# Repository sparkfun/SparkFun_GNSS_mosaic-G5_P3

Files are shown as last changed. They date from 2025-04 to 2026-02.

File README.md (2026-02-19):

SparkFun Allband GNSS RTK Breakout - mosaic-G5 P3
========================================

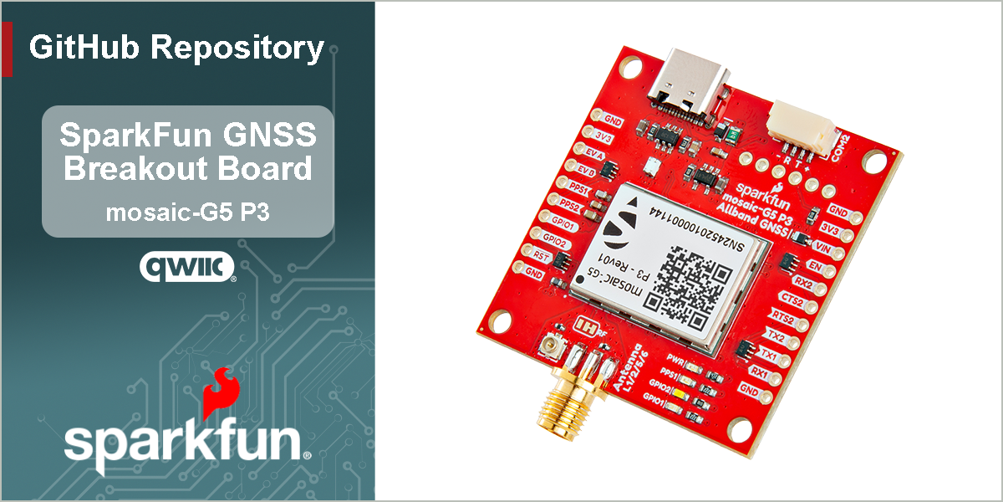
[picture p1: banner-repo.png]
SparkFun Allband GNSS RTK Breakout - mosaic-G5 P3


[*SparkFun Allband GNSS RTK Breakout - mosaic-G5 P3 (GPS-29208)*](https://www.sparkfun.com/sparkfun-allband-gnss-rtk-breakout-mosaic-g5-p3.html)

This SparkFun Allband GNSS RTK Breakout features the Septentrio mosaic-G5 P3 GNSS module, a 60% smaller and 40% lower power consumption variant of the mosaic-X5 GNSS module, making it ideal for drone and IoT applications. The receiver supports the GPS (USA), GLONASS (Russia), Beidou (China), Galileo (Europe), and QZSS (Japan) GNSS constellations, including regional systems *(i.e. SBAS)*. With its Real-Time Kinematics (RTK) capabilities, the module can achieve a horizontal accuracy of 6mm (~0.25in), vertical accuracy of 1cm (~0.4in), PPS timing resolution of 1.4ns (1.4 billionths of a second), and event trigger accuracy below 3ns. It also features Septentrio's unique [AIM+ technology](https://www.septentrio.com/en/learn-more/advanced-positioning-technology/aim-jamming-protection) for interference mitigation and anti-spoofing, ensuring best-in-class reliability and scalable position accuracy.

The mosaic-G5 P3 GNSS module supports USB 2.0 communication and two UART interfaces; along with two GPIO, two configurable PPS outputs, and two event trigger input pins. Users can control and configure the GNSS module through a command-line interface (CLI) using the Septentrio Binary Format (SBF), NMEA, and RTCM v3.x protocols. Otherwise, users can also configure the GNSS module with Septentrio's [RxTools software application](https://www.septentrio.com/en/products/gps-gnss-receiver-software/rxtools). On the board, the `UART2` interface is also broken out to a locking JST connector and BlueSMiRF PTH header pins to attach an RF transceiver for RTK corrections.

Documentation
-------------

- **[Hookup Guide (mkdocs)](http://docs.sparkfun.com/SparkFun_GNSS_mosaic-G5_P3/)** - A hookup guide for the SparkFun mosaic-G5 P3 GNSS breakout board hosted by GitHub pages.<br>
   

Repository Contents
-------------------

- **[/docs](/docs/)** - Online documentation files
  - [/assets](/docs/assets/) - Assets files
    - [/3d_model](/docs/assets/3d_model/) - 3D models for the board
    - [/board_files](/docs/assets/board_files/) - Design files for the board
      - [KiCad Design Files](/docs/assets/board_files/kicad_files.zip) (.zip)
      - [Schematic](/docs/assets/board_files/schematic.pdf) (.pdf)
      - [Dimensions](/docs/assets/board_files/dimensions.pdf) (.pdf)
    - [/component_documentation](/docs/assets/component_documentation/) - Datasheets for hardware components
    - [/img/hookup_guide](/docs/assets/img/hookup_guide/) - Images for hookup guide documentation - Hookup guide images for the board
    - /Hardware - Hardware design files (.brd, .sch)
      - /Production - Production files

Product Variants
----------------

- mosaic-G5 P3:
  - [GPS-29208](https://www.sparkfun.com/sparkfun-allband-gnss-rtk-breakout-mosaic-g5-p3.html) - Allband GNSS RTK Breakout - mosaic-G5 P3
  - Flex Modules:
    - [GPS-29209](https://www.sparkfun.com/sparkpnt-gnss-flex-module-mosaic-g5-p3.html) - GNSS Flex module - mosaic-G5 P3
    - [GPS-29363](https://www.sparkfun.com/sparkpnt-gnss-flex-module-mosaic-g5-p3-im19-imu.html) - GNSS Flex module - mosaic-G5 P3 & IM19
    - [GPS-](https://www.sparkfun.com/sparkfun-gnss-flex-phat-mosaic-g5-p3.html) - GNSS Flex pHAT w/ the mosaic-G5 P3 GNSS Flex module
    - [GPS-](https://www.sparkfun.com/sparkfun-gnss-flex-phat-mosaic-g5-p3-im19-imu.html) - GNSS Flex pHAT w/ the mosaic-G5 P3 & IM19 GNSS Flex module
- mosaic-X5:
  - [GPS-23088](https://www.sparkfun.com/sparkfun-triband-gnss-rtk-breakout-mosaic-x5.html) - Triband GNSS RTK Breakout - mosaic-X5
  - [GPS-23748](https://www.sparkfun.com/sparkfun-rtk-mosaic-x5.html) - RTK mosaic-X5
  - [GPS-24903](https://www.sparkfun.com/sparkpnt-rtk-facet-mosaic-l-band.html) - SparkPNT RTK Facet mosaic L-Band
  - Flex Modules:
    - [GPS-28138](https://www.sparkfun.com/sparkpnt-gnss-flex-module-mosaic-x5.html) - GNSS Flex module - mosaic-X5
    - [GPS-29457](https://www.sparkfun.com/sparkpnt-gnss-flex-module-mosaic-x5-im19-imu.html) - GNSS Flex module - mosaic-X5 & IM19
    - [GPS-28766](https://www.sparkfun.com/sparkfun-gnss-flex-phat-mosaic-x5.html) - GNSS Flex pHAT w/ the mosaic-X5 GNSS Flex module
    - [GPS-29889](https://www.sparkfun.com/sparkfun-gnss-flex-phat-mosaic-x5-im19-imu.html) - GNSS Flex pHAT w/ the mosaic-X5 & IM19 GNSS Flex module
- mosaic-T:
  - [GPS-28731](https://www.sparkfun.com/sparkfun-timing-gnss-breakout-mosaic-t.html) - mosaic-T Timing GNSS Breakout
  - [GPS-26289](https://www.sparkfun.com/sparkpnt-gnss-disciplined-oscillator.html) - GNSS Disciplined Oscillator

| | mosaic-G5 P3 | mosaic-X5 | mosaic-T |
| :--- | :--- | :--- | :--- |
| Breakout Board | [GPS-29208](https://www.sparkfun.com/sparkfun-allband-gnss-rtk-breakout-mosaic-g5-p3.html) | [GPS-23088](https://www.sparkfun.com/sparkfun-triband-gnss-rtk-breakout-mosaic-x5.html) | [GPS-28731](https://www.sparkfun.com/sparkfun-timing-gnss-breakout-mosaic-t.html) |
| GNSS Flex Module | [GPS-29209](https://www.sparkfun.com/sparkpnt-gnss-flex-module-mosaic-g5-p3.html)<br>[GPS-30384](https://www.sparkfun.com/sparkfun-gnss-flex-phat-mosaic-g5-p3.html) - pHAT Kit | [GPS-28138](https://www.sparkfun.com/sparkpnt-gnss-flex-module-mosaic-x5.html)<br>[GPS-28766](https://www.sparkfun.com/sparkfun-gnss-flex-phat-mosaic-x5.html) - pHAT Kit | N/A |
| GNSS Flex Module w/ IM19 | [GPS-29363](https://www.sparkfun.com/sparkpnt-gnss-flex-module-mosaic-g5-p3-im19-imu.html)<br>[GPS-30546](https://www.sparkfun.com/sparkfun-gnss-flex-phat-mosaic-g5-p3-im19-imu.html) - pHAT Kit | [GPS-29457](https://www.sparkfun.com/sparkpnt-gnss-flex-module-mosaic-x5-im19-imu.html)<br>[GPS-29889](https://www.sparkfun.com/sparkfun-gnss-flex-phat-mosaic-x5-im19-imu.html) - pHAT Kit | N/A |
| Other | N/A | [GPS-23748](https://www.sparkfun.com/sparkfun-rtk-mosaic-x5.html) - RTK Platform<br>[GPS-24903](https://www.sparkfun.com/sparkpnt-rtk-facet-mosaic-l-band.html) - Facet | [GPS-26289](https://www.sparkfun.com/sparkpnt-gnss-disciplined-oscillator.html) - GNSSDO |

Version History
---------------

- [v10](https://github.com/sparkfun/SparkFun_GNSS_mosaic-G5_P3/releases/tag/v10) - Initial Release

License Information
-------------------

This product is ***open source***!

Please review the [`LICENSE.md`](./LICENSE.md) file for license information.

If you have any questions or concerns about licensing, please contact technical support on our [SparkFun forums](https://community.sparkfun.com/).

Distributed as-is; no warranty is given.

- Your friends at SparkFun.

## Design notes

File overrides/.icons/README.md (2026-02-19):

.icons directory
====================
This folder should contain branding logos for the product documentation

## General Images
- `sfe.svg` - SparkFun flame logo
- `kicad-primary.svg` - Full KiCad logo

## Directory
- `logo` - Other available logos

## SVG Optimizer
- [Remove meta data from svg](https://jakearchibald.github.io/svgomg/)

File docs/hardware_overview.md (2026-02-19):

??? danger "Important: Read Before Use!"
	!!! warning "ESD Sensitivity"
		The mosaic-G5 P3 GNSS receiver is sensitive to [ESD](https://en.wikipedia.org/wiki/Electrostatic_discharge "Electrostatic Discharge"). Use a proper grounding system to make sure that the working surface and the components are at the same electric potential.

		??? info
			As recommended by the manufacturer, we highly recommend that users take the necessary precautions to avoid damaging their GNSS receiver.

			- The All-band GNSS RTK breakout board features ESD protection on the USB-C connector and breakout's I/O:
				- USB data lines
				- I/O PTH pads
				- JST connector and BlueSMiRF header pins
			- The mosaic-G5 P3 GNSS receiver features internal ESD protection to the `ANT_1` antenna input.

			<div markdown>

			<article class="video-500px" style="margin: auto;" markdown>
			<iframe src="https://www.youtube.com/embed/hrL5J6Q5gX8?si=jOPBat8rzMnL7Uz4&amp;start=26;&amp;end=35;" title="Septentrio: Getting Started Video (playback starts at ESD warning)" frameborder="0" allow="accelerometer; autoplay; clipboard-write; encrypted-media; gyroscope; picture-in-picture" allowfullscreen></iframe>
			</article>

			</div>

	!!! warning "Active Antenna"
		Never inject an external DC voltage into the SMA connector for the GNSS antenna, as it may damage the mosaic-G5 P3 GNSS receiver. For instance, when using a splitter to distribute the antenna signal to several GNSS receivers, make sure that no more than one output of the splitter passes DC. Use [DC-blocks](https://en.wikipedia.org/wiki/DC_block) otherwise.

## :material-folder-cog: Design Files
<!-- Import the component -->
<script type="module" src="https://ajax.googleapis.com/ajax/libs/model-viewer/3.5.0/model-viewer.min.js"></script>

<div class="grid cards desc" markdown>

-   :kicad-primary:{ .enlarge-logo } Design Files

	---

	- :fontawesome-solid-file-pdf: [Schematic](./assets/board_files/schematic.pdf)
	- :material-folder-zip: [KiCad Files](./assets/board_files/kicad_files.zip)
	- :material-rotate-3d: [STEP File](./assets/3d_model/cad_model.step)
	- :fontawesome-solid-file-pdf: [Board Dimensions](./assets/board_files/dimensions.pdf):
		- 1.70" x 1.70" (43.2mm x 43.2mm)

-   <!-- Boxes in tabs -->

	=== "3D Model"
		<article style="text-align: center;" markdown>
		<model-viewer src="../assets/3d_model/web_model.glb" camera-controls poster="../assets/3d_model/poster.png" tone-mapping="neutral" shadow-intensity="2" shadow-softness="0.2" camera-orbit="0deg 75deg 0.103m" field-of-view="25.11deg" style="width: 100%; height: 450px;">
		</model-viewer>

		[Download the `*.step` File](./assets/3d_model/cad_model.step "Click download"){ .md-button .md-button--primary width="250px" }

		</article>

		???+ tip "Manipulate 3D Model"
			<article style="text-align: center;" markdown>

			| Controls       | Mouse                    | Touchscreen    |
			| :------------- | :----------------------: | :------------: |
			| Zoom           | Scroll Wheel             | 2-Finger Pinch |
			| Rotate         | ++"Left-Click"++ & Drag  | 1-Finger Drag  |
			| Move/Translate | ++"Right-Click"++ & Drag | 2-Finger Drag  |

			</article>

	=== "Dimensions"
		<article style="text-align: center;" markdown>
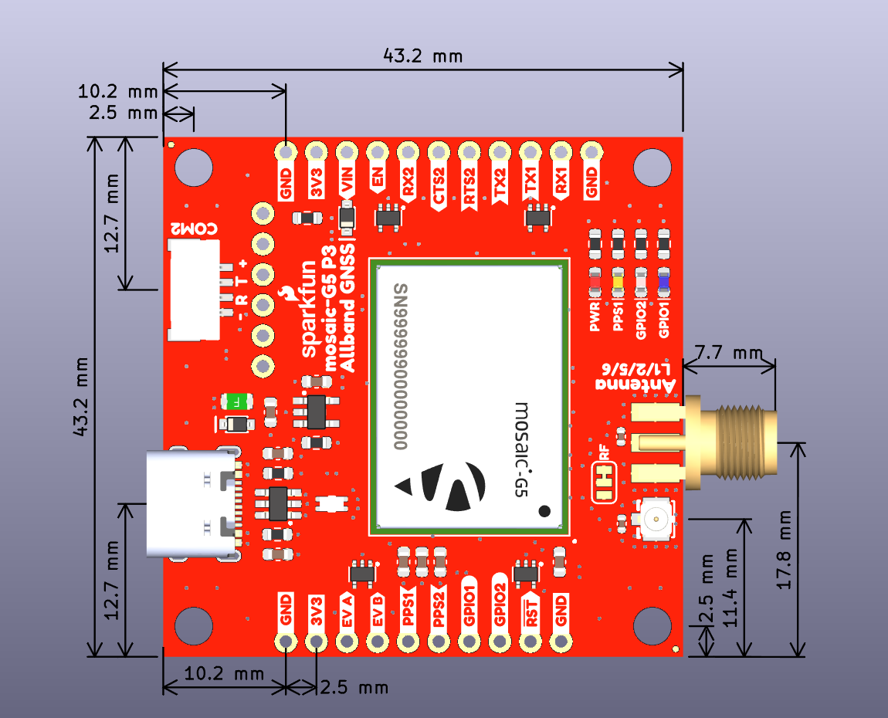
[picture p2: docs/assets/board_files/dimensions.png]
Board Dimensions
		
		<figcaption markdown>Dimensions of the mosaic-G5 P3 GNSS breakout board.</figcaption>
		</article>

		???+ tip "Need more measurements?"
			For more information about the board's dimensions, users can download the [KiCad files](./assets/board_files/kicad_files.zip) for this board. These files can be opened in KiCad and additional measurements can be made with the measuring tool.

			!!! info ":octicons-download-16:{ .heart } KiCad - Free Download!"
				KiCad is free, open-source [CAD]("computer-aided design") program for electronics. Click on the button below to download their software. *(\*Users can find out more information about KiCad from their [website](https://www.kicad.org/).)*

				<article style="text-align: center;" markdown>
				[Download :kicad-primary:{ .enlarge-logo }](https://www.kicad.org/download/ "Go to downloads page"){ .md-button .md-button--primary width="250px" }
				</article>

			???+ info ":straight_ruler: Measuring Tool"
				This video demonstrates how to utilize the dimensions tool in KiCad, to include additional measurements:

				<article class="video-500px" style="text-align: center; margin: auto;" markdown>
				<iframe src="https://www.youtube.com/embed/-eXuD8pkCYw" title="KiCad Dimension Tool" frameborder="0" allow="accelerometer; autoplay; clipboard-write; encrypted-media; gyroscope; picture-in-picture" allowfullscreen></iframe>
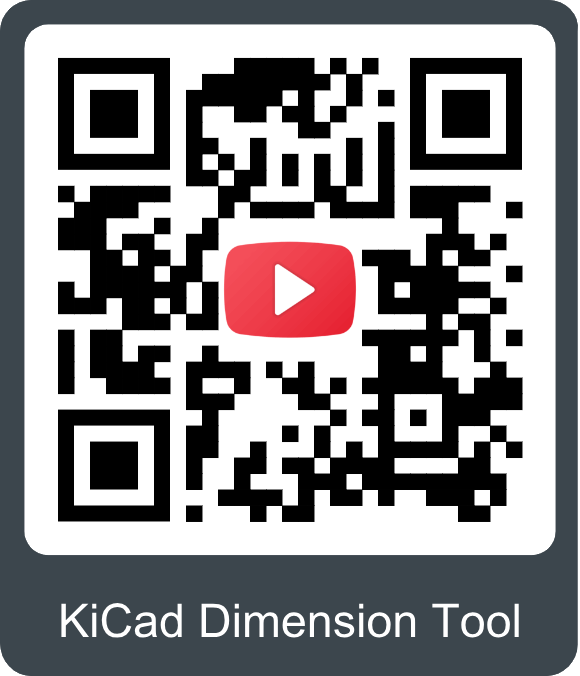
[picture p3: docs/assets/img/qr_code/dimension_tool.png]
QR code to play video
				
				</article>

</div>

## Board Layout
The SparkFun Allband GNSS RTK Breakout - mosaic-G5 P3 features the following:

<div class="grid" markdown>

<div markdown>

<figure markdown>
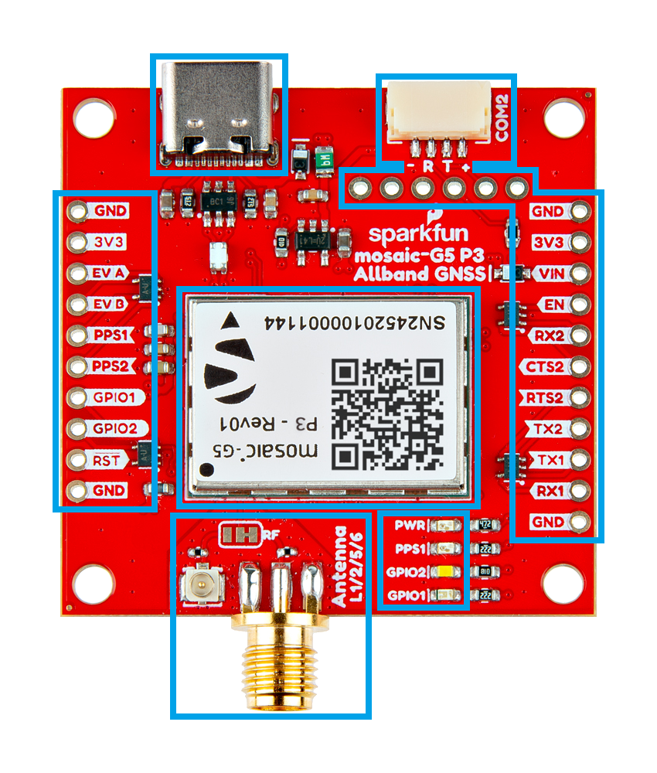
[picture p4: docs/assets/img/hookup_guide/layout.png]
Layout

<figcaption markdown>Layout of the major components on the breakout board.</figcaption>
</figure>

</div>

<div markdown>

1. **[USB-C Connector](#usb-c-connector)**
:   The primary inteface for powering and interacting with the board
1. **[mosaic-G5 P3 GNSS Receiver](#mosaic-g5-p3)**
:   The Septentrio mosaic-G5 P3 GNSS receiver
1. **Header Pins**
:   Exposes pins to [power the board](#power) and breaks out the [interfaces of the mosaic-G5 P3 GNSS receiver](#peripherals-and-io-pins)
1. **[BlueSMiRF Header Pins](#bluesmirf-header)**
:   Exposes the `UART2` interface of the mosaic-G5 P3 GNSS receiver
1. **[JST Connector](#jst-connector)**
:   Exposes the `UART2` interface of the mosaic-G5 P3 GNSS receiver
1. **[Status LEDs](#status-leds)**
:   LED status indicators for the mosaic-G5 P3 GNSS receiver
1. **[`Antenna L1/2/5/6` RF Connectors](#antenna-connections)**
:   SMA and U.FL *(optional)* connectors for an external GNSS antenna

</div>

</div>

## USB-C Connector
The USB connector is provided to power and interface with the mosaic-G5 P3 GNSS receiver. For most users, it will be the primary method for communicating with the GNSS receiver.

<figure markdown>
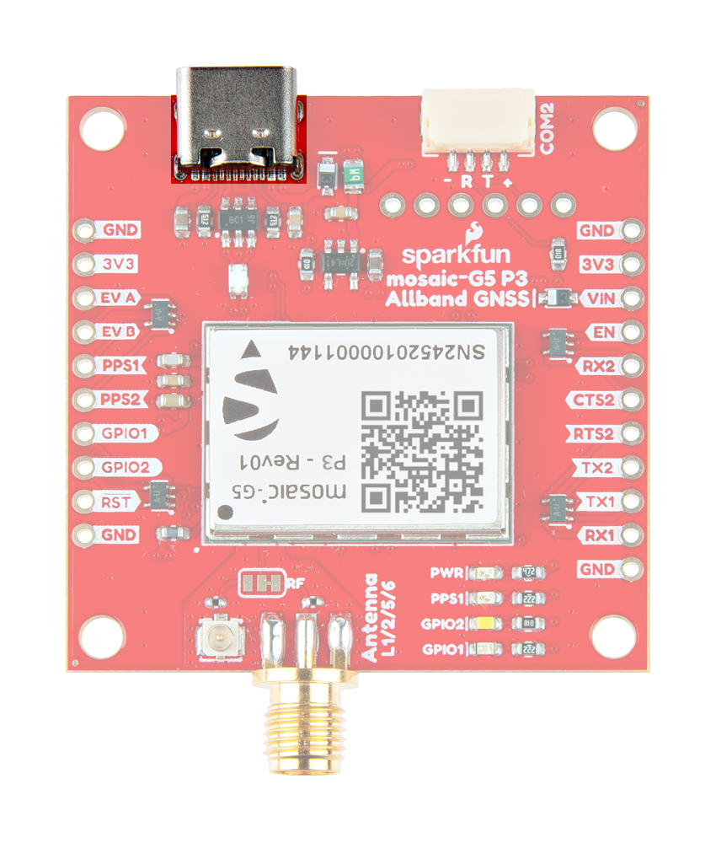
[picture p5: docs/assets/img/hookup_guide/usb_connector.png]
USB-C Connector

<figcaption markdown>USB-C connector on the All-band GNSS RTK breakout board.</figcaption>
</figure>

## Power
The All-band GNSS RTK breakout board only requires **3.3V** to power all of the board's components. The simplest method to power the board is through the USB-C connector. Alternatively, the board can also be powered through the **`VIN`** pin.

<figure markdown>
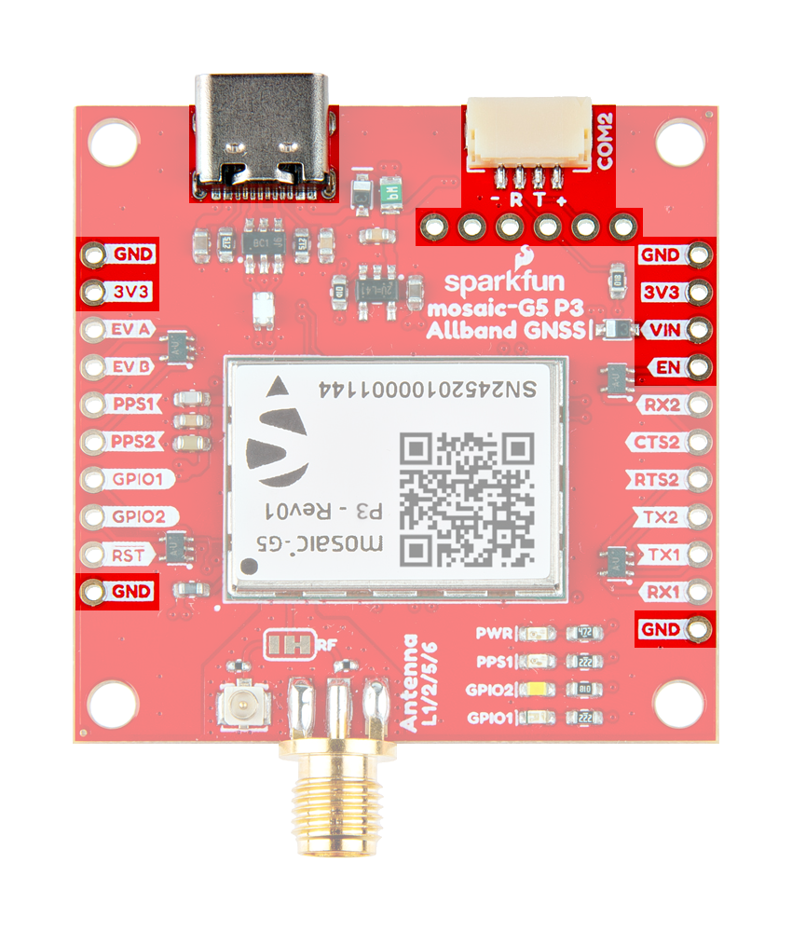
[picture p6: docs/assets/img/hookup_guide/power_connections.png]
Power connections

<figcaption markdown>All-band GNSS RTK breakout board's power connections.</figcaption>
</figure>

Below, is a general summary of the power circuitry on the board, broken out as [PTH](https://en.wikipedia.org/wiki/Through-hole_technology "Plated Through Holes") pins:

<div class="annotate" markdown>

- **`VUSB`** - The voltage from the USB-C connector, usually **5V**
	- Input Voltage Range: 4.4 - 5.5 V
	- Power source for the entire board
		- Powers the 3.3V voltage regulator (RT9080), which can source up to 600mA
		- When enabled, it can also power the [BlueSMiRF header](#bluesmirf-header) and [JST connector](#jst-connector) *(see the **[Jumpers](#jumpers)** section)*
- **`VIN`** - Alternate input supply voltage for the board
	- Input Voltage Range: 1.2 - 5.5V (1)
	- Power source for the entire board
		- Powers the 3.3V voltage regulator (RT9080), which can source up to 600mA
		- When enabled, it can also power the [BlueSMiRF header](#bluesmirf-header) and [JST connector](#jst-connector) *(see the **[Jumpers](#jumpers)** section)*
- **`3V3`** - Provides a regulated 3.3V from the [RT9080](./assets/component_documentation/RT9080.pdf), using the power supplied from the `VIN` pin or USB-C connector
	- Used to power the mosaic-G5 P3 GNSS receiver and its active antenna preamplifier, the LEDs, and the power pin of the [JST connector](#jst-connector) and [BlueSMiRF header](#bluesmirf-header)
	- Controlled by the `EN` pin, which is enabled by default
- **`EN`** - Enables the voltage output from the [RT9080](./assets/component_documentation/RT9080.pdf), 3.3V voltage regulator
	- Enabled by default *(active `HIGH`)*
- **`RST`** - Used to reset the mosaic-G5 P3 GNSS receiver
	- Connected to the `nRST_IN` input-only pin with an internal pull-up resistor
	- Driving the pin `LOW` triggers the restart of the mosaic-G5 P3 GNSS receiver
- **`GND`** - The common ground or the 0V reference for the voltage supplies.

</div>

1. While the [RT9080](./assets/component_documentation/RT9080.pdf) LDO regulator has an input voltage range of 1.2 - 5.5V, a minimum supply voltage of **3.5V** is recommended for a 3.3V output.

!!! tip "JST Connector"
	The `VSEL` pin of the [BlueSMiRF header](#bluesmirf-header) and `+` pin of the [JST connector](#jst-connector) are designed to operate as a voltage output. An input voltage can be supplied through these pins; however, users should be mindful of any voltage contention issues. Additionally, users can modify the [`VSEL` jumper](#jumpers) to change the output voltage level of these pins.

!!! info
	For more details, users can reference the [schematic](./assets/board_files/schematic.pdf) and the datasheets of the individual components on the board.

### Power Consumption
The power consumption of the mosaic-G5 P3 GNSS receiver depends on the GNSS signals enabled and the positioning mode. The table below, lists the average power consumption for common configurations. The current listed, is based on a supply voltage of 3.3V.

<article style="text-align: center;" markdown>

| GNSS Signals | Power (mW) | Current (mA) |
| :--- | :---: | :---: |
| GPS/GLONASS L1/L2 | 440 | 133 |
| All signals from all GNSS constellations | 570 | 173 |
| All signals from all GNSS constellations +L-band | 670 | 203 |

*Source: [mosaic-G5 P3 Hardware Manual](./assets/component_documentation/mosaic-g5_hardware_manual_v1.1.1.pdf)*
</article>

## :fontawesome-solid-microchip:&nbsp; mosaic-G5 P3
The centerpiece of the All-band GNSS RTK breakout board, is the [mosaic-G5 P3 GNSS receiver](./assets/component_documentation/mosaic-g5_hardware_manual_v1.1.1.pdf) from [Septentrio](https://www.septentrio.com/en). Their mosaic-G5 P3 modules are low-power, multi-band, multi-constellation GNSS receivers capable of delivering centimeter-level precision in a small form factor without compromising on performance. They provide strong positioning reliability in challenging environments and are tailored for applications such as delivery or light show drones. It also features Septentrio's unique [AIM+ technology](https://www.septentrio.com/en/learn-more/advanced-positioning-technology/aim-resilient-and-secure-gnss/gps-receivers) for interference mitigation and anti-spoofing, which ensures their best-in-class reliability and scalable position accuracy.

<div class="grid cards" markdown>

<div markdown>

<article class="video-500px" style="margin: auto;" markdown>
<iframe src="https://www.youtube.com/embed/3VzVxTTvF5Q" title="Septentrio mosaic range: high-accuracy GNSS receivers for drones &amp; robotics" frameborder="0" allow="accelerometer; autoplay; clipboard-write; encrypted-media; gyroscope; picture-in-picture" allowfullscreen></iframe>
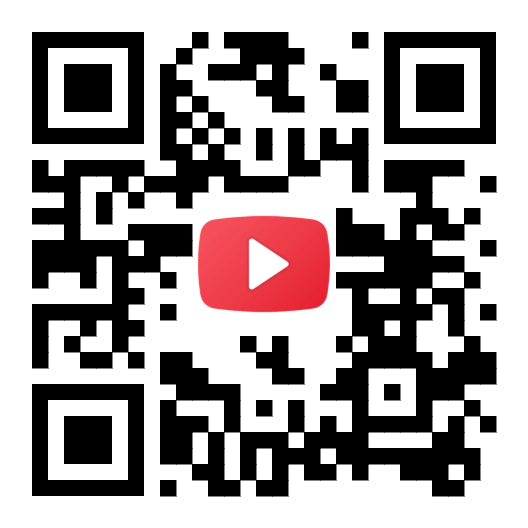
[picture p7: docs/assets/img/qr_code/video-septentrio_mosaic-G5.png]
QR code to play video

</article>

</div>

-   <figure markdown>
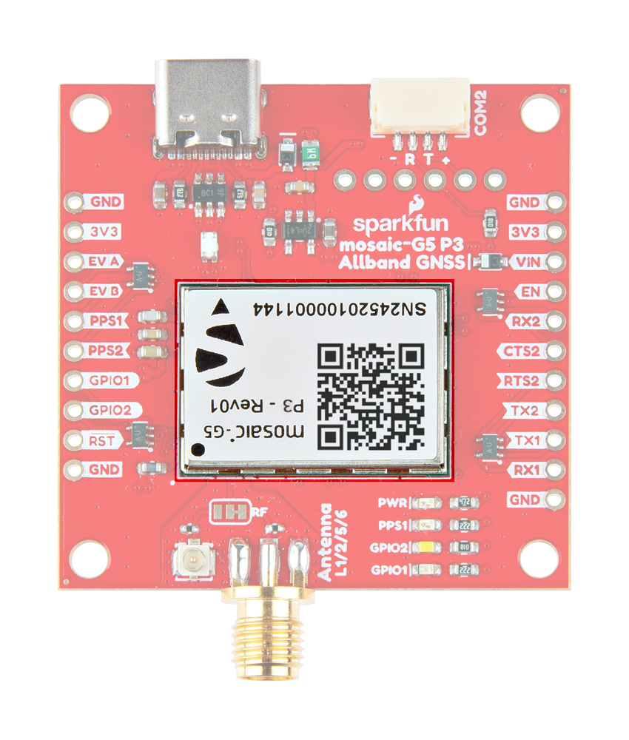
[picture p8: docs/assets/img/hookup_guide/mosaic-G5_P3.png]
mosaic-G5 P3 GNSS receiver
	
	<figcaption markdown>The mosaic-G5 P3 GNSS receiver on the All-band GNSS RTK breakout board.</figcaption>
	</figure>

</div>

<div class="grid" markdown>

<div markdown>

**Features:**

- Operating Voltage: **3.135 - 3.465V**
- GNSS Support
	- GPS: `L1C/A`, `L1C`, `L2C`, `L2PY`, `L5`
	- GLONASS: `L1CA`, `L2CA`, `L2P`, `L3 CDMA`
	- Beidou: `B1I`, `B1C`, `B2a`, `B2b`, `B2I`, `B3I`
	- Galileo: `E1`, `E5a`, `E5b`, `E6`
	- QZSS: `L1C/A`, `L1 C/B`, `L2C`, `L5`, `L6`
- Time to Fix
	- Cold Start: < 35s
	- Warm: < 10s
	- Reacquisition: 1s
- Position Accuracy
	<article style="text-align: center;" markdown>

	| Correction | Horizontal                             | Vertical                     |
	| :--------- | :------------------------------------: | :--------------------------: |
	| RTK        | **0.6cm** *(&plusmn;0.5ppm)*<br>~0.25" | 1cm *(&plusmn;1ppm)*<br>~.4" |
	| DGNSS      | 40cm<br>~1.3'                          | 70cm<br>~2.3'                |
	| Standalone | 1.2m<br>~4'                            | 1.9m<br>~6.2'                |

	</article>

</div>

<div markdown>

<br>

- Update Rate: 20Hz
- Latency: < 10ms
- Event Accuracy: < 3ns
- Interfaces:
	- UART (x2)
	- USB device (2.0, HS)
	- GPIO user programmable (x2)
	- Event markers (x2)
	- Configurable PPS out (x2)
- Protocols:
	- Septentrio Binary Format (SBF)
	- NMEA 0183, v2.3, v3.03, V4.0
	- RTCM v3.x (MSM included)
- Antenna Specifications
	- Preamplification Range: 15-50dB
	- Bias Voltage: 3.0 - 5.5V
	- 789 Hardware Channels
- Operating Temperature: -40 - 85&deg;C
- Package Size: 16.4mm x 22.8mm x 2.4mm
- Weight: 2.2g

</div>

</div>

!!! tip
	The capabilities of each receiver is defined by a the optional features that are enabled. The capabilities of the receiver depend on a combination of the hardware model and version, the firmware version, and the set of permissions enabled for the optional features. Permissions are further explained in section 1.17. The command `getReceiverCapabilities` will list the receiver's capabilities. Otherwise, using RxControl (go to **Help** > **Receiver Interface** > **Permitted Capabilities**).

### Frequency Bands
The mosaic GNSS receivers are multi-band, multi-constellation GNSS receivers. Below, are charts illustrating the frequency bands utilized by all the global navigation satellite systems and the ones supported by the mosaic-G5 P3 GNSS receiver.

<figure markdown>
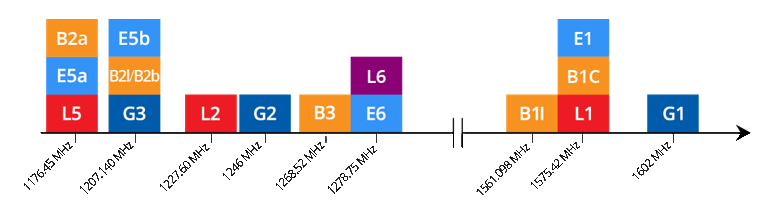
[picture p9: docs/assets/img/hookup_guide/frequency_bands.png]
Supported frequency bands

<figcaption markdown>The frequency bands supported by the mosaic-G5 P3 GNSS receiver.</figcaption>
</figure>

<figure markdown>
GNSS frequency bands (https://www.tallysman.com/app/uploads/2021/07/Tallysman-GNSS-Frequencies-v8.0_Chart-1-1024x425.png "Click to enlarge")
<figcaption markdown>Frequency bands of the global navigation satellite systems. (Source: [Tallysman](https://www.tallysman.com/gnss-constellations-radio-frequencies-and-signals/))</figcaption>
</figure>

!!! info
	For a comparison of the frequency bands supported by the mosaic GNSS receivers, refer to section **3.1** of the [hardware manual](./assets/component_documentation/mosaic-g5_hardware_manual_v1.1.1.pdf).

	??? info "What are Frequency Bands?"
		A [frequency band](https://en.wikipedia.org/wiki/Frequency_band) is a section of the [electromagnetic spectrum](https://en.wikipedia.org/wiki/Electromagnetic_spectrum), usually denoted by the range of its upper and lower limits. In the [radio spectrum](https://en.wikipedia.org/wiki/Radio_spectrum), these frequency bands are usually regulated by region, often through a government entity. This regulation prevents the interference of RF communication; and often includes major penalties for any interference with critical infrastructure systems and emergency services.

		<figure markdown>
		GNSS frequency bands (https://gssc.esa.int/navipedia/images/c/cf/GNSS_All_Signals.png "Click to enlarge")
		<figcaption markdown>Frequency bands of the global navigation satellite systems. (Source: [ESA](https://gssc.esa.int/navipedia/index.php?title=File:GNSS_All_Signals.png "European Space Agency"))</figcaption>
		</figure>

		However, if the various GNSS constellations share similar frequency bands, then how do they avoid interfering with one another? Without going too far into detail, the image above illustrates the frequency bands of each system with a few characteristics specific to their signals. Wit these characteristics in mind, along with other factors, the chart can help users to visualize how multiple GNSS constellations might co-exist with each other.

		For more information, users may find these articles of interest:

		- [GNSS signal](https://gssc.esa.int/navipedia/index.php/GNSS_signal)
		- [GPS Signal Plan](https://gssc.esa.int/navipedia/index.php?title=GPS_Signal_Plan)
		- [GLONASS Signal Plan](https://gssc.esa.int/navipedia/index.php?title=GLONASS_Signal_Plan)
		- [GALILEO Signal Plan](https://gssc.esa.int/navipedia/index.php?title=GALILEO_Signal_Plan)

### Position Accuracy
<div class="grid" markdown>

<div markdown>

The accuracy of the position reported from the mosaic-G5 P3 GNSS receiver, can be improved based upon the correction method being employed. Currently, [RTK](https://en.wikipedia.org/wiki/Real-time_kinematic_positioning "Real-Time Kinematic") corrections provide the highest level of accuracy; however, users should be aware of certain limitations of the system:

- RTK technique requires real-time correction data from a reference station or network of base stations.
	- RTK corrections are signal specific *(i.e. an RTK network might provide corrections on only `E5b` and not `E5a`)*.
- The range of the base stations will vary based upon the RTK method being employed.
- The reliability of RTK corrections are inherently reduced in [multipath environments](https://en.wikipedia.org/wiki/Multipath_propagation). However, with Septentrio's multipath mitigation technology ([APME+](https://www.septentrio.com/en/learn-more/Advanced-positioning-technology/gnss-technology/multipath-mitigation-technology "A-Posteriori Multipath Estimation")) on the mosaic-G5 P3, these errors are significantly reduced when compared to multipath mitigation techniques that modify the correlators in the tracking channels.

</div>

<div markdown>

<article style="text-align: center;" markdown>

| Correction | Horizontal | Vertical |
| :--- | :---: | :---: |
| [RTK](https://en.wikipedia.org/wiki/Real-time_kinematic_positioning "Real-Time Kinematic") | **0.6cm** *(&plusmn;0.5ppm)*<br>~0.25" | 1cm *(&plusmn;1ppm)*<br>~.4" |
| [DGNSS](https://en.wikipedia.org/wiki/Differential_GPS "Differential GNSS") | 40cm<br>~1.3' | 70cm<br>~2.3' |
| Standalone | 1.2m<br>~4' | 1.9m<br>~6.2' |

</article>

</div>

</div>

??? info "RTK Corrections"
	To understand how RTK works, users will need a more fundamental understanding of the signal error sources.

	<div class="grid cards" markdown align="center">

	-   <a href="https://www.sparkfun.com/news/7533">
		<figure markdown>
		Tutorial Thumbnail
		</figure>

		---

		**Real-Time Kinematics Explained**</a>

	-   <a href="https://www.sparkfun.com/news/7138">
		<figure markdown>
		Tutorial Thumbnail
		</figure>

		---

		**What is Correction Data?**</a>

	-   <a href="https://www.septentrio.com/en/learn-more/insights/gnss-corrections-demystified">
		<figure markdown>
		Tutorial Thumbnail
		</figure>

		---

		**GNSS Corrections Demystified**</a>

	</div>

!!! tip
	For the best performance, we highly recommend that users configure the GNSS receiver to utilize/provide RTK corrections with a compatible L1/L2/L5/L6 (All-band) GNSS antenna and utilize a low-loss cable.

## Peripherals and I/O Pins
The mosaic-G5 P3 features several peripherals and I/O pins. Some of these are broken out as pins on the All-band GNSS RTK breakout board; whereas, others are broken out to their specific interface *(i.e. USB connector, etc.)*. Additionally, some of their connections are tied to other components on the board.

<div class="grid" markdown>

<div markdown>

<figure markdown>
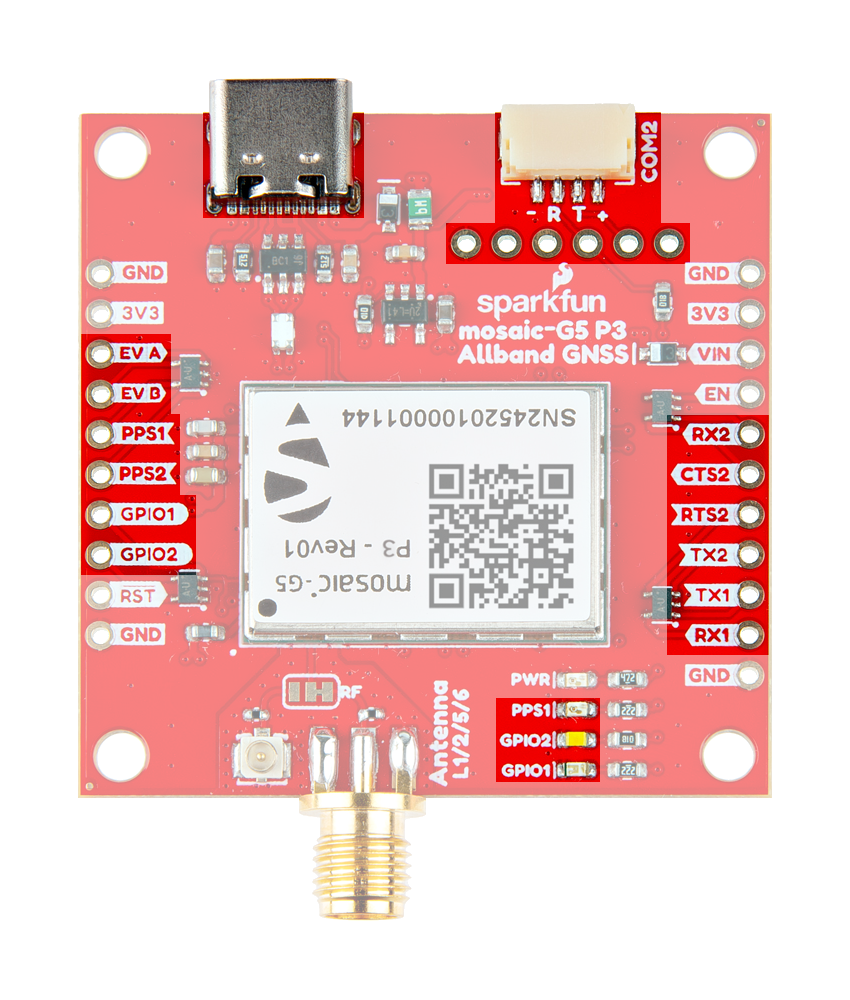
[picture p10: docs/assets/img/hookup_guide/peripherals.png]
Peripherals and I/O pins

<figcaption markdown>The peripherals and I/O pins on the All-band GNSS RTK breakout board.</figcaption>
</figure>

</div>

<article class="annotate" markdown>
**Interfaces:**

- USB device (2.0, HS)
- 2x UART (LVTTL, up to 4 Mbps)
- 2x GPIO user programmable
- 2x Event markers
- 2x Configurable PPS out

</article>

</div>

=== "USB"
	For most users, this will be the primary interface for the mosaic-G5 P3 GNSS receiver.

	<figure markdown>
	USB interface
	<figcaption markdown>USB-C connector on the All-band GNSS RTK breakout board.</figcaption>
	</figure>

	!!! info
		When a GNSS receiver is initially connected to a computer, two virtual `COM` ports are emulated. These can be used as standard `COM` ports to communicate with the GNSS receiver.

=== "UARTs"
	The mosaic-G5 P3 has two dedicated UART interfaces. Each of the UART ports can be configured and operated separately.

	<div class="grid" markdown>

	<div markdown>

	<figure markdown>
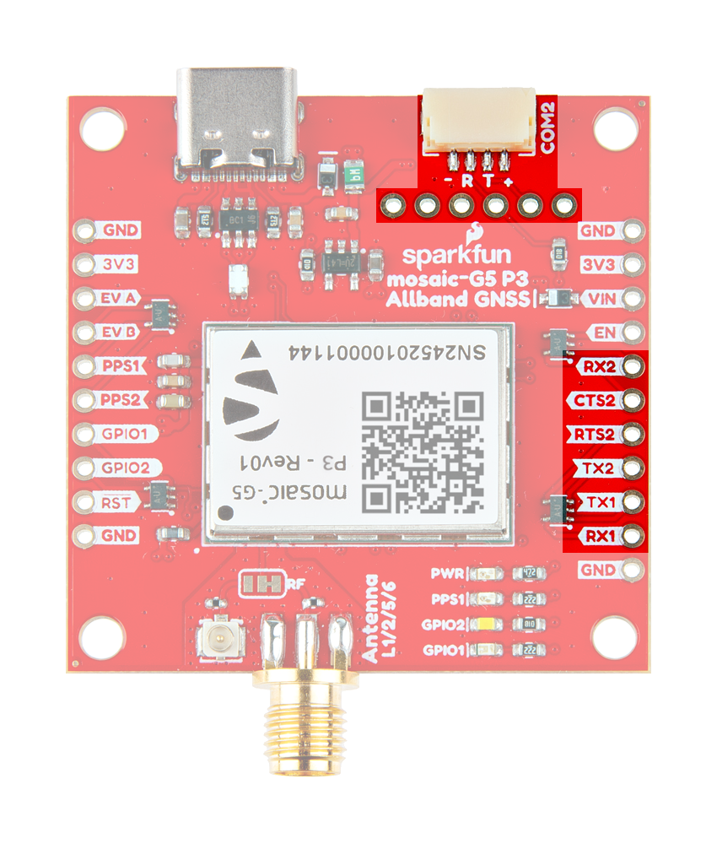
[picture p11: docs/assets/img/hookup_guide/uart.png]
UART interface
	
	<figcaption markdown>The UART ports on the All-band GNSS RTK breakout board.</figcaption>
	</figure>

	</div>

	<div markdown>

	!!! info
		By default, the UART ports are configured with the following settings:

		- Baudrate: 115200bps
		- Data Bits: 8
		- Parity: No
		- Stop Bits: 1
		- Flow Control: None

		The COM port settings are set with the `setCOMSettings` command.

		!!! tip "`UART2`"
			The `UART2` or `COM2` interface features flow control pins, which are disabled by default. The interface can also be accessed through the [JST connector](#jst-connector) and/or [BlueSMiRF header](#bluesmirf-header).

			!!! warning "Bus Contention"
				To avoid [bus contention](https://en.wikipedia.org/wiki/Bus_contention) issues, make sure only one device is connected to any of these options.

	</div>

	</div>

	??? tip "Pin Connections"
		When connecting to the board's UART pins, the pins should be connected based upon the flow of their data. For example, when utilizing the [Telemetry Radio](https://www.sparkfun.com/sik-telemetry-radio-v3-915mhz-100mw.html) or the [LoRaSerial Kit](https://www.sparkfun.com/sparkfun-loraserial-kit-915mhz-enclosed.html):

		<figure markdown>
		Flow Control (https://docs.sparkfun.com/SparkFun_LoRaSerial/img/SAMD21%20Flow%20control.png "Click to enlarge")
		<figcaption markdown>Connection of the UART pins from the [LoRaSerial radio](https://www.sparkfun.com/sparkfun-loraserial-kit-915mhz-enclosed.html) to a host system, like the All-band GNSS RTK breakout board.</figcaption>
		</figure>

=== "PPS Output"
	The 3.3V [PPS](https://en.wikipedia.org/wiki/Pulse-per-second_signal "Pulse Per Second") signals can be access through the `PPSx` pins. The polarity, frequency, and pulse width of these signals can be configured with the `setPPSParameters` and `setPPS2Parameters` commands.

	<div class="grid" markdown>

	<div markdown>

	<figure markdown>
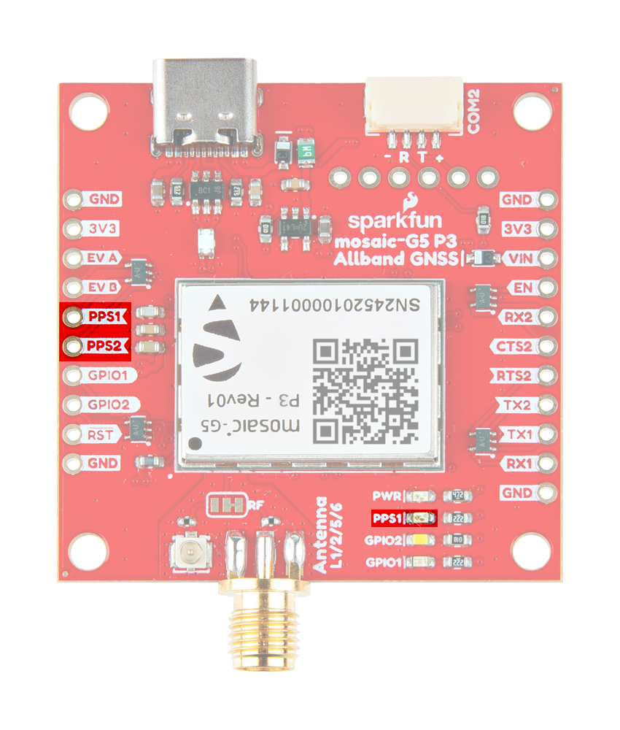
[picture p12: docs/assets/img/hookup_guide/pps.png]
I/O for PPS signal
	
	<figcaption markdown>The `PPS` signal outputs on the All-band GNSS RTK breakout board.</figcaption>
	</figure>

	</div>

	<div markdown>

	!!! info
		During module startup, these pins are first in high-Z mode for about 1s. Then they are driven low for another second before being driven to the intended user-selected level about 2s after powering up the module.

	!!! tip "GPIO Pins"
		It is possible to use these pins as general-purpose I/O pins, but their maximum current limited to 8mA.

	!!! tip "`PPS1` LED"
		The `PPS1` signal is connected to the `PPS` LED, to be used as a visual indicator. There is also `PPS1` jumper attached to the `PPS` LED. For low power applications, the [jumper](#jumpers) can be cut to disable the `PPS` LED.

	</div>

	</div>

=== "GPIO Pins"
	The mosaic-G5 P3 GNSS receiver features two general purpose I/O pins. These pins have a maximum output current of 16 mA and pulled-up by default. These pins are also connected to the `GPIO1` and `GPIO2` [status LEDs](#status-leds), whose function (level or LED status indicator) can be programmed with the `setGPIO1Mode` and `setGPIO2Mode` commands.

	<div class="grid" markdown>

	<div markdown>

	<figure markdown>
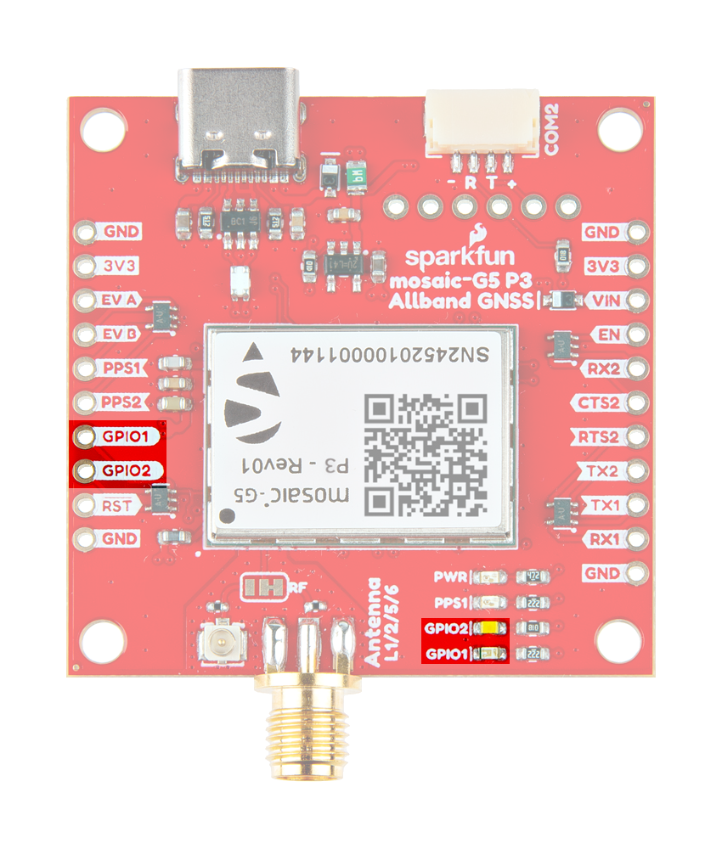
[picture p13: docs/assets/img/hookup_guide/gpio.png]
	
	<figcaption markdown>The GPIO pins and LEDs on the All-band GNSS RTK breakout board.</figcaption>
	</figure>

	</div>

	<div markdown>

	Along with its polarity, the output signal from these pins can be used to indicate one of the following [status modes](#status-leds):

	- `PVTLED`: LED lights when a PVT solution is available.
	- `RTKLED`: LED is off if the PVT is not in RTK mode, blinks in float RTK and is solid on in fixed RTK.
	- `TRACKLED`: Tracked satellite indicator.
	- `DIFFCORRLED`: Differential correction indicator.
		- In rover PVT mode, this LED reports the number of satellites for which differential corrections have been provided in the last received differential correction message (RTCM or CMR).
		- If the corrections are received from geostationary satellites over the L-band, the LED will be on for about 1 second, then blink fast twice.

	!!! info
		By default, these pins are configured in input mode with pull-up. Also, for about 2 seconds after powering or resetting the module, these pins are in input mode (pulled up) regardless of the user configuration stored in the boot configuration file.

	!!! tip "LED Jumpers"
		There are jumpers attached to the `GPIOx` LEDs. For low power applications, the [jumpers](#jumpers) can be cut to disable their respective LED.

	</div>

	</div>

=== "Event Pins"
	The mosaic-G5 P3 GNSS receiver features two event input pins, which can be used to time tag external events with a time resolution of 3ns. Use the `setEventParameters` command to configure these pins.

	<div class="grid" markdown>

	<div markdown>

	<figure markdown>
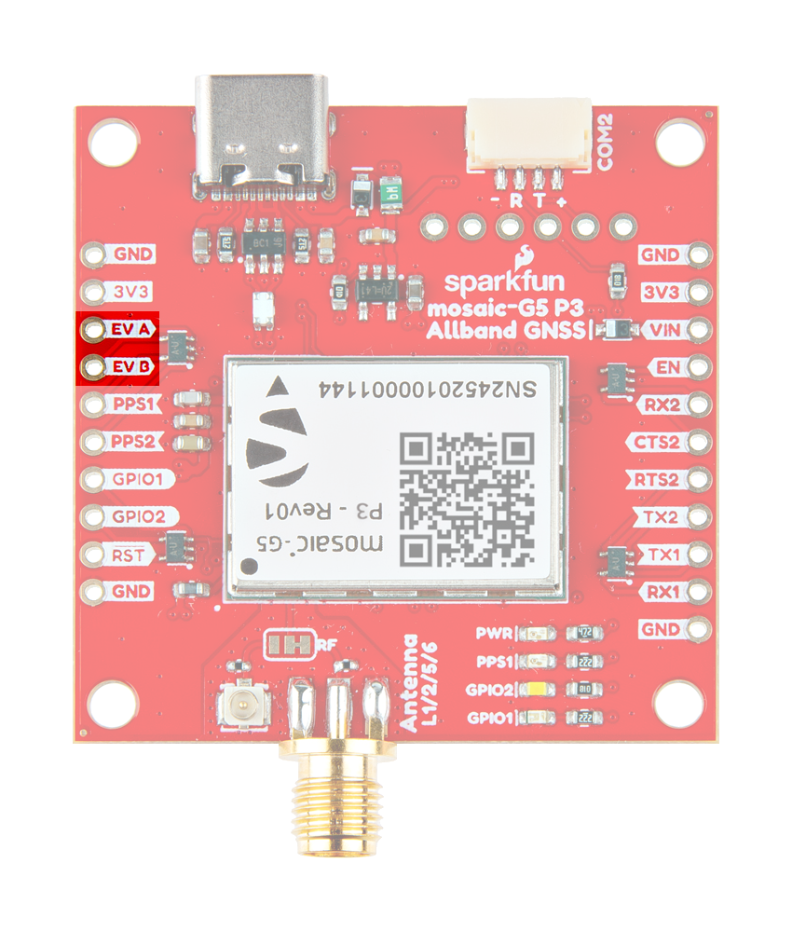
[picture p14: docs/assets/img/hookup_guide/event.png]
	
	<figcaption markdown>The event pins on the All-band GNSS RTK breakout board.</figcaption>
	</figure>

	</div>

	<div markdown>

	!!! tip
		To properly detect event triggers:

		- There must be a minimum of 5ms between two events on the same `EVENTx` pin
		- There must be no more than 20 events in any interval of 100ms, on all the `EVENTx` pins

	</div>

	</div>

### BlueSMiRF Header
The All-band GNSS RTK breakout features a 6-pin BlueSMiRF [PTH](https://en.wikipedia.org/wiki/Through-hole_technology "Plated Through Holes") header that is compatible with may of our serial devices (i.e. [UART adapters](https://www.sparkfun.com/categories/349), [*serial* data loggers](https://www.sparkfun.com/categories/589),[BlueSMiRF v2](https://www.sparkfun.com/sparkfun-bluesmirf-v2.html) Bluetooth^&reg;^ serial link, and microcontrollers). Users can access the [`UART2` interface](#uarts) of the mosaic-G5 P3 GNSS receiver through the BlueSMiRF header pins.

<div class="grid" markdown>

<figure markdown>
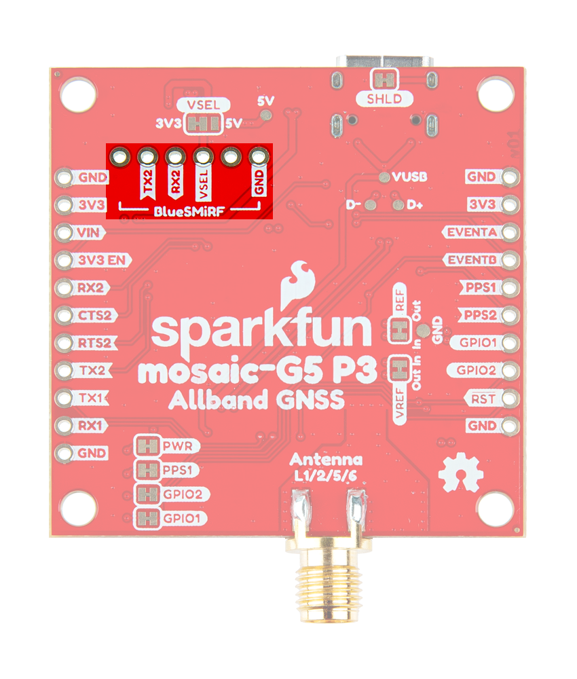
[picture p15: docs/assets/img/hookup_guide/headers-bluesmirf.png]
BlueSMiRF header

<figcaption markdown>The 6-pin BlueSMiRF PTH header on the All-band GNSS RTK breakout board.</figcaption>
</figure>

<div markdown>

!!! info
	By default, the UART ports are configured with the following settings:

	- Baudrate: 115200bps
	- Data Bits: 8
	- Parity: No
	- Stop Bits: 1
	- Flow Control: None

	The COM port settings are set with the `setCOMSettings` command.

	!!! tip "`UART2`"
		The `UART2` or `COM2` interface features flow control pins, which are disabled by default. The interface can also be accessed through the [JST connector](#jst-connector) and/or [PTH pins](#uarts).

		!!! warning "Bus Contention"
			To avoid [bus contention](https://en.wikipedia.org/wiki/Bus_contention) issues, make sure only one device is connected to any of these options.

</div>

</div>

!!! danger "`VSEL` Pin"
	By default, the power pin *(i.e. `VSEL` or Pin 4)* of the BlueSMiRF header is connected to **3.3V** and configured as a power output. An input voltage can be supplied through the pin; however, users should be mindful of any voltage contention issues.

	???+ tip "Jumper"
		By default, the [`VSEL` jumper](#jumpers) is connected to `3V3` pad for a regulated 3.3V output. However, users can modify the jumper to utilize the voltage supplied from either the USB or `VIN` inputs.

### JST Connector
The All-band GNSS RTK breakout features a 4-pin [JST GH connector](./assets/component_documentation/JST-GH_datasheet.pdf), which is polarized and locking. Users can access the [`UART2` interface](#uarts) of the mosaic-G5 P3 GNSS receiver through the JST connector. The JST connector is compatible with external devices, such as the [SiK Telemetry Radio V3](https://www.sparkfun.com/sik-telemetry-radio-v3-915mhz-100mw.html) for RTK corrections using one of our [JST adapter cables](https://www.sparkfun.com/jst-ghr-04v-to-jst-ghr-06v-cable-1-25mm-pitch.html).

<div class="grid" markdown>

<figure markdown>
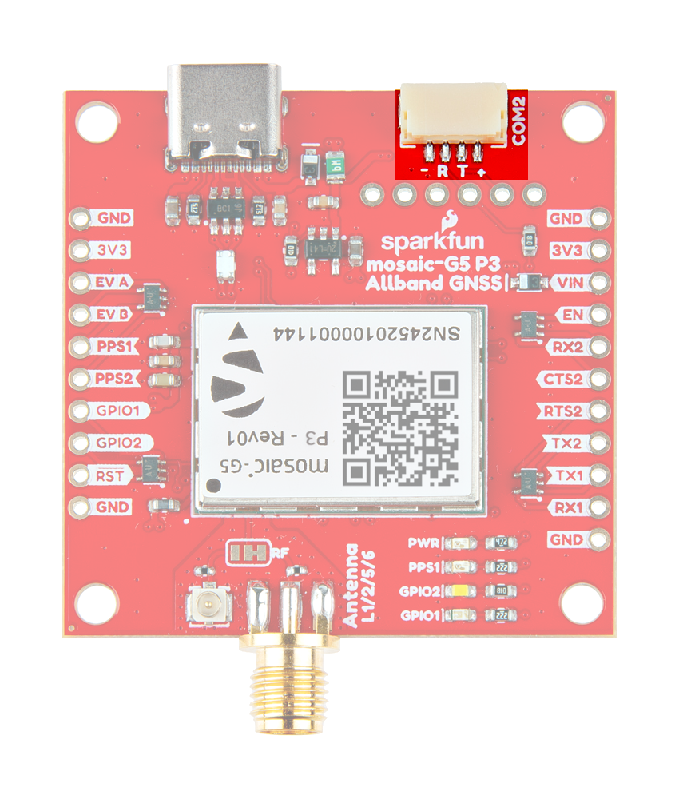
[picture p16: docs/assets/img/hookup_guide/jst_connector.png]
JST connector

<figcaption markdown>The JST connector on the All-band GNSS RTK breakout board.</figcaption>
</figure>

<div markdown>

!!! info
	By default, the UART ports are configured with the following settings:

	- Baudrate: 115200bps
	- Data Bits: 8
	- Parity: No
	- Stop Bits: 1
	- Flow Control: None

	The COM port settings are set with the `setCOMSettings` command.

	!!! tip "`UART2`"
		The `UART2` or `COM2` interface features flow control pins, which are disabled by default. The interface can also be accessed through the [BlueSMiRF header](#bluesmirf-header) and/or [PTH pins](#uarts).

		!!! warning "Bus Contention"
			To avoid [bus contention](https://en.wikipedia.org/wiki/Bus_contention) issues, make sure only one device is connected to any of these options.

</div>

</div>

!!! info "Pin Connections"

	<div class="grid" markdown>

	<div markdown>

	When connecting the All-band GNSS RTK breakout board to other products, users need to be aware of the pin connections between the devices.  and voltage ranges of the products. Below, is a table of the pin connections for the JST connector on the All-band GNSS RTK breakout board.

	<figure markdown>
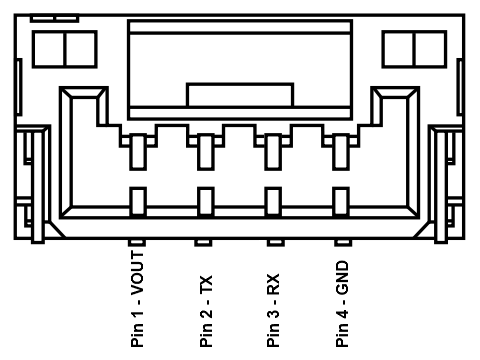
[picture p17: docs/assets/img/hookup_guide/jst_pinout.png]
JST pins
	
	<figcaption markdown>The pin connections of the JST connector.</figcaption>
	</figure>

	<article style="text-align: center;" markdown>

	<table border="1" markdown>
	<tr>
	<th style="vertical-align:middle;">Pin Number</th>
	<td align="center">
		**1**<br>
		*(Left Side)*
	</td>
	<td align="center">**2**</td>
	<td align="center">**3**</td>
	<td align="center" markdown>
		**4**<br>
		*(Right Side)*
	</td>
	</tr>
	<tr>
	<th>Label</th>
	<td align="center">`+`</td>
	<td align="center">`T`</td>
	<td align="center">`R`</td>
	<td align="center">`-`</td>
	</tr>
	<tr>
	<th style="vertical-align:middle;">Function</th>
	<td>
		<u>**Voltage Output**</u><br>
		- **Default: 3.3V**<br>
		- Selectable: 3.3V or 5V
	</td>
	<td align="center" style="vertical-align:middle;">`UART2` - Transmit</td>
	<td align="center" style="vertical-align:middle;">`UART2` - Receive</td>
	<td align="center" style="vertical-align:middle;">Ground</td>
	</tr>
	</table>

	</article>

	</div>

	<div markdown>

	As documented in the [LoRaSerial product manual](https://docs.sparkfun.com/SparkFun_LoRaSerial), the pin connections between a host system and the LoRaSerial Kit radio is outlined in the image below.

	<figure markdown>
	Flow Control (https://docs.sparkfun.com/SparkFun_LoRaSerial/img/SAMD21%20Flow%20control.png "Click to enlarge")
	<figcaption markdown>The `COM` ports on the All-band GNSS RTK breakout board.</figcaption>
	</figure>

	When connecting the All-band GNSS RTK breakout board to our radios, only the `RX`, `TX`, and `GND` connections are required as outlined in the table below. By default, flow control is disabled and the connections are unnecessary.

	<article style="text-align: center;" markdown>

	<table markdown>
	<tr>
	<th>Board</th>
	<td align="center">RX</td>
	<td align="center">TX</td>
	<td align="center">GND</td>
	</tr>
	<tr>
	<th>Radio</th>
	<td align="center">TX</td>
	<td align="center">RX</td>
	<td align="center">GND</td>
	</tr>
	</table>

	</article>

	!!! danger "`VSEL` Pin"
		By default, the power pin *(i.e. `+` or Pin 1)* of the JST connector is connected to **3.3V** and configured as a power output. An input voltage can be supplied through the pin; however, users should be mindful of any voltage contention issues.

		???+ tip "Jumper"
			By default, the [`VSEL` jumper](#jumpers) is connected to `3V3` pad for a regulated 3.3V output. However, users can modify the jumper to utilize the voltage supplied from either the USB or `VIN` inputs.

	</div>

	</div>

## External Antenna
The All-band GNSS RTK breakout board has two options for connecting an external GNSS antenna; the `Antenna L1/2/5/6` U.FL and SMA connectors. These inputs are DC-biased and ESD-protected, so an active antenna can directly be connected without additional components. By default, the SMA connector is the primary interface. In order to utilize the U.FL connector, the `RF` jumper must be modified to redirect the signal path from the SMA connector.

<div class="grid" markdown>

<figure markdown>
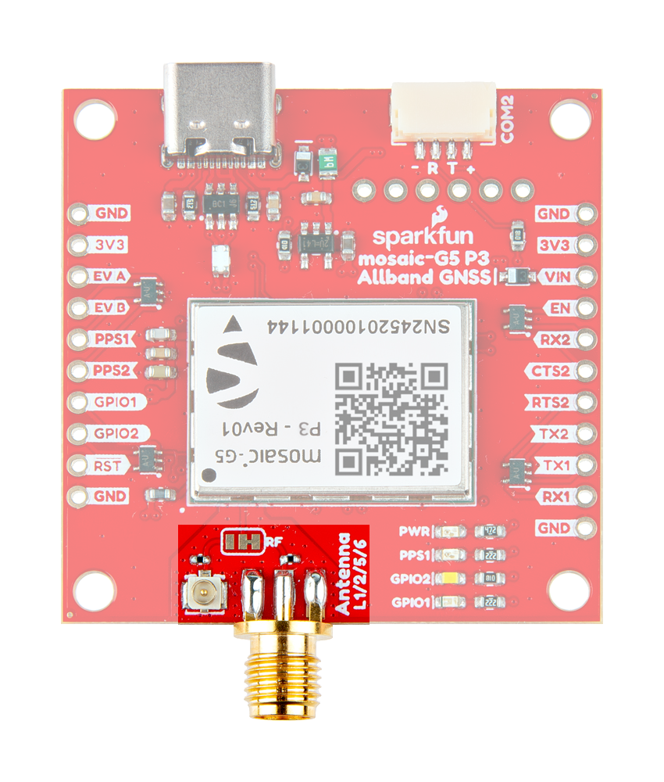
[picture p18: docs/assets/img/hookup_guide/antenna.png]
GNSS antenna input

<figcaption markdown>The SMA and U.FL connectors to attach a GNSS antenna to the All-band GNSS RTK breakout board.</figcaption>
</figure>

<div markdown>

Users will need to connect a compatible GNSS antenna to the `Antenna L1/2/5/6` connector. The type of antenna used with the mosaic-G5 P3 GNSS receiver affects the overall accuracy of the positions calculated by the GNSS receiver.

- An active antenna often features a [LNA](https://en.wikipedia.org/wiki/Low-noise_amplifier "low-noise amplifier"). This allows the GNSS receiver to boost the signal received by the GNSS receiver without degrading the [SNR](https://en.wikipedia.org/wiki/Signal-to-noise_ratio Signal-to-noise ratio).
- The more bands an antenna supports, the greater the performance.
	- Faster acquisition time.
	- Access and support for the `L5` GPS band can potentially mitigate multi-path errors.
	- Supporting more frequency bands, allows a GNSS receiver to be less susceptible to jamming and spoofing.

There are other key parameters related to an antenna that can make or break the signal reception from the satellites. These include, but are not limited to the operation frequency, gain, polarization, efficiency and overall loss.

!!! tip
	For the best performance, we recommend users choose a compatible L1/L2/L5/L6 active GNSS antenna and utilize a low-loss cable. Also, don't forget that GNSS signals are fairly weak and can't penetrate buildings or dense vegetation. The GNSS antenna should have an unobstructed view of the sky.

</div>

</div>

!!! info
	The `VANT` pin of the GNSS receiver provides external power for an active antenna. By default, this supply voltage is configured at **3.3V**.

	!!! danger
		Never inject an external DC voltage into the RF connection for the GNSS antenna, as it may damage the mosaic-G5 P3 GNSS receiver. For instance, when using a splitter to distribute the antenna signal to several GNSS receivers, make sure that no more than one output of the splitter passes DC. Use [DC-blocks](https://en.wikipedia.org/wiki/DC_block) otherwise.

## Status LEDs
<div class="grid" markdown>

<figure markdown>
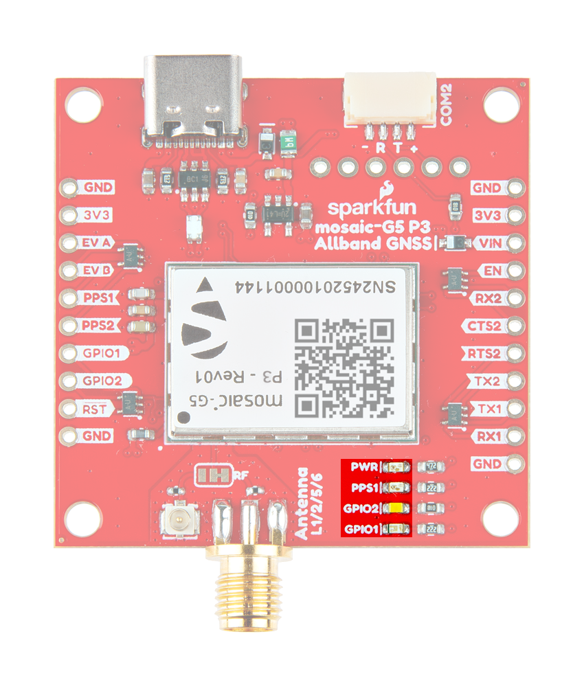
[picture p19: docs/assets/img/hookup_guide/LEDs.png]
Status LEDs

<figcaption markdown>The status indicator LEDs on the All-band GNSS RTK breakout board.</figcaption>
</figure>

<div markdown>

There are four status LEDs on the All-band GNSS RTK breakout board:

- `PWR` - Power *(Red)*
	- Turns on once power is supplied through the USB-C connector or `VIN` connections
- `PPS1` - Pulse-Per-Second *(Yellow)*
	- Indicates the pulse-per-second signal from the `PPS1` output *(see the **[PPS Output](#pps-output)** section)*
- `GPIO1` *(Blue)* and `GPIO2` *(White)*
	- These LEDs are controlled through the [GPIO pins](#gpio-pins) and operate based on configured mode

		??? info "LED Behavior"
			The GPIO1` and `GPIO2` LEDs will operate based on the following status modes, which are programmed with the `setGPIO1Mode` and `setGPIO2Mode` commands.

			- `PVTLED`: LED lights when a PVT solution is available.
			- `RTKLED`: LED is off if the PVT is not in RTK mode, blinks in float RTK and is solid on in fixed RTK.
			- `TRACKLED`: Tracked satellites indicator.

				| LED Behaviour | Number of Satellites in Tracking |
				| :------------ | :------------------------------- |
				| Blinks fast and continuously<br>*(10 times per second)* | 0 |
				| Blinks once, then pauses    | 1-2 |
				| Blinks twice, then pauses   | 3-4 |
				| Blinks 3 times, then pauses | 5-6 |
				| Blinks 4 times, then pauses | 7-8 |
				| Blinks 5 times, then pauses | 9+  |

			- `DIFFCORLED`: Differential correction indicator.

				- In rover PVT mode, this LED reports the number of satellites for which differential corrections have been provided in the last received differential correction message (RTCM or CMR).

					| LED Behaviour | Number of Satellites w/ Corrections |
					| :------------ | :---------------------------------- |
					| LED Off | No differential correction message received |
					| Blinks fast and continuously<br>*(10 times per second)* | 0 |
					| Blinks once, then pauses    | 1-2 |
					| Blinks twice, then pauses   | 3-4 |
					| Blinks 3 times, then pauses | 5-6 |
					| Blinks 4 times, then pauses | 7-8 |
					| Blinks 5 times, then pauses | 9+  |

				- If the corrections are received from geostationary satellites over the L-band, the LED will be on for about 1 second, then blink fast twice.

</div>

</div>

## Jumpers

??? note "Never modified a jumper before?"
	Check out our <a href="https://learn.sparkfun.com/tutorials/664">Jumper Pads and PCB Traces tutorial</a> for a quick introduction!

	<div class="grid cards" markdown align="center">

	-  <a href="https://learn.sparkfun.com/tutorials/664">
		<figure markdown>
		Tutorial thumbnail
		</figure>

		---

		**How to Work with Jumper Pads and PCB Traces**</a>

	</div>

There are nine jumpers on the board that can be used to easily modify the hardware connections on the board.

<div class="grid" markdown>

<figure markdown>
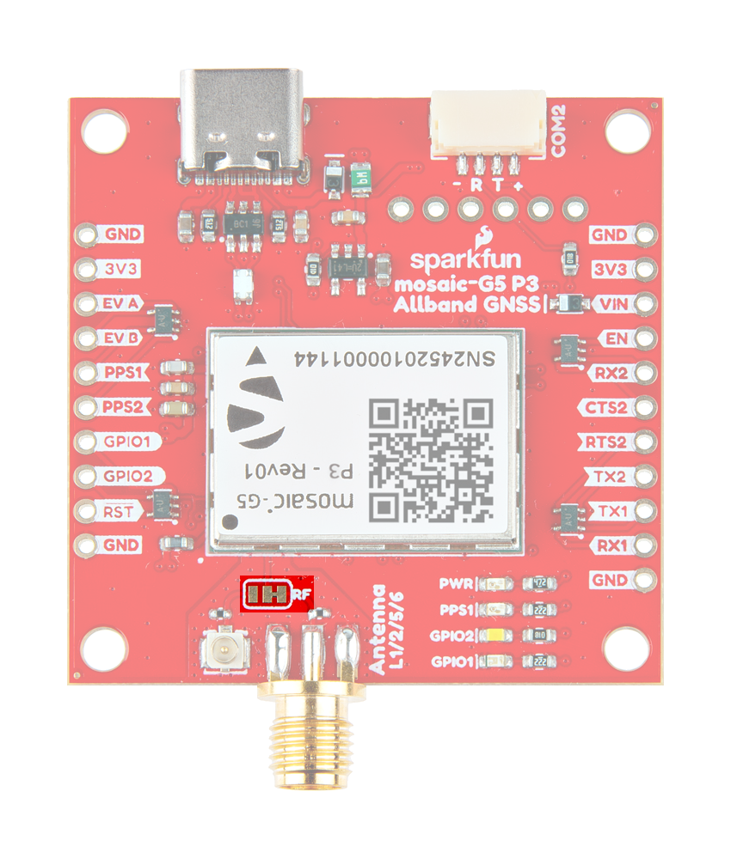
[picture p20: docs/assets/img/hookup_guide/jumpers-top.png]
Jumpers

<figcaption markdown>The jumper on the top of the All-band GNSS RTK breakout board.</figcaption>
</figure>

<figure markdown>
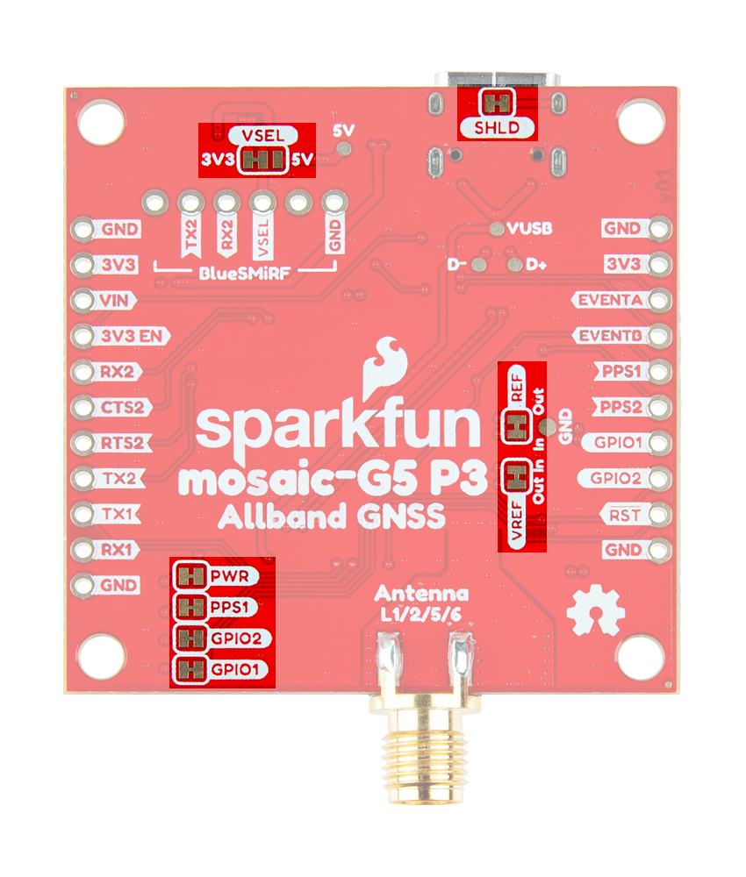
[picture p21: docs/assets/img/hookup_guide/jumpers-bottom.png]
Jumpers

<figcaption markdown>The jumpers on the back of the All-band GNSS RTK breakout board.</figcaption>
</figure>

</div>

=== "Antenna Input"
	**`RF`**
	:   This jumper can be modified to configure the RF input, for the external GNSS antenna, between the SMA and U.FL connectors.

	!!! info
		By default, the jumper is configured to utilize the SMA connector.

=== "Power"
	**`VSEL`**
	:   This jumper can be modified to configure/disconnect the `VCC` pin of the [4-pin locking JST connector](#jst-connector) and [BlueSMiRF header](#bluesmirf-header) to/from `3V3` or `5V` power.

		!!! info
			By default, the jumper is configured to supply 3.3V from the All-band GNSS RTK breakout board.

	**`SHLD`**
	:   This jumper can be cut to disconnect the shield of the USB-C connector from the board's ground plane.

=== "LED Power"
	There are four jumpers that control power to the [status LEDs](#status-leds) on the board.

	- **`PWR`** - This jumper can be cut to remove power from the red, power LED.
	- **`PPS1`** - This jumper can be cut to remove power from the yellow LED, which is connected to the [PPS](https://en.wikipedia.org/wiki/Pulse-per-second_signal "Pulse Per Second") signal.
	- **`GPIO2`** - This jumper can be cut to remove power from the white LED that is connected to the `GPIO2` pin.
	- **`GPIO1`** - This jumper can be cut to remove power from the blue LED that is connected to the `GPIO1` pin.

	!!! info
		By default, all the jumpers are connected, to power the status LEDs. For low power applications, users can cut the jumpers to disconnect power from each of the LEDs.

=== "Timing"
	**`VREF`**
	:   Controls the reference voltage for the internal TXCO

		- `In` - Voltage input for the internal TXCO
		- `Out` - Reference voltage to power the internal TXCO

	**`REF`**
	:   Controls the reference clock signal

		- `In` - Reference clock signal input
		- `Out` - 10-MHz signal from the internal TCXO

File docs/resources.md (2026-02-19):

## Product Resources

- :sfe: [Product Page](https://www.sparkfun.com/sparkfun-allband-gnss-rtk-breakout-mosaic-g5-p3.html)
- :material-folder-cog: Design Files:
	- :fontawesome-solid-file-pdf: [Board Dimensions](./assets/board_files/dimensions.pdf)
	- :fontawesome-solid-file-pdf: [Schematic](./assets/board_files/schematic.pdf)
	- :material-folder-zip: [KiCad Files](./assets/board_files/kicad_files.zip)
- Component Documentation
	- :fontawesome-solid-file-pdf: [mosaic-G5 P3 Datasheet](./assets/component_documentation/mosaic-g5_hardware_manual_v1.1.1.pdf)
		- :fontawesome-solid-file-pdf: [mosaic-G5 P3 Brochure](./assets/component_documentation/Septentrio_mosaic-G5_P3_&_P3H.pdf)
		- :fontawesome-solid-file-pdf: [Firmware Manual *(v1.0.1)*](./assets/component_documentation/firmware/v1.0.1/mosaic-G5%20Firmware%20v1.0.1%20Reference%20Guide.pdf)
	- :fontawesome-solid-file-pdf: [JST-GH Connector Datasheet](./assets/component_documentation/JST-GH_datasheet.pdf)
	- :fontawesome-solid-file-pdf: [RT9080 Datasheet](./assets/component_documentation/RT9080.pdf)
- :material-youtube: [SFE Product Showcase](https://youtu.be/TSkIvtaVZc0)
- :material-github: [Hardware Repo](https://github.com/sparkfun/SparkFun_GNSS_mosaic-G5_P3)

## 🏭&nbsp;Manufacturer's Resources
Septentrio also provides great resources for the mossaic-X5 GNSS receiver:

- [mosaic-G5 P3 Product Page](https://www.septentrio.com/en/products/gnss-receivers/gnss-receiver-modules/mosaic-G5-P3)
- :material-youtube: [Septentrio YouTube Channel](https://www.youtube.com/channel/UCrA9wMw1y1f-KeOnnhq4lrA/feed)
- [Support Page](https://www.septentrio.com/en/support)
	- :material-head-question: [Technical Support Portal](https://customersupport.septentrio.com/s/)
		- :material-head-lightbulb: [Knowledge Base](https://customersupport.septentrio.com/s/topiccatalog)
	- [Learn More](https://www.septentrio.com/en/learn-more)
		- [Webinars](https://www.septentrio.com/en/learn-more/webinars)
		- [Technical Papers](https://www.septentrio.com/en/learn-more/technical-papers)
		- [Insights](https://www.septentrio.com/en/learn-more/insights) *(Case Studies and Technical Articles)*
		- [Community](https://www.septentrio.com/en/learn-more/community)
		- [Agnostic Corrections Program](https://www.septentrio.com/en/products/correction-services/precise-point-positioning-services-land/agnostic-corrections-program-gnss-correction-services)
- [JammerTest - Anti-Jamming and Anti-Spoofing Performance](https://www.septentrio.com/en/learn-more/insights/most-resilient-gnss-receiver-results-jammertest-norway)

### Knowledge Base Articles

- [**mosaic-G5:** Product variant differentiation (P1/P3/P3H)](https://customersupport.septentrio.com/s/article/mosaic-G5-Variant-differentiation)
- [**mosaic-G5:** Getting started guide](https://customersupport.septentrio.com/s/article/mosaic-G5-getting-started)
- [**mosaic-G5:** Bluetooth (HC-06) dongle integration](https://customersupport.septentrio.com/s/article/mosaic-G5-bluetooth-dongle-integration)
- [**mosaic-G5:** step-by-step guide on how to setup an RTK capable mosaic-G5 receiver](https://customersupport.septentrio.com/s/article/mosaic-G5-getting-started-RTK-setup-mosaic-G5)
- [**mosaic-G5:** Logging data on mosaic-G5](https://customersupport.septentrio.com/s/article/mosaic-G5-logging-data-on-G5)
- [**CLI Chapter 1:** How to access the Command Line Interface?](https://customersupport.septentrio.com/s/article/How-to-access-the-Command-Line-Interface)
- [**CLI Chapter 2:** Command Line Interface description](https://customersupport.septentrio.com/s/article/CLI-description)
- [**CLI Chapter 3:** Command Types](https://customersupport.septentrio.com/s/article/CLI-types)
- [**CLI Chapter 4:** Command Line Syntax](https://customersupport.septentrio.com/s/article/CLI-syntax)
- [**CLI Chapter 5:** Command Replies](https://customersupport.septentrio.com/s/article/CLI-replies)
- [**CLI Chapter 6:** Command Syntax Tables](https://customersupport.septentrio.com/s/article/CLI-syntax-tables)
- [**CLI Chapter 7:** Where can I find the list of all the commands supported by my receiver?](https://customersupport.septentrio.com/s/article/CLI-supported-commands)
- [Generating a Diagnostic Report via Script or Command Line](https://customersupport.septentrio.com/s/article/Generating-a-diagnostic-report-via-Script-or-Command-Line)

<article style="text-align: center;" markdown>
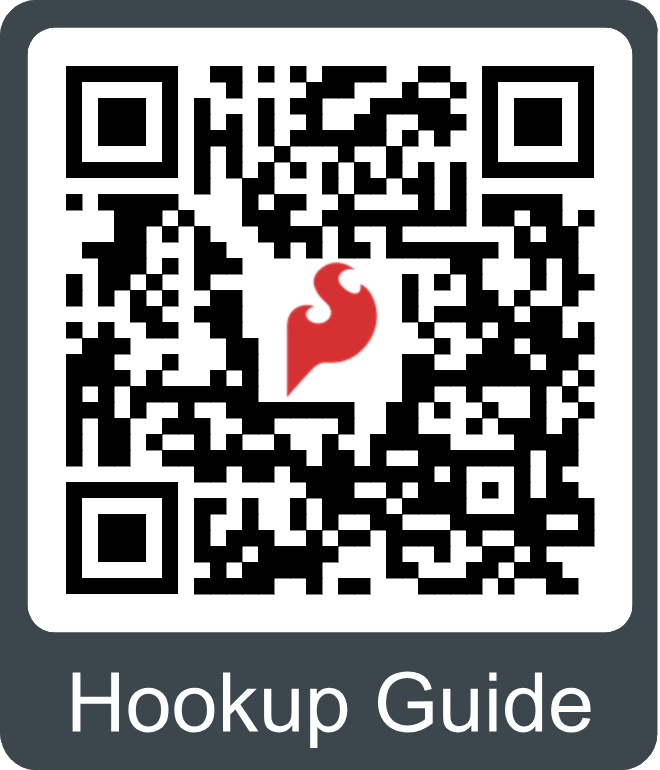
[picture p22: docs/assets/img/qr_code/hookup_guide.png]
QR code to the hookup guide

</article>

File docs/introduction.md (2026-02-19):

!!! danger  "Important: Read Before Use!"
	!!! warning "ESD Sensitivity"
		The mosaic-G5 P3 GNSS receiver is sensitive to [ESD](https://en.wikipedia.org/wiki/Electrostatic_discharge "Electrostatic Discharge"). Use a proper grounding system to make sure that the working surface and the components are at the same electric potential.

		??? info
			As recommended by the manufacturer, we highly recommend that users take the necessary precautions to avoid damaging their GNSS receiver.

			- The All-band GNSS RTK breakout board features ESD protection on the USB-C connector and breakout pins:
				- USB data lines
				- I/O PTH pads
				- JST connector and BlueSMiRF header pins
			- The mosaic-G5 P3 GNSS receiver features internal ESD protection to the `ANT_1` antenna input.

			<div class="video-500px" style="margin: auto;" markdown>
			<iframe src="https://www.youtube.com/embed/hrL5J6Q5gX8?si=jOPBat8rzMnL7Uz4&amp;start=26;&amp;end=35;" title="Septentrio: Getting Started Video (playback starts at ESD warning)" frameborder="0" allow="accelerometer; autoplay; clipboard-write; encrypted-media; gyroscope; picture-in-picture" allowfullscreen></iframe>
			</div>

	!!! warning "Active Antenna"
		Never inject an external DC voltage into the SMA connector for the GNSS antenna, as it may damage the mosaic-G5 P3 GNSS receiver. For instance, when using a splitter to distribute the antenna signal to several GNSS receivers, make sure that no more than one output of the splitter passes DC. Use [DC-blocks](https://en.wikipedia.org/wiki/DC_block) otherwise.

# Introduction
<div class="grid cards desc" markdown>

-   <a href="https://www.sparkfun.com/sparkfun-allband-gnss-rtk-breakout-mosaic-g5-p3.html">
	**mosaic-G5 P3 GNSS Breakout**<br>
	**SKU:** GPS-29208

	---

	<figure markdown>
	Product Thumbnail
	</figure></a>

	<article style="text-align: center;" markdown>
	[Purchase from SparkFun :fontawesome-solid-cart-plus:{ .heart }](https://www.sparkfun.com/sparkfun-allband-gnss-rtk-breakout-mosaic-g5-p3.html){ .md-button .md-button--primary }
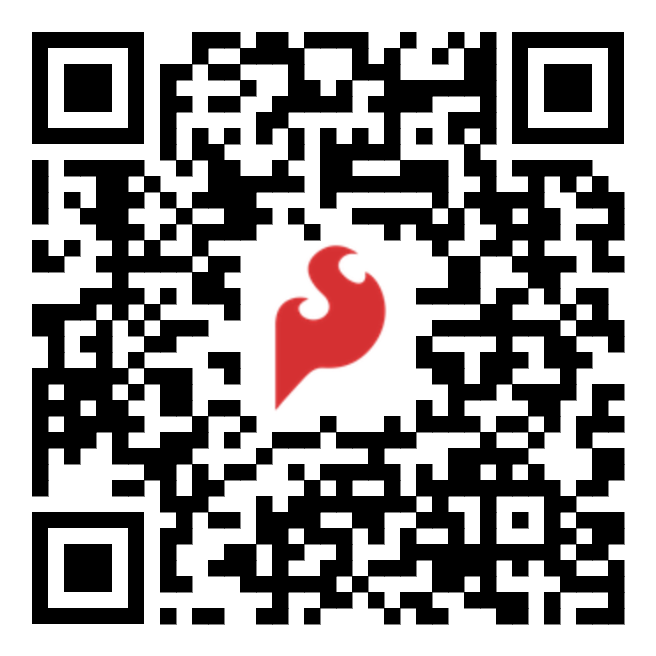
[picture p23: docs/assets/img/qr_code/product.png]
QR code to product page
	
	</article>

-   This SparkFun Allband GNSS RTK Breakout features the Septentrio mosaic-G5 P3 GNSS receiver, a 60% smaller and 40% lower power consumption variant of the mosaic-X5 GNSS receiver, making it ideal for drone and IoT applications. The receiver supports the GPS (USA), GLONASS (Russia), Beidou (China), Galileo (Europe), and QZSS (Japan) GNSS constellations, including regional systems *(i.e. SBAS)*. With its Real-Time Kinematics (RTK) capabilities, the GNSS receiver can achieve a horizontal accuracy of 6mm (~0.25in), vertical accuracy of 1cm (~0.4in), PPS timing resolution of 1.4ns (1.4 billionths of a second), and event trigger accuracy below 3ns. It also features Septentrio's unique [AIM+ technology](https://www.septentrio.com/en/learn-more/advanced-positioning-technology/aim-jamming-protection) for interference mitigation and anti-spoofing, ensuring best-in-class reliability and scalable position accuracy.

	The mosaic-G5 P3 GNSS receiver supports USB 2.0 communication and two UART interfaces; along with two GPIO, two configurable PPS outputs, and two event trigger input pins. Users can control and configure the GNSS receiver through a command-line interface (CLI) using the Septentrio Binary Format (SBF), NMEA, and RTCM v3.x protocols. Otherwise, users can also configure the GNSS receiver with Septentrio's [RxTools software application](https://www.septentrio.com/en/products/gps-gnss-receiver-software/rxtools). On the board, the `UART2` interface is also broken out to a locking JST connector and BlueSMiRF PTH header pins to attach an RF transceiver for RTK corrections.

</div>

??? question "Product Comparison: GNSS Products"
	Below is a simple comparison table between our breakout board and Septentrio's development and evaluation kits:

	<div class="annotate" markdown align="center">
	<table markdown>
	<tr markdown>
		<td markdown></td>
		<th markdown style="text-align:center">
			mosaic-X5 Development Kit<br>
			<hr>
			<figure markdown>
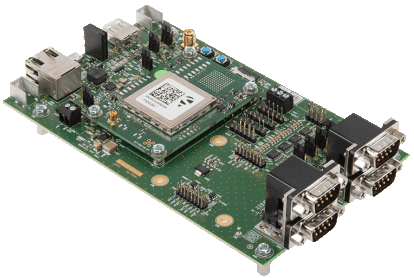
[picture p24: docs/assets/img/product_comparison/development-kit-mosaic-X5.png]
Product Thumbnail
			
			</figure>
		</th>
		<th markdown style="text-align:center">
			mosaic-go X5 Evaluation Kit<br>
			<hr>
			<figure markdown>
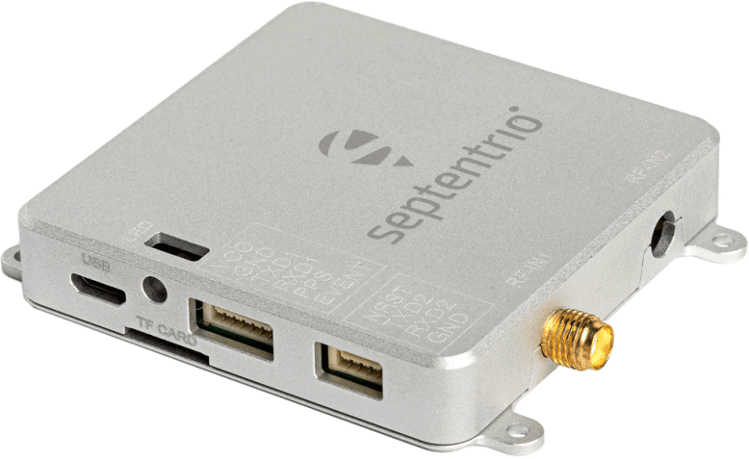
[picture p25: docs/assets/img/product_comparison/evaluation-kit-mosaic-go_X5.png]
Product Thumbnail
			
			</figure>
		</th>
		<th markdown style="text-align:center">
			mosaic-go G5 Evaluation Kit<br>
			<hr>
			<figure markdown>
			Product Thumbnail
			</figure>
		</th>
		<th markdown style="text-align:center">
			mosaic-X5 GNSS Breakout<br>
			<hr>
			<figure markdown>
			Product Thumbnail
			</figure>
		</th>
		<th markdown style="text-align:center">
			RTK mosaic-X5<br>
			<hr>
			<figure markdown>
			Product Thumbnail
			</figure>
		</th>
		<th markdown style="text-align:center">
			SparkPNT RTK Facet mosaic<br>
			<hr>
			<figure markdown>
			Product Thumbnail
			</figure>
		</th>
		<th markdown style="text-align:center">
			mosaic-G5 P3 GNSS Breakout<br>
			<hr>
			<figure markdown>
			Product Thumbnail
			</figure>
		</th>
		<th markdown style="text-align:center">
			mosaic-X5 Flex Module<br>
			<hr>
			<figure markdown>
			Product Thumbnail
			</figure>
		</th>
		<th markdown style="text-align:center">
			mosaic-X5 +IM19 Flex Module<br>
			<hr>
			<figure markdown>
			Product Thumbnail
			</figure>
		</th>
		<th markdown style="text-align:center">
			mosaic-G5 P3 Flex Module<br>
			+ IM19 IMU *(optional)*<br>
			<hr>
			<figure markdown>
			Product Thumbnail
			</figure>
		</th>
	</tr>
	<tr>
		<td style="vertical-align:middle;">GNSS Antenna</td>
		<td style="text-align:center; vertical-align:middle;">Dual</td>
		<td style="text-align:center">
			1 - X5<br>
			2 - H
		</td>
		<td style="text-align:center">
			2 - G5 P3*<br>
			2 - G5 T*<br>
			2 - G5 P3H
		</td>
		<td style="text-align:center; vertical-align:middle;">1</td>
		<td style="text-align:center; vertical-align:middle;">1</td>
		<td style="text-align:center; vertical-align:middle;">Integrated</td>
		<td style="text-align:center; vertical-align:middle;">1</td>
		<td style="text-align:center; vertical-align:middle;">1</td>
		<td style="text-align:center; vertical-align:middle;">1</td>
		<td style="text-align:center; vertical-align:middle;">1</td>
	</tr>
	<tr>
		<td markdown>USB Connector</td>
		<td style="text-align:center">micro-B</td>
		<td style="text-align:center">micro-B</td>
		<td style="text-align:center">Type-C</td>
		<td style="text-align:center">Type-C</td>
		<td style="text-align:center">Type-C</td>
		<td style="text-align:center">Type-C</td>
		<td style="text-align:center">Type-C</td>
		<td style="text-align:center">N/A*</td>
		<td style="text-align:center">N/A*</td>
		<td style="text-align:center">Type-C</td>
	</tr>
	<tr>
		<td style="vertical-align:middle;">Ethernet</td>
		<td style="text-align:center">Yes</td>
		<td style="text-align:center">No</td>
		<td style="text-align:center">No</td>
		<td style="text-align:center">No</td>
		<td style="text-align:center">Yes</td>
		<td style="text-align:center">No</td>
		<td style="text-align:center">No</td>
		<td style="text-align:center">2x10 Header*</td>
		<td style="text-align:center">No</td>
		<td style="text-align:center">No</td>
	</tr>
	<tr>
		<td style="vertical-align:middle;">WiFi</td>
		<td style="text-align:center">No</td>
		<td style="text-align:center">No</td>
		<td style="text-align:center">No</td>
		<td style="text-align:center">No</td>
		<td style="text-align:center">Yes</td>
		<td style="text-align:center">Yes</td>
		<td style="text-align:center">No</td>
		<td style="text-align:center">No</td>
		<td style="text-align:center">No</td>
		<td style="text-align:center">No</td>
	</tr>
	<tr>
		<td style="vertical-align:middle;">COM Ports</td>
		<td style="text-align:center">4</td>
		<td style="text-align:center">2</td>
		<td style="text-align:center">2</td>
		<td style="text-align:center">4</td>
		<td style="text-align:center">
			1 - mosaic-X5<br>
			1 - ESP32
		</td>
		<td style="text-align:center">
			1 - mosaic-X5<br>
			1 - ESP32
		</td>
		<td style="text-align:center">2</td>
		<td style="text-align:center">4</td>
		<td style="text-align:center">
			2 - mosaic-X5<br>
			2 - IM19 IMU
		</td>
		<td style="text-align:center">
			2 - mosaic-G5<br>
			2 - IM19 IMU*
		</td>
	</tr>
	<tr>
		<td markdown>&micro;SD Card Slot</td>
		<td style="text-align:center">Yes</td>
		<td style="text-align:center">Yes</td>
		<td style="text-align:center">Yes*</td>
		<td style="text-align:center">Yes</td>
		<td style="text-align:center">Yes</td>
		<td style="text-align:center">Yes</td>
		<td style="text-align:center">No</td>
		<td style="text-align:center">2x10 Header*</td>
		<td style="text-align:center">2x10 Header*</td>
		<td style="text-align:center">No</td>
	</tr>
	<tr>
		<td style="vertical-align:middle;">Reset/Log Buttons</td>
		<td style="text-align:center; vertical-align:middle;">Yes</td>
		<td style="text-align:center; vertical-align:middle;">No*</td>
		<td style="text-align:center; vertical-align:middle;">No*</td>
		<td style="text-align:center; vertical-align:middle;">Yes</td>
		<td style="text-align:center; vertical-align:middle;">Yes</td>
		<td style="text-align:center; vertical-align:middle;">Yes</td>
		<td style="text-align:center; vertical-align:middle;">No</td>
		<td style="text-align:center; vertical-align:middle;">No</td>
		<td style="text-align:center; vertical-align:middle;">No</td>
		<td style="text-align:center; vertical-align:middle;">No</td>
	</tr>
	<tr>
		<td style="vertical-align:middle;">Logic-Level</td>
		<td style="text-align:center">
			1.8V<br>
			3.3V
		</td>
		<td style="text-align:center; vertical-align:middle;">3.3V</td>
		<td style="text-align:center; vertical-align:middle;">3.3V</td>
		<td style="text-align:center; vertical-align:middle;">3.3V</td>
		<td style="text-align:center">
			3.3V<br>
			5V
		</td>
		<td style="text-align:center; vertical-align:middle;">3.3V</td>
		<td style="text-align:center; vertical-align:middle;">3.3V</td>
		<td style="text-align:center; vertical-align:middle;">3.3V</td>
		<td style="text-align:center; vertical-align:middle;">3.3V</td>
		<td style="text-align:center; vertical-align:middle;">3.3V</td>
	</tr>
	<tr>
		<td markdown>PPS Signal</td>
		<td style="text-align:center">Header Pin</td>
		<td style="text-align:center">6-Pin JST Connector</td>
		<td style="text-align:center">Header Pin</td>
		<td style="text-align:center">SMA Connector</td>
		<td style="text-align:center">Screw Terminal</td>
		<td style="text-align:center">No</td>
		<td style="text-align:center">Header Pin</td>
		<td style="text-align:center">2x10 Header*</td>
		<td style="text-align:center">2x10 Header*</td>
		<td style="text-align:center">2x10 Header*</td>
	</tr>
	<tr>
		<td markdown>Enclosure Material</td>
		<td style="text-align:center; vertical-align:middle;">N/A</td>
		<td style="text-align:center; vertical-align:middle;">Metal</td>
		<td style="text-align:center; vertical-align:middle;">Metal</td>
		<td style="text-align:center; vertical-align:middle;">N/A</td>
		<td style="text-align:center; vertical-align:middle;">Aluminum</td>
		<td style="text-align:center; vertical-align:middle;">Plastic</td>
		<td style="text-align:center; vertical-align:middle;">N/A</td>
		<td style="text-align:center; vertical-align:middle;">N/A</td>
		<td style="text-align:center; vertical-align:middle;">N/A</td>
		<td style="text-align:center; vertical-align:middle;">N/A</td>
	</tr>
	<tr>
		<td style="vertical-align:middle;">Dimensions</td>
		<td style="text-align:center; vertical-align:middle;">N/A</td>
		<td style="text-align:center; vertical-align:middle;">71.0 x 59.0 x 12.0mm ± 1mm</td>
		<td style="text-align:center; vertical-align:middle;">74.0 x 44.0 x 11.4mm</td>
		<td style="text-align:center; vertical-align:middle;">70.9 x 50.8 x 8mm</td>
		<td style="text-align:center">
			180.6 x 101.8 x 41mm<br>
			<i>Enclosure Only</i>
		</td>
		<td style="text-align:center; vertical-align:middle;"></td>
		<td style="text-align:center; vertical-align:middle;">43.2 x 43.2 x 8mm</td>
		<td style="text-align:center; vertical-align:middle;">44.0 x 34.0 x 10.4mm</td>
		<td style="text-align:center; vertical-align:middle;">44.0 x 34.0 x 10.4mm</td>
		<td style="text-align:center; vertical-align:middle;">44.0 x 34.0 x 8.5mm</td>
	</tr>
	<tr>
		<td style="vertical-align:middle;">Weight</td>
		<td style="text-align:center; vertical-align:middle;">N/A</td>
		<td style="text-align:center; vertical-align:middle;">58g  ± 1g</td>
		<td style="text-align:center; vertical-align:middle;">50g</td>
		<td style="text-align:center; vertical-align:middle;">22.60g</td>
		<td style="text-align:center; vertical-align:middle;">
			415.15g<br>
			<i>Enclosure Only</i>
		</td>
		<td style="text-align:center; vertical-align:middle;"></td>
		<td style="text-align:center; vertical-align:middle;">11.15g</td>
		<td style="text-align:center; vertical-align:middle;">14.00g</td>
		<td style="text-align:center; vertical-align:middle;">15.25g</td>
		<td style="text-align:center; vertical-align:middle;">
			- IMU: 9.20g<br>
			+ IMU: 10.95g
		</td>
	</tr>

	</table>

	</div>

	!!! note "mosaic-go Evaluation Kits"
		- For the mosaic-X5 and mosaic-H, the reset pin is exposed on 4-pin JST connector and the log pin is connected to the latch pin of the SD card slot.
		- For the mosaic-G5 P3/T/H, the reset pin is exposed on a header pin. There is no log pin, data logging must be enabled through a command set. Logging to internal disk (`DSK1`) is only for debugging purposes, feature is prone to [data gaps during operation](https://customersupport.septentrio.com/s/article/mosaic-G5-logging-data-on-G5).

	!!! note "mosaic GNSS Flex Modules"
		SparkPNT GNSS Flex modules are modular, *plug-in* boards that utilize a *carrier* board to access the pins of the GNSS Flex headers.

		- The USB, SD card, and Ethernet interfaces and PPS signals are exposed through the 2x10 header pins.
		- For the GNSS Flex modules with an optional IMU, the last two COM ports are reserved for the IM19 IMU.

??? question "Product Comparison: mosaic-G5 Modules"
	The variants of the mosaic-G5 product family offer diverse capabilities tailored for specific applications, primarily focusing on new use cases within ground robotics, UAV, and other scenarios requiring a small form factor without compromising performances.

	- The triple-band mosaic-G5 P1 offers entry-level, high-performance positioning that is ideal for high-volume applications such as inspection drones or robotic mowers.
	- The All-band mosaic-G5 P3 and P3H bring strong positioning reliability in challenging environments and are tailored for applications such as delivery or light show drones.
		- P3H: The mosaic-G5 P3H can calculate heading with a uniquely small baseline distance between its two GNSS antennas, providing accurate navigation for small autonomous devices.
	- The multi-band mosaic-G5 T provides clock and frequency synchronization with nano-second accuracy. It also features Septentrio's AIM+ Premium technology for enhanced jamming and spoofing protection for additional resilience.

	<div align="center" markdown>
	<table markdown>
	<tbody markdown>
	<tr markdown>
		<th markdown>Features</td>
		<th colspan="4" rowspan="1" style="text-align:center;" markdown>mosaic-G5 Product Family</td>
	</tr>
	<tr style="break-inside: avoid;" markdown>
		<td markdown>Variants</td>
		<td style="text-align:center;" markdown>**mosaic-G5 P1**</td>
		<td style="text-align:center;" markdown>**mosaic-G5 P3**</td>
		<td style="text-align:center;" markdown>**mosaic-G5 P3H**</td>
		<td style="text-align:center;" markdown>**mosaic-G5 T**</td>
	</tr>
	<tr style="break-inside: avoid;" markdown>
		<td style="vertical-align:middle;" markdown>
			Constellation<br>
			Frequency Bands
		</td>
		<td valign="top" markdown>
			**3 - L1, L2, L5** (incl B3I)
			<li>GPS: L1C/A, L1C, L2C, L2PY, L5</li>
			<li>Glonass: L1C/A, L2C/A, L2P, L3OC</li>
			<li>Beidou: B1I, B1C, B2a, B2I, B3I</li>
			<li>Galileo: E1, E5a, E5b</li>
			<li>QZSS: L1, L2, L5</li>
		</td>
		<td valign="top" markdown>
			**4 - L1, L2, L5, E6** (incl B3I)
			<li>GPS: L1C/A, L1C, L2C, L2PY, L5</li>
			<li>Glonass: L1C/A, L2C/A, L2P, L3OC</li>
			<li>Beidou: B1I, B1C, B2a, B2I, B3I</li>
			<li>Galileo: E1, E5a, E5b, **E6BC**</li>
			<li>QZSS: L1, L2, L5, **L6**</li>
			<li>NavIC: L5*</li>
		</td>
		<td valign="top" markdown>
			**4 - L1, L2, L5, E6** (incl B3I)*
			<li>GPS: L1C/A, L1C, L2C, L2PY, L5</li>
			<li>Glonass: L1C/A, L2C/A, L2P, L3OC</li>
			<li>Beidou: B1I, B1C, B2a, B2I, B3I</li>
			<li>Galileo: E1, E5a, E5b, **E6BC**</li>
			<li>QZSS: L1, L2, L5, **L6**</li>
			<li>NavIC: L5*</li>
		</td>
		<td valign="top" markdown>
			**5 - L1, L2, L5, E6/L6, L-Band**
			<li>GPS: L1C/A, L1C, L2C, L2PY, L5</li>
			<li>Glonass: L1C/A, L2C/A, L2P, L3OC</li>
			<li>Beidou: B1I, B1C, B2a, B2I, B3I, **B2B**</li>
			<li>Galileo: E1, E5a, E5b, **E6BC**</li>
			<li>QZSS: L1, L2, L5, **L6**</li>
			<li>NavIC: L5*</li>
			<li>L-Band</li>
		</td>
	</tr>
	<tr style="break-inside:avoid;" markdown>
		<td style="vertical-align:middle;" markdown>Robustness & Resilience</td>
		<td valign="top" markdown>
			<li>Manual anti-jamming, no auto-mitigation</li>
			<li>Anti-spoofing detection</li>
			<li>Anti-jamming detection</li>
			<li>IONO indicator</li>
		</td>
		<td valign="top" markdown>
			<li>**OSNMA**</li>
			<li>**Automatic** anti-jamming, mitigation **Class 1**</li>
			<li>Anti-spoofing detection and mitigation</li>
			<li>IONO indicator and mitigation</li>
		</td>
		<td valign="top" markdown>
			<li>**OSNMA**</li>
			<li>**Automatic** anti-jamming, mitigation **Class 1**</li>
			<li>Anti-spoofing detection and mitigation</li>
			<li>IONO indicator and mitigation</li>
		</td>
		<td valign="top" markdown>
			<li>**OSNMA**</li>
			<li>**Automatic** anti-jamming, mitigation **Class 2**</li>
			<li>Anti-spoofing detection and mitigation</li>
		</td>
	</tr>
	<tr style="break-inside: avoid;" markdown>
		<td markdown>Heading - Dual Antenna</td>
		<td markdown>No</td>
		<td markdown>No</td>
		<td markdown>**Yes**</td>
		<td markdown>No</td>
	</tr>
	<tr style="break-inside: avoid;" markdown>
		<td style="vertical-align:middle;" markdown>RTK</td>
		<td style="vertical-align:middle;" markdown>Rover only (no base)</td>
		<td markdown>
			Rover only<br>
			(Base Station*)
		</td>
		<td markdown>
			Rover only<br>
			(Base Station*)
		</td>
		<td style="vertical-align:middle;" markdown>No</td>
	</tr>
	<tr style="break-inside: avoid;" markdown>
		<td markdown>PPP / MCPPAR</td>
		<td markdown>No</td>
		<td markdown>No</td>
		<td markdown>No</td>
		<td markdown>No</td>
	</tr>
	<tr style="break-inside: avoid;" markdown>
		<td markdown>Galileo HAS</td>
		<td markdown>No</td>
		<td markdown>**Yes***</td>
		<td markdown>**Yes***</td>
		<td markdown>**Yes***</td>
	</tr>
	<tr style="break-inside: avoid;" markdown>
		<td markdown>Raw Data</td>
		<td markdown>No</td>
		<td markdown>**Yes**</td>
		<td markdown>No</td>
		<td markdown>No</td>
	</tr>
	<tr style="break-inside: avoid;" markdown>
		<td markdown>Events</td>
		<td markdown>No</td>
		<td markdown>**Yes**</td>
		<td markdown>**Yes**</td>
		<td markdown>**Yes**</td>
	</tr>
		<tr style="break-inside: avoid;" markdown>
		<td markdown>Moving Base</td>
		<td markdown>No</td>
		<td markdown>**Yes***</td>
		<td markdown>**Yes***</td>
		<td markdown>No</td>
	</tr>
	<tr style="break-inside: avoid;" markdown>
		<td markdown>Data Rate</td>
		<td markdown>5 Hz</td>
		<td markdown>20 Hz</td>
		<td markdown>20 Hz</td>
		<td markdown>5 Hz</td>
	</tr>
	<tr style="break-inside: avoid;" markdown>
		<td markdown>Time and Frequency Sync</td>
		<td style="vertical-align:middle;" markdown>No</td>
		<td style="vertical-align:middle;" markdown>No</td>
		<td style="vertical-align:middle;" markdown>No</td>
		<td style="vertical-align:middle;" markdown>**Yes**</td>
	</tr>
	<tr style="break-inside: avoid;" markdown>
		<td markdown>Evaluation kit</td>
		<td markdown>No</td>
		<td markdown>**Yes**</td>
		<td markdown>**Yes**</td>
		<td markdown>**Yes**</td>
	</tr>
	</tbody>
	</table>

	Source: [mosaic-G5: Product variant differentiation (P1/P3/P3H)](https://customersupport.septentrio.com/s/article/mosaic-G5-Variant-differentiation)

	</div>

	`*`: Roadmap items

In this guide we'll cover how to setup the mosaic-G5 P3 GNSS breakout board. To follow along with this tutorial, at a minimum, users will need the following items:

<div class="annotate" markdown>

- Computer with an operating system (OS) that is compatible with all the software installation requirements (1)

	!!! warning "Software Compatibility"
		The [RxTools software suite](https://www.septentrio.com/en/products/gps-gnss-receiver-software/rxtools) from Septentrio, provides users with an interface for the receiver configuration, monitoring, data logging, and analysis. However, it only appears to be available for Windows and Linux operating systems.

- [USB 3.1 Cable A to C - 3 Foot](https://www.sparkfun.com/usb-3-1-cable-a-to-c-3-foot.html) - Used to interface with the mosaic-G5 P3 GNSS Breakout (2)
- [SparkFun All-band GNSS RTK Breakout - mosaic-G5 P3](https://www.sparkfun.com/sparkfun-allband-gnss-rtk-breakout-mosaic-g5-p3.html)
- GNSS Multi-Band Antenna (3)
	- [GNSS Multi-Band Helical Antenna](https://www.sparkfun.com/gnss-multi-band-l1-l2-l5-helical-antenna-locking-sma.html)
		- [SMA Female to SMA Male Cable](https://www.sparkfun.com/interface-cable-sma-female-to-sma-male-10m-rg58.html)
	- [GNSS Multi-Band Surveying Antenna](https://www.sparkfun.com/gnss-multi-band-l1-l2-l5-surveying-antenna-tnc-spk6618h.html)
		- [SMA Male to TNC Male Cable](https://www.sparkfun.com/reinforced-interface-cable-sma-male-to-tnc-male-10m.html)
		- [Antenna Mount](https://www.sparkfun.com/gnss-magnetic-antenna-mount-5-8-11-tpi.html)

</div>

1. A list of the compatible GNSS receiver software, is provided on the [Septentrio website](https://www.septentrio.com/en/products/gps-gnss-receiver-software).
2. If your computer doesn't have a USB-A slot, then choose an appropriate cable or adapter.
3. For the best performance, use a compatible L1/L2/L5/L6 GNSS antenna.

<div class="grid cards" markdown>

-   <a href="https://www.sparkfun.com/usb-3-1-cable-a-to-c-3-foot.html">
	<figure markdown>
	USB 3.1 Cable A to C - 3 Foot
	</figure>

	---

	**USB 3.1 Cable A to C - 3 Foot**<br>
	CAB-14743</a>

-   <a href="https://www.sparkfun.com/sparkfun-allband-gnss-rtk-breakout-mosaic-g5-p3.html">
	<figure markdown>
	Product Thumbnail
	</figure>

	---

	**Allband GNSS RTK Breakout mosaic-G5 P3**<br>
	GPS-29208</a>

-   <a href="https://www.sparkfun.com/gnss-multi-band-l1-l2-l5-helical-antenna-locking-sma.html">
	<figure markdown>
	Product Thumbnail
	</figure>

	---

	**GNSS Multi-Band L1/L2/L5 Helical Antenna (Locking SMA)**<br>
	GPS-30249</a>

-   <a href="https://www.sparkfun.com/interface-cable-sma-female-to-sma-male-10m-rg58.html">
	<figure markdown>
	Product Thumbnail
	</figure>

	---

	**Interface Cable - SMA Female to SMA Male (10m, RG58)**<br>
	CAB-21281</a>

-   <a href="https://www.sparkfun.com/gnss-multi-band-l1-l2-l5-surveying-antenna-tnc-spk6618h.html">
	<figure markdown>
	Product Thumbnail
	</figure>

	---

	**GNSS Multi-Band L1/L2/L5/L6 Surveying Antenna - TNC (SPK6618H)**<br>
	GPS-21801</a>

-   <a href="https://www.sparkfun.com/reinforced-interface-cable-sma-male-to-tnc-male-10m.html">
	<figure markdown>
	Product Thumbnail
	</figure>

	---

	**Reinforced Interface Cable - SMA Male to TNC Male (10m)**<br>
	CAB-21740</a>

-   <a href="https://www.sparkfun.com/gnss-magnetic-antenna-mount-5-8-11-tpi.html">
	<figure markdown>
	Product Thumbnail
	</figure>

	---

	**GNSS Magnetic Antenna Mount - 5/8" 11-TPI**<br>
	PRT-21257</a>

</div>

!!! danger "ESD Protection"
	The Septentrio mosaic-G5 P3 GNSS receiver is sensitive to [ESD](https://en.wikipedia.org/wiki/Electrostatic_discharge "Electrostatic Discharge"). Use a proper grounding system to make sure that the working surface and the components are at the same electric potential.

	<article class="video-500px" style="margin: auto;" markdown>
	<iframe src="https://www.youtube.com/embed/hrL5J6Q5gX8?si=jOPBat8rzMnL7Uz4&amp;start=26;&amp;end=35;" title="Septentrio: Getting Started Video (playback starts at ESD warning)" frameborder="0" allow="accelerometer; autoplay; clipboard-write; encrypted-media; gyroscope; picture-in-picture" allowfullscreen></iframe>
	</article>

	!!! warning
		As recommended by the manufacturer, we highly recommend that users take the necessary precautions to avoid damaging their GNSS receiver.

## Section Topics
This guide is divided into three sections:

- The **Quickstart Guide** assumes a working knowledge of GNSS receiver, development boards, and the required software to program and/or configure them for your project's needs. It only covers basic hardware information and assembly instructions users would need to get started with this product.
- The **Hardware** section has two sub-sections that provide:
	- An overview of the board's design, major components, and interfaces. Refer to this page for information on the connectors, breakout pins, and jumpers.
	- Assembly instructions for this product's interfaces.
- The **Software** section has several sub-sections. The mosaic-G5 P3 GNSS receiver has numerous capabilities and a multitude of ways to configure and interface with them.
- In the **Resources** and **Support** sections, users can find the design files (KiCad files & schematic), relevant documentation (datasheets, white papers, etc.) and other helpful links on the Resources page. Lastly, the **Troubleshooting Tips** page includes helpful tips and instructions for how to receive technical support from SparkFun.

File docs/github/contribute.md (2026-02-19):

## Make an Augmentation!
Spot an improvement opportunity? Feel free to contribute to our open-source design and documentation. 

## :material-file-document-multiple:&nbsp;Improve our Documentation
All of this documentation can be modified by you! Please help us make it better.

- These pages are contained in the [`docs` folder](https://github.com/sparkfun/SparkFun_GNSS_mosaic-G5_P3/tree/main/docs) of the [SparkFun GNSS mosaic-G5 P3 repository](https://github.com/sparkfun/SparkFun_GNSS_mosaic-G5_P3).

<!-- ### :material-source-pull:&nbsp;Submit a Correction -->
### Submit a Correction

1. With a GitHub account, [fork this repository](https://github.com/sparkfun/SparkFun_GNSS_mosaic-G5_P3/fork).
2. Add your corrections or improvements to the markdown file.
3. File a pull request with your changes, and enjoy making the ~~words~~ ~~worlds~~ world a better place.
	- Once received, the documentation specialist will automatically be notified.
	- We will review your suggested improvements to make sure they are correct and fit within our documentation standards.

## :material-cog:&nbsp;Improve our Hardware Design
All of our designs are open-source! Please help us make it better.

- Our board design files are contained in the `/Hardware` directories of the [SparkFun GNSS mosaic-G5 P3 repository](https://github.com/sparkfun/SparkFun_GNSS_mosaic-G5_P3).

<!-- ### :material-source-pull:&nbsp;Submit a Design Enhancement -->
### Submit a Design Enhancement

1. With a GitHub account, [fork this repository](https://github.com/sparkfun/SparkFun_GNSS_mosaic-G5_P3/fork).
2. Add your design augmentation(s)
3. File a pull request with your changes, and enjoy making the ~~words~~ ~~worlds~~ world a better place.
	1. Once received, the engineer in charge of the original design will automatically be notified.
	2. We will review your suggested improvement(s) to verify that they are within our board design standards and meet our product design requirements.
	3. If approved, we will flag these changes for our next board revision. Congrats! 🍻

		!!! info
			Even if your suggestion is accepted, these changes may not be immediately available for purchase. We may have to cycle through our current product inventory first.

## Contributors&nbsp;:clap:
Let's provide some recognition to the contributors for this project!

GitHub Contributors Image
<br>


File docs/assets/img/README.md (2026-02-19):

img directory
====================
This folder should contain the images for the product documentation

## General Images
- `sfe-logo.png` - SparkFun flame logo (favicon)

## Directory
- `graphical_datasheet` - Files for graphical datasheet
- `hookup_guide` - Images for the hookup guide pages
- `qr_code` - QR code images
- `qwiic` - Images for Qwiic Banner

## QR Codes
- [QR code generator](https://qrgenerator.org/)
	- Flame Color: #E0311D
	- Frame Color: #3C464D
- [Remove meta data from svg](https://jakearchibald.github.io/svgomg/)

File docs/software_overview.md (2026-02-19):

## RxTools Software Suite
Users should install the [RXTools software suite](https://www.septentrio.com/en/products/gps-gnss-receiver-software/rxtools) on their computer to interface with the mosaic-G5 P3 GNSS receiver.

<article style="text-align: center;" markdown>
[:octicons-download-16:{ .heart } Download the RxTools Software from Septentrio](https://www.septentrio.com/en/products/gps-gnss-receiver-software/rxtools){ .md-button .md-button--primary target="blank" }
</article>

!!! info "System Requirements[^1]"

	<div class="grid cards" markdown>

	<div markdown>

	**Operating Systems**

	---

	- Windows 7
	- Windows 8
	- Windows 10
	- Fedora 23 *(or later)* using Qt technology.
		- The standalone tools (except `bin2asc`) will run on older distributions.

	</div>

	<div markdown>

	**Hardware Requirements**

	---

	The minimal hardware requirements *(1Hz update[^2])*:

	- CPU: 1 GHz processor
	- RAM: 1 GB RAM
	- Screen Resolution: 1024×768 or higher resolution

	</div>

	</div>

[^1]: The system requirements and installation instructions are from the RxTools *v22.1.0* user manual. This information may change in later iterations of the software suite. Please refer to the user manual *(of the version you are utilizing)* for the most accurate information.
[^2]: Higher data rates will require increased processing speed and memory capacity.

### Installation

=== "Windows"
	Users can install RxTools software suite by running the installation executable[^3] (`*.exe`), located in the `RxTools\windows` directory of the downloaded `*.zip` file[^4]. During the installation process, users will be notified if a previous version of RxTools is already installed then that the previous version will be uninstalled. Next, users will need to provide an installation directory for the RxTools software suite. Users will then select which of the following applications[^5] are installed:

	<!-- Create Break from Annotation (list won't render without comment)-->

	<div class="grid" markdown>

	<div markdown>

	- RxControl
	- SBF Converter
	- SBF Analyzer
	- RxLogger

	</div>

	<div markdown>

	- RxUpgrade
	- RxDownload
	- RxPlanner

	</div>

	<div markdown>

	- Data Link
	- RxAssistant
	- RxLauncher

	</div>

	</div>

=== "Linux"
	Users can install RxTools software suite by running the installation binary[^4] (`*.bin`), located in the `RxTools/linux-i386/` directory of the downloaded `*.zip` file[^4]. During the installation, users will be prompted for an installation directory. If there are any previous installations of RxControl, please use a different directory to avoid conflicts.

	!!! warning
		It is recommended that users **<span style="color:red">NOT</span>** install RxControl as `root`, for security reasons and to avoid installation overwrites of other system settings. To make RxTools available to more than one user, provide a shared installation directory.

	??? info "Permission Settings"
		Once installed, users may need to reconfigure their permission settings:

		<div class="annotate" markdown>

		- RxTools will need rights to access the `/dev/ttyS*` serial ports.

			- To access the serial ports, users must be part of the `uucp` and `lock` groups (1). This can be configured by editing the `/etc/group`[^6] file and adding the username to the lines defining the `uucp` group and the `lock` group.

				For example, when adding the user `jsmith` to the `uucp` group, users would modify the `/etc/group` file as shown below:

				```bash
				{--uucp:x:14:uucp--} # (2)!
				{++uucp:x:14:uucp,jsmith++} # (3)!
				```

			- On Linux machine administered centrally on a local network, ask your system administrator to be included in the `uucp` and `lock` groups.
		- RxTools also needs read/write (`rw`) access(4) to the `/dev/ttyS*` serial ports.

			- Users can change the permissions with the `chmod`[^7] command:

				```bash
				chmod 660 /dev/ttyS<add port> # (5)!>
				```

		</div>

		1. On most Linux operating systems, the `/dev/ttyS*` devices are owned by `root` and belong to the `uucp` group with read/write (`rw`) access. Additionally, the devices are normally locked by writing a file in the `/var/lock/` directory, with the same permissions.
		2. Remove
		3. Replace with this line
		4. By default, users will normally have read/write (`rw`) access to the `/dev/ttyS*` serial ports.
		5. where users must specify the port number<br>*e.g. `/dev/ttyS0` might be port `COM1`*

		!!! note
			In order for these changes to take effect, users must update their environment by logging out and back in.

			Be aware that the X-session has to be restarted as well. On most systems, this can be done by pressing the key combination ++ctrl++ + ++alt++ + ++backspace++

	??? tip "64-bit OS"
		In order to run the RxTools on a 64-bit Linux operating system, users might to install the 32-bit version of the `C` standard library.

		- For Fedora installations, this is the `glibc.i686` package.
		- The equivalent for Debian(/Ubuntu) installations is the `ia32-libs` package.

[^3]: Users will need administrative privileges to install the RxTools software.
[^4]: Users may need to extract the RxTools installation files from the downloaded, compressed file.
[^5]: Please see the release notes for the issues and limitations of the RxTools applications.
[^6]: Requires c privileges.
[^7]: Changing these permissions also requires `root` privileges.

## Serial Interface
Once connected through the USB interface, the mosaic-G5 P3 module emulates two virtual serial ports, which can be accessed as standard `COM` ports to the receiver.

!!! tip "Terminal Emulators"
	Most [terminal emulation programs](https://learn.sparkfun.com/tutorials/112) will not make a distinction between virtual or native COM ports. However, for virtual serial ports, the port settings *(i.e. baudrate, etc.)* are not relevant and the default configuration be used in the terminal emulation program. However, for the physical/native `COM` ports will have the following default setting:

	- Baudrate: 115200bps
	- Data Bits: 8
	- Parity: No
	- Stop Bits: 1
	- Flow Control: None

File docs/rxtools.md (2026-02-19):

!!! danger "Important: Read Before Use!"
	!!! warning "ESD Sensitivity"
		The mosaic-G5 P3 GNSS receiver is sensitive to [ESD](https://en.wikipedia.org/wiki/Electrostatic_discharge "Electrostatic Discharge"). Use a proper grounding system to make sure that the working surface and the components are at the same electric potential.

		??? info "ESD Precaution"
			As recommended by the manufacturer, we highly recommend that users take the necessary precautions to avoid damaging their GNSS receiver.

			- The All-band GNSS RTK breakout board features ESD protection on the USB-C connector and breakout's I/O:
				- USB data lines
				- I/O PTH pads
				- JST connector and BlueSMiRF header pins
			- The mosaic-G5 P3 GNSS receiver features internal ESD protection to the `ANT_1` antenna input.

			<div class="grid cards" markdown>

			<div markdown>

			<article class="video-500px" style="margin: auto;" markdown>
			<iframe src="https://www.youtube.com/embed/hrL5J6Q5gX8?si=jOPBat8rzMnL7Uz4&amp;start=26;&amp;end=35;" title="Septentrio: Getting Started Video (playback starts at ESD warning)" frameborder="0" allow="accelerometer; autoplay; clipboard-write; encrypted-media; gyroscope; picture-in-picture" allowfullscreen></iframe>
			</article>

			</div>

			-   <a href="https://www.sparkfun.com/ifixit-anti-static-wrist-strap.html">
				<figure markdown>
				Product Thumbnail
				</figure>

				---

				**iFixit Anti-Static Wrist Strap**<br>
				TOL-25572</a>

			</div>

!!! note
	The mosaic-G5 P3 GNSS receiver has numerous capabilities and a multitude of ways to configure and interface with them. Without regurgitating all the information that is documented in Septentrio's user manuals and videos, we have tried to highlight a good majority of the GNSS receiver's aspects.

	With that said, please feel free to [file an issue](github/file_issue.md/#discrepancies-in-the-documentation) if you feel we have missed something that may benefit other users. *(Don't forget to provide us with a link to the documentation and what section the information is located.)*

# RxTools Software Suite

Users should install the [RXTools software suite](https://www.septentrio.com/en/products/gps-gnss-receiver-software/rxtools)[^1] on their computer to interact with the mosaic-G5 P3 GNSS receiver through the USB interface. For Windows PCs, it also includes the USB driver for the GNSS receiver that enables the virtual `COM` ports[^2].

[^1]: The system requirements and installation instructions are from the RxTools *v22.1.0* user manual. This information may change in later iterations of the software suite. Please refer to the user manual *(of the version you are utilizing)* for the most accurate information.
[^2]: On Linux, the standard Linux CDC-ACM driver is suitable.

<article style="text-align: center;" markdown>
[:octicons-download-16:{ .heart } Download the RxTools Software from Septentrio](https://www.septentrio.com/en/products/gps-gnss-receiver-software/rxtools){ .md-button .md-button--primary target="blank" }
</article>

## System Requirements

<div class="grid" markdown>

<div markdown>

### Operating System

---

* Windows 7
* Windows 8
* Windows 10
* Fedora 23 *(or later)* using Qt technology.
	* The standalone tools (except `bin2asc`) will run on older distributions.

</div>

<div markdown>

### Hardware Requirements

---

The minimal hardware requirements *(1Hz update[^3])*:

* CPU: 1 GHz processor
* RAM: 1 GB RAM
* Screen Resolution: 1024×768 or higher resolution

</div>

</div>

[^3]: Higher data rates will require higher CPU speed and more memory capacity.

## Installation Instructions

=== "Windows"
	Users can install RxTools software suite by running the installation executable[^4](1), located in the `RxTools\windows` directory of the downloaded `*.zip` file[^5]. During the installation process, users will be notified if a previous version of RxTools is already installed then that the previous version will be uninstalled. Next, users will need to provide an installation directory for the RxTools software suite. Users will then select which of the following applications[^6] are installed:
	{ .annotate }

	1. For RxTools v22.1.0, the installation filename is `RxTools_22_1_0_Installer.exe` for Windows PCs.

	<!-- Create Break from Annotation (list won't render without comment)-->

	<div class="grid" markdown>

	<div markdown>

	* RxControl
	* SBF Converter
	* SBF Analyzer
	* RxLogger

	</div>

	<div markdown>

	* RxUpgrade
	* RxDownload
	* RxPlanner

	</div>

	<div markdown>

	* Data Link
	* RxAssistant
	* RxLauncher

	</div>

	</div>

=== "Linux[^2]"
	!!! warning
		It is recommended that users **<span style="color:red">NOT</span>** install RxControl as `root`, for security reasons and to avoid installation overwrites of other system settings. To make RxTools available to more than one user, provide a shared installation directory.

	Users can install RxTools software suite by running the installation binary[^4](1), located in the `RxTools/linux-i386/` directory of the downloaded `*.zip` file[^5]. During the installation, users will be prompted for an installation directory. If there are any previous installations of RxControl,  please use a different directory to avoid conflicts.
	{ .annotate }

	1. For RxTools v22.1.0, the installation filename is `RxTools_22_1_0_Installer.bin` for Linux.

	??? info "Permission Settings"
		Once installed, users may need to reconfigure their permission settings:

		<div class="annotate" markdown>

		* RxTools will need rights to access the `/dev/ttyS*` serial ports.

			* To access the serial ports, users must be part of the `uucp` and `lock` groups (1). This can be configured by editing the `/etc/group`[^7] file and adding the username to the lines defining the `uucp` group and the `lock` group.

				For example, when adding the user `jsmith` to the `uucp` group, users would modify the `/etc/group` file as shown below:

				```bash
				{--uucp:x:14:uucp--} # (2)!
				{++uucp:x:14:uucp,jsmith++} # (3)!
				```

			* On Linux machine administered centrally on a local network, ask your system administrator to be included in the `uucp` and `lock` groups.
		* RxTools also needs read/write (`rw`) access(4) to the `/dev/ttyS*` serial ports.

			* Users can change the permissions with the `chmod`[^8] command:

				```bash
				chmod 660 /dev/ttyS<add port> # (5)!>
				```

		</div>

		1. On most Linux operating systems, the `/dev/ttyS*` devices are owned by `root` and belong to the `uucp` group with read/write (`rw`) access. Additionally, the devices are normally locked by writing a file in the `/var/lock/` directory, with the same permissions.
		2. Remove
		3. Replace with this line
		4. By default, users will normally have read/write (`rw`) access to the `/dev/ttyS*` serial ports.
		5. where users must specify the port number<br>*e.g. `/dev/ttyS0` might be port `COM1`*

		!!! note
			In order for these changes to take effect, users must update their environment by logging out and back in.

			Be aware that the X-session has to be restarted as well. On most systems, this can be done by pressing the key combination ++ctrl++ + ++alt++ + ++backspace++

	??? info "64-bit OS"
		In order to run the RxTools on a 64-bit Linux operating system, users might to install the 32-bit version of the `C` standard library.

		* For Fedora installations, this is the `glibc.i686` package.
		* The equivalent for Debian(/Ubuntu) installations is the `ia32-libs` package.

[^4]: Users will need administrative privileges to install the RxTools software.
[^5]: Users may need to extract the RxTools installation files from the downloaded, compressed file.
[^6]: Please see the release notes for the issues and limitations of the RxTools applications.
[^7]: Requires c privileges.
[^8]: Changing these permissions also requires `root` privileges.

## Getting Started

=== "Windows"
	Once **RxTools** have been installed, any of the individual GUI tools can be launched using the **RxLauncher** application.

	When connecting to a receiver using USB, two virtual serial ports will be created on your machine which can be used to communicate to the receiver.

	* Check the Device Manager to see the exact names of these virtual serial ports.
		* They ports will appear with the name `Septentrio` written beside them.
	* These virtual serial ports will be labeled as such when **RxControl** shows the Connection Dialog.

	!!! tip
		The virtual serial port names correspond to a given USB port. When plugging the device into a different USB port, the serial port will change.

=== "Linux"
	Once **RxControl** is installed, it can be launched by executing the link created by the installation program or by executing `./runRxControl` in the directory where the program is installed.

	* The **Data Link** and **SBF Converter** applications should be executed from the `/bin` directory of the installation folder, to ensure that the proper libraries are loaded. Users can also run these applications from the installation directory, in a manner similar to **RxControl** that is described above.
	* Other applications can also be executed by launching their appropriate script.
		* For example, users can execute `./runDataLink` from the `/bin` directory, located inside the installation folder.

## Update Firmware
!!! info "Latest Firmware"
	For the latest firmware released by Septentrio, please visit their [product page](https://www.septentrio.com/en/products/gnss-receivers/gnss-receiver-modules/mosaic-G5-P3#resources) for the mosaic-G5 P3 GNSS receiver.

<div class="grid cards" markdown>

-   To check for the latest firmware published by Septentrio, please visit their [product page](https://www.septentrio.com/en/products/gnss-receivers/gnss-receiver-modules/mosaic-G5-P3#resources) for the mosaic-G5 P3 GNSS receiver. Users can click on the button below, to be redirected to the latest firmware for the mosaic-G5 P3.

	<article style="text-align: center;" markdown>
	[:septentrio: Find the Latest Firmware](https://www.septentrio.com/en/products/gnss-receivers/gnss-receiver-modules/mosaic-G5-P3#resources){ .md-button .md-button--primary target="blank" }
	</article>

-   Currently, at the time that this board was released, the firmware for the mosaic-G5 P3 GNSS receiver was *v1.0.1*[^4]. Users can download [**version 1.0.0**](./assets/component_documentation/firmware/v1.0.1/mosaic-G5%20P3_fwp_1.0.1.zip) of the firmware, by clicking on the button below.

	[^4]:
		For the latest firmware published by Septentrio, please visit their [product page](https://www.septentrio.com/en/products/gnss-receivers/gnss-receiver-modules/mosaic-G5-P3#resources).<br>
		*This is firmware version, was archived at the time that this guide was written. Please do not request for the file to be updated; instead visit the product page to download the latest firmware.*

	<article style="text-align: center;" markdown>
	[:octicons-download-16:{ .heart } Download Firmware *(v1.0.1)*](./assets/component_documentation/firmware/v1.0.1/mosaic-G5%20P3_fwp_1.0.1.zip){ .md-button .md-button--primary target="blank" }
	</article>

</div>

Below are the methods for upgrading the receiver:

1. Double click on the Septentrio firmware file with the `*.suf` extension. This should launch the **RxUpgrade** program.
2. Using the graphical interface of the **RxControl** program. Navigate to the **File** drop-down menu.
3. Manually upload the firmware file to the GNSS receiver.

### Manual Uplaod
Below are the instructions for manually uploading firmware to the GNSS receiver:

1. Enter the following command to set the receiver into upgrade mode:

	```
	exeResetReceiver, Upgrade, none <CR>
	```

2. Wait till the receiver outputs the string:

	```
	Ready for SUF download...
	```

3. From that moment on, the receiver is waiting for an upgrade file to be downloaded. The file download must start with in 200 seconds, otherwise the receiver will restart in normal mode.
3. Download the upgrade file to the receiver. Any of the receiver connections can be used. Make sure to send the file in binary mode, i.e. without changing its contents. During the download, the receiver outputs a progress indicator at regular intervals.
4. At the end of the download, the receiver automatically executes the upgrade instructions and restarts with the new firmware version. You can check the firmware version by entering the following command:

	```
	lif,Identification <CR>
	```

!!! info
	Before executing the upgrade instructions, the receiver checks the integrity of the downloaded file. If the file is corrupted, or is not a valid upgrade file, the receiver discards it and restarts in normal mode.

!!! warning
	- In some cases, upgrading the GNSS firmware can clear the receiver configuration stored in non-volatile memory. It is therefore advised to recheck the configuration after the upgrade.
	- If the download is interrupted for any reason, the receiver will restart in normal mode after a timeout period of 200 seconds.
	- Do not switch power off during the upgrade procedure.
	- Upgrading the receiver over a serial port can be very slow and it is recommended to upgrade using a faster connection whenever possible (USB).

## Enabling L5 Signals
Below, are instructions to configure the mosaic-G5 module to utilize the L5 band.

### Signal Reception
Below, are instructions to configure the mosaic-G5 module to receive the GNSS signals from the L5 band. However, these instructions can also be adapted for any of the supported GNSS signals, which aren't enabled by default.

!!! warning "`GPS-L5` Signal"
	Since the GPS-L5 service is currently pre-operational and marked as *"unhealthy"*, it takes some extra configuration steps to enable the GPS-L5 frequency band and corrections.

These commands disable the health masks to allow the L5 band to be received:

- **`setHealthMask, Tracking, off`**
- **`setHealthMask, PVT, off`**

These commands enable the tracking and use of the L5 band signals:

- **`setSignalTracking, +GPSL5`**
- **`setSignalUsage, +GPSL5, +GPSL5`**

### Output L5 Corrections
Below, are instructions for outputting RTK corrections for the GPS L5 frequency band, from the mosaic-G5.

!!! warning
	The RTK mosaic-X5 must be configured to receive those GNSS signals *(see instructions above)*; otherwise, it won't have any data to provide the corrections with.

- **`setRTCMv3Formatting, 0, +GPSL5`**

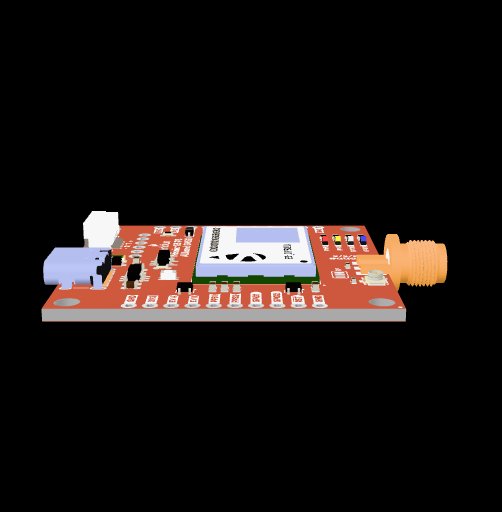
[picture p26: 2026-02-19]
docs/assets/3d_model/poster.jpeg

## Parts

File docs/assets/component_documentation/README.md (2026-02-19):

SparkFun Documentation
=======================

This directory should include any necessary datasheets, example number crunching, etc.

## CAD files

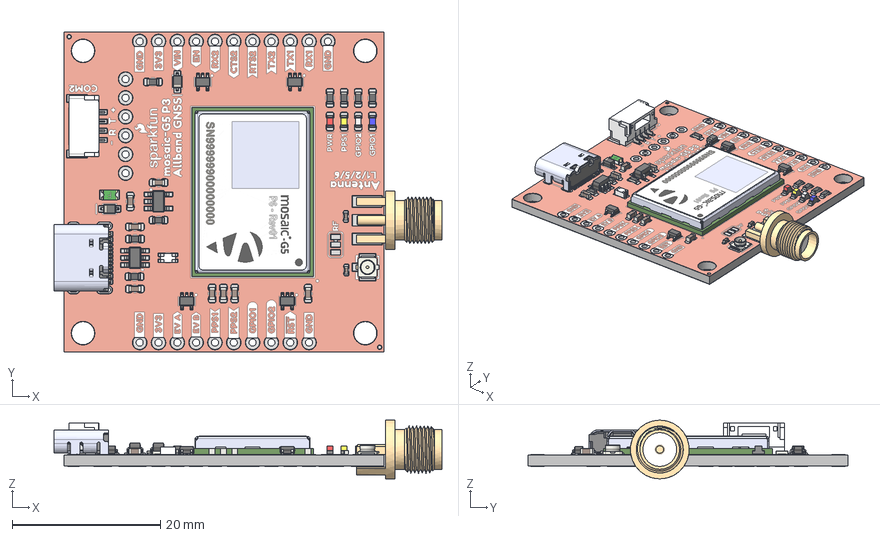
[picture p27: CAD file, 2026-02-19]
docs/assets/3d_model/cad_model.step
52.4 x 43.2 x 7.93 mm
SOT-353_SC-70-5 x 4
LED_0603_1608Metric_Yellow
R_0603_1608Metric x 8
C_0603_1608Metric x 8
USB4105GFA_USB4105GFA
D_SOD-323 x 2
JST_SMD_1.25mm-4_Locking
LED_0603_1608Metric_Red
LED_0603_1608Metric_White
C_0402_1005Metric x 2
Surface 6
Surface 5
Surface 4
Surface 3
Surface 2
Surface 1
Choke_100MHz_USB_RFCMF1220100M4T
SOT-23-5
U.FL
Fuse_0805_2012Metric
SOT-23-6
LED_0603_1608Metric_Blue
PAR-00001479
PAR-00000856
PAR-00001478
SparkFun_GNSS_mosaic-G5_P3_pad
SparkFun_GNSS_mosaic-G5_P3_silkscreen
SparkFun_GNSS_mosaic-G5_P3_soldermask
SparkFun_GNSS_mosaic-G5_P3_PCB

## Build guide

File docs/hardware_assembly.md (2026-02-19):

??? danger "Important: Read Before Use!"
	!!! warning "ESD Sensitivity"
		The mosaic-G5 P3 GNSS receiver is sensitive to [ESD](https://en.wikipedia.org/wiki/Electrostatic_discharge "Electrostatic Discharge"). Use a proper grounding system to make sure that the working surface and the components are at the same electric potential.

		??? info
			As recommended by the manufacturer, we highly recommend that users take the necessary precautions to avoid damaging their GNSS receiver.

			- The All-band GNSS RTK breakout board features ESD protection on the USB-C connector and breakout's I/O:
				- USB data lines
				- I/O PTH pads
				- JST connector and BlueSMiRF header pins
			- The mosaic-G5 P3 GNSS receiver features internal ESD protection to the `ANT_1` antenna input.

			<div markdown>

			<article class="video-500px" style="margin: auto;" markdown>
			<iframe src="https://www.youtube.com/embed/hrL5J6Q5gX8?si=jOPBat8rzMnL7Uz4&amp;start=26;&amp;end=35;" title="Septentrio: Getting Started Video (playback starts at ESD warning)" frameborder="0" allow="accelerometer; autoplay; clipboard-write; encrypted-media; gyroscope; picture-in-picture" allowfullscreen></iframe>
			</article>

			</div>

	!!! warning "Active Antenna"
		Never inject an external DC voltage into the SMA connector for the GNSS antenna, as it may damage the mosaic-G5 P3 GNSS receiver. For instance, when using a splitter to distribute the antenna signal to several GNSS receivers, make sure that no more than one output of the splitter passes DC. Use [DC-blocks](https://en.wikipedia.org/wiki/DC_block) otherwise.

## USB Programming
The USB connection is utilized for programming and serial communication. Users only need to plug their All-band GNSS RTK breakout board into a computer using a USB-C cable.

<figure markdown>
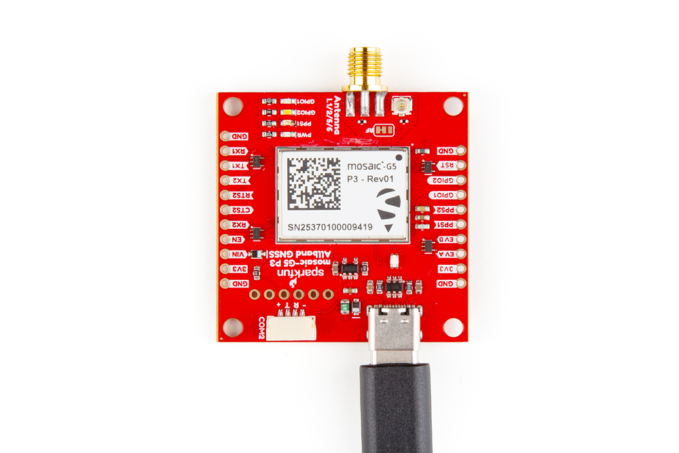
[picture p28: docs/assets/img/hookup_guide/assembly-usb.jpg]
All-band GNSS RTK breakout board USB connection

<figcaption markdown>The All-band GNSS RTK breakout board with a USB-C cable attached.</figcaption>
</figure>

!!! info
	Once connected to a computer, the mosaic-G5 P3 module emulates two virtual `COM` ports. These can be used as standard `COM` ports to communicate with the GNSS receiver.

## GNSS Antenna
In order to receive [GNSS](https://en.wikipedia.org/wiki/Satellite_navigation "Global Navigation Satellite System") signals, users will need to connect a compatible antenna. For the best performance, we recommend users choose an active, L1/L2/L5/L6 GNSS antenna and utilize a low-loss cable.

<figure markdown>
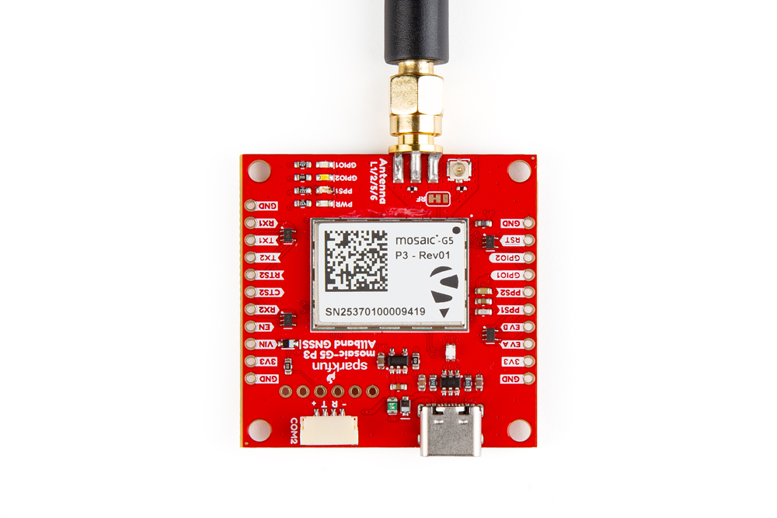
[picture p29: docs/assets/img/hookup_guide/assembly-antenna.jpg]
All-band GNSS RTK breakout board antenna connector

<figcaption markdown>Attaching a GNSS antenna to the SMA connector on the All-band GNSS RTK breakout board.</figcaption>
</figure>

!!! warning "Active Antenna"
	Never inject an external DC voltage into the SMA connector for the GNSS antenna, as it may damage the mosaic-G5 P3 GNSS receiver. For instance, when using a splitter to distribute the antenna signal to several GNSS receivers, make sure that no more than one output of the splitter passes DC. Use [DC-blocks](https://en.wikipedia.org/wiki/DC_block) otherwise.

!!! tip
	Don't forget that GNSS signals are fairly weak and can't penetrate buildings or dense vegetation. The GNSS antenna should have an unobstructed view of the sky.

## JST Connector
The JST connector on the All-band GNSS RTK board, breaks out the `COM2` UART port of the mosaic-G5 P3 GNSS receiver. In most circumstances, users will utilize the JST connector to interface with one of our [radio transceivers](https://www.sparkfun.com/sik-telemetry-radio-v3-915mhz-100mw.html) for RTK correction data.

<figure markdown>
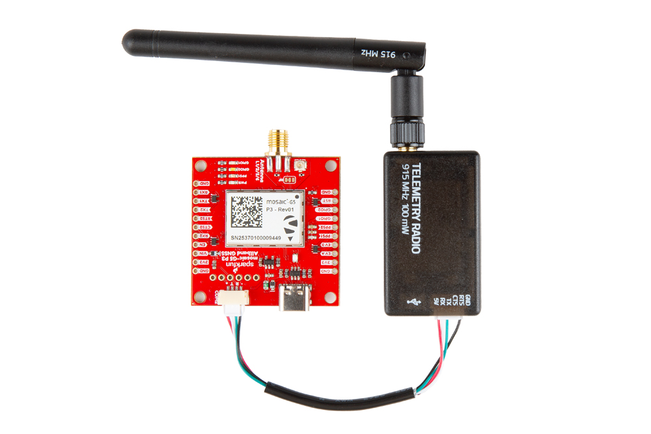
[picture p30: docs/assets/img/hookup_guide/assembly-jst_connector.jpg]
All-band GNSS RTK breakout board JST connector

<figcaption markdown>Connecting a cable to the JST connector of the All-band GNSS RTK breakout board.</figcaption>
</figure>

!!! info "Pin Connections"
	When connecting the All-band GNSS RTK breakout board to our radios, only the `RX`, `TX`, and `GND` connections are required as outlined in the table below. By default, flow control is disabled on the mosaic-G5 P3 GNSS receiver and the connections are not available through the JST connector.

	<article style="text-align: center;" markdown>

	<table markdown>
	<tr>
	<th>Board</th>
	<td align="center">RX</td>
	<td align="center">TX</td>
	<td align="center">GND</td>
	</tr>
	<tr>
	<th>Radio</th>
	<td align="center">TX</td>
	<td align="center">RX</td>
	<td align="center">GND</td>
	</tr>
	</table>

	</article>

	### All-band GNSS RTK Breakout Board
	When connecting the All-band GNSS RTK breakout board to other products, users need to be aware of the pin connections between the devices.  and voltage ranges of the products. Below, is a table of the pin connections for the JST connector on the All-band GNSS RTK breakout board.

	<div class="grid" markdown>

	<div markdown>

	<figure markdown>
	JST pins
	<figcaption markdown>The pin connections of the JST connector.</figcaption>
	</figure>

	</div>

	<div markdown>

	<article style="text-align: center;" markdown>

	<table border="1" markdown>
	<tr>
	<th style="vertical-align:middle;">Pin Number</th>
	<td align="center">
		**1**<br>
		*(Left Side)*
	</td>
	<td align="center">**2**</td>
	<td align="center">**3**</td>
	<td align="center" markdown>
		**4**<br>
		*(Right Side)*
	</td>
	</tr>
	<tr>
	<th>Label</th>
	<td align="center">`+`</td>
	<td align="center">`T`</td>
	<td align="center">`R`</td>
	<td align="center">`-`</td>
	</tr>
	<tr>
	<th style="vertical-align:middle;">Function</th>
	<td>
		<u>**Voltage Output**</u><br>
		- **Default: 3.3V**<br>
		- Selectable: 3.3V or 5V
	</td>
	<td align="center" style="vertical-align:middle;">`UART2` - Transmit</td>
	<td align="center" style="vertical-align:middle;">`UART2` - Receive</td>
	<td align="center" style="vertical-align:middle;">Ground</td>
	</tr>
	</table>

	</article>

	</div>

	</div>

	!!! danger "`VSEL` Pin"
		By default, the power pin *(i.e. `+` or Pin 1)* of the JST connector is connected to **3.3V** and configured as a power output. An input voltage can be supplied through the pin; however, users should be mindful of any voltage contention issues.

		???+ tip "Jumper"
			By default, the [`VSEL` jumper](#jumpers) is connected to `3V3` pad for a regulated 3.3V output. However, users can modify the jumper to utilize the voltage supplied from either the USB or `VIN` inputs.

	### LoRa Radios
	As documented in the [LoRaSerial product manual](https://docs.sparkfun.com/SparkFun_LoRaSerial), the pin connections between a host system *(i.e. All-band GNSS RTK breakout board)* and the LoRaSerial Kit radio is outlined in the image below.

	<figure markdown>
	Flow Control (https://docs.sparkfun.com/SparkFun_LoRaSerial/img/SAMD21%20Flow%20control.png "Click to enlarge")
	<figcaption markdown>The connections for  the LoRaSerial radio to a host system.</figcaption>
	</figure>

	Below, is a table of the pin connections for the JST connector on our radios.

	<article style="text-align: center;" markdown>

	<table border="1" markdown>
	<tr>
	<th style="vertical-align:middle;">Pin Number</th>
	<td align="center">
		**1**<br>
		*(Left Side)*
	</td>
	<td align="center">**2**</td>
	<td align="center">**3**</td>
	<td align="center">**4**</td>
	<td align="center">**5**</td>
	<td align="center">
		**6**<br>
		*(Right)*
	</td>
	</tr>
	<tr>
	<th style="vertical-align:middle;">Label</th>
	<td align="center" style="vertical-align:middle;">5V</td>
	<td>
		RX - SiK<br>
		RXI - LoRaSerial
	</td>
	<td>
		TX - SiK<br>
		TXO - LoRaSerial
	</td>
	<td align="center" style="vertical-align:middle;">CTS</td>
	<td align="center" style="vertical-align:middle;">RTS</td>
	<td align="center" style="vertical-align:middle;">GND</td>
	</tr>
	<tr>
	<th style="vertical-align:middle;">Function</th>
	<td>
		**Voltage Input**<br>
		- SiK: 5V<br>
		- LoRaSerial: 3.3 to 5V
	</td>
	<td align="center" style="vertical-align:middle;">UART - Receive</td>
	<td align="center" style="vertical-align:middle;">UART - Transmit</td>
	<td align="center" style="vertical-align:middle;">
		Flow Control<br>
		*Clear-to-Send*
	</td>
	<td align="center" style="vertical-align:middle;">
		Flow Control<br>
		*Ready-to-Send*
	</td>
	<td align="center" style="vertical-align:middle;">Ground</td>
	</tr>
	</table>

	</article>

	<!-- Markdown Table (Original)
	| Pin Number | Label              | Function                        |
	| :--------: | :----------------: | :------------------------------ |
	| 1 | V - Allband<br>5V - Radios  | **Voltage Input**<br>- Allband: 3.5 to 5.5V<br>- SiK: 5V<br>- LoRaSerial: 3.3 to 5V |
	| 2 | RX - Allband/SiK<br> RXI - LoRaSerial | UART - Receive        |
	| 3 | TX - Allband/SiK<br> TXO - LoRaSerial | UART - Transmit       |
	| 4 | C - Allband<br>CTS - Radios | Flow Control<br>*Clear-to-Send* |
	| 5 | R - Allband<br>RTS - Radios | Flow Control<br>*Ready-to-Send* |
	| 6 | G - Allband<br>GND - Radios | Ground                          |-->

## Breakout Pins
The [PTH](https://en.wikipedia.org/wiki/Through-hole_technology "Plated Through Holes") pins on the All-band GNSS RTK board are broken out into 0.1"-spaced pins on the outer edges of the board.

??? note "New to soldering?"
	If you have never soldered before or need a quick refresher, check out our [How to Solder: Through-Hole Soldering](https://learn.sparkfun.com/tutorials/how-to-solder-through-hole-soldering) guide.

	<div class="grid cards" markdown align="center">

	-   <a href="https://learn.sparkfun.com/tutorials/5">
		<figure markdown>
		Tutorial thumbnail
		</figure>

		---

		**How to Solder: Through-Hole Soldering**</a>

	</div>

<div class="grid" markdown>

<div markdown>

### Headers
When selecting headers, be sure you are aware of the functionality you require.

<figure markdown>
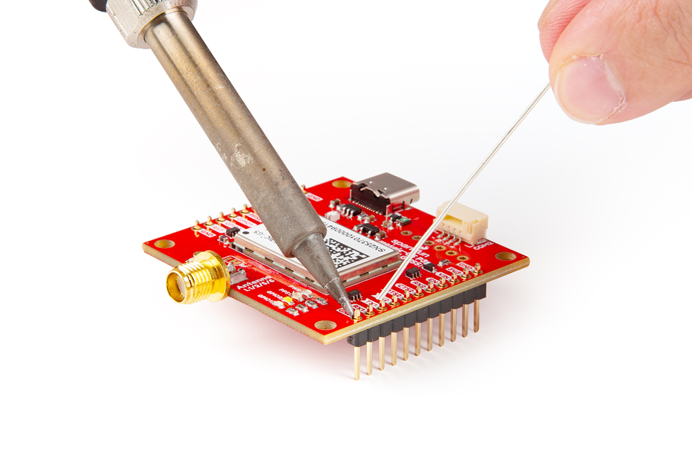
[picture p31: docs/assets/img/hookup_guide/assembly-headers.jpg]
Soldering headers

<figcaption markdown>Soldering headers to the All-band GNSS RTK breakout board.</figcaption>
</figure>

</div>

<div markdown>

### Hookup Wires
For a more permanent connection, users can solder wires directly to the board.

<figure markdown>
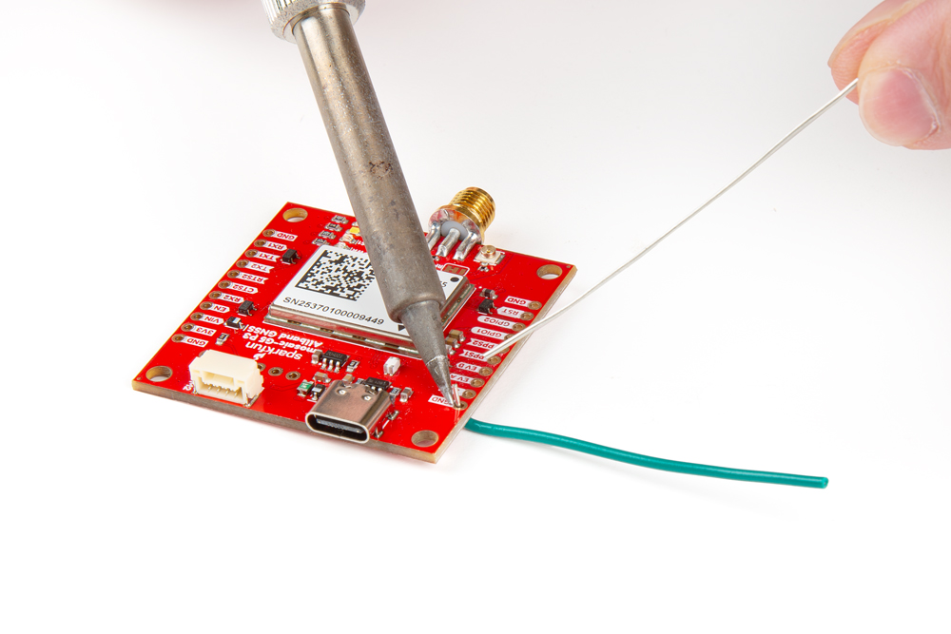
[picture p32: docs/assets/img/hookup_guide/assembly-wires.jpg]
Soldering wires

<figcaption markdown>Soldering wires to the All-band GNSS RTK breakout board.</figcaption>
</figure>

</div>

</div>

---

### BlueSMiRF Header
To pair the All-band GNSS RTK breakout board with a mobile device, users will need to connect a [BlueSMiRF v2](https://www.sparkfun.com/sparkfun-bluesmirf-v2-headers.html) to the available header pins.

<div class="grid" markdown>

<figure markdown>
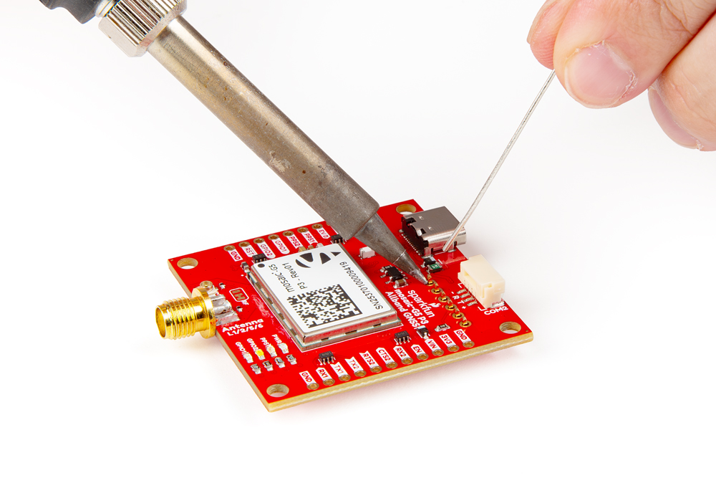
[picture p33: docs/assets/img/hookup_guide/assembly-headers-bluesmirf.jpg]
Soldering headers

<figcaption markdown>Soldering headers to the All-band GNSS RTK breakout board.</figcaption>
</figure>

<figure markdown>
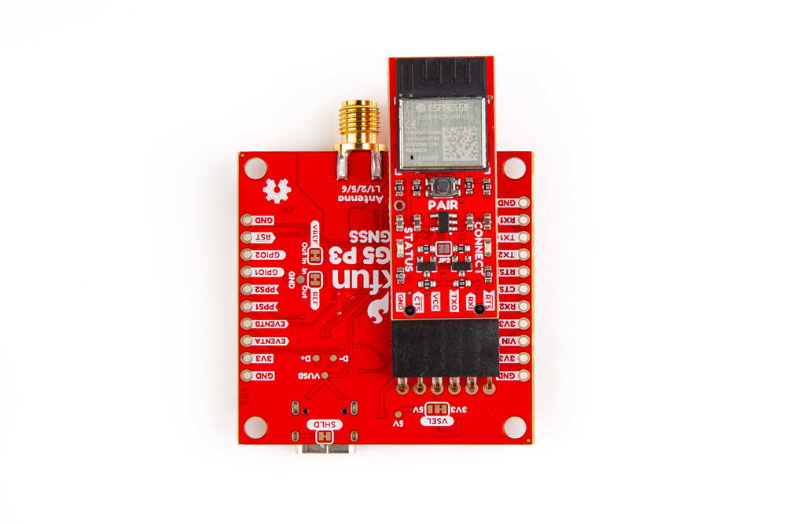
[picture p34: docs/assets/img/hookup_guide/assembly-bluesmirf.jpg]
Connecting a BlueSMiRF

<figcaption markdown>Connecting a BlueSMiRF v2 to female headers soldered on the All-band GNSS RTK breakout board.</figcaption>
</figure>

</div>

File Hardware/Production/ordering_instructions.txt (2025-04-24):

Ordering Instructions:
Panel dimensions: 115.80 x 100.56 mm.
Controlled Impedance: JLC04161H-7628
Material: TG135
Solder Mask: Red
Silkscreen Color: White
Layers: 4
Finish: ENIG
Thickness: 1.6mm
Outer Copper Weight: 1oz
Inner Copper Weight: 0.5oz
Minimum track width: 0.15mm (6.00mil)
Minimum via drill: 0.30mm (12.00mil)
No Clean Process

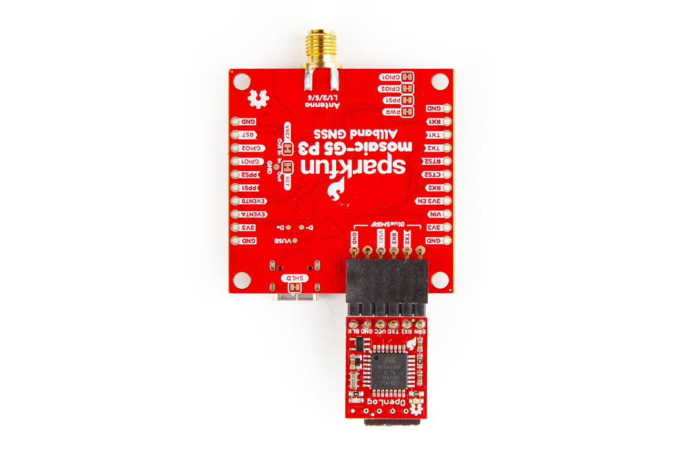
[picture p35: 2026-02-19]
docs/assets/img/hookup_guide/assembly-openlog.jpg

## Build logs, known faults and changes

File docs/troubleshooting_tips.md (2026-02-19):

!!! warning "Need Help?"
	If you need technical assistance or more information on a product that is not working as you expected, we recommend heading on over to the [SparkFun Forums](https://community.sparkfun.com).

	!!! info "Account Registration Required"
		If this is your first visit to our forum, you'll need to create a [Forum Account](https://community.sparkfun.com/signup) to post questions.

## Electrostatic Discharge
The mosaic-G5 P3 GNSS receiver is sensitive to [ESD](https://en.wikipedia.org/wiki/Electrostatic_discharge "Electrostatic Discharge"). Use a proper grounding system to make sure that the working surface and the components are at the same electric potential.

!!! warning "ESD Precaution"
	As recommended by the manufacturer, we highly recommend that users take the necessary precautions to avoid damaging their GNSS receiver.

	<div class="grid cards" markdown>

	<div markdown>

	<article class="video-500px" style="margin: auto;" markdown>
	<iframe src="https://www.youtube.com/embed/hrL5J6Q5gX8?si=jOPBat8rzMnL7Uz4&amp;start=26;&amp;end=35;" title="Septentrio: Getting Started Video (playback starts at ESD warning)" frameborder="0" allow="accelerometer; autoplay; clipboard-write; encrypted-media; gyroscope; picture-in-picture" allowfullscreen></iframe>
	</article>

	</div>

	-   - The All-band GNSS RTK breakout board features ESD protection on the USB-C connector and breakout's I/O:

			- USB data lines
			- I/O PTH pads
			- JST connector and BlueSMiRF header pins
		- The mosaic-G5 P3 GNSS receiver features internal ESD protection to the `ANT_1` antenna input.

	</div>

## GNSS Antenna

### Power Input
!!! danger "Active Antenna"
	Never inject an external DC voltage into the SMA connector for the GNSS antenna, as it may damage the mosaic-G5 P3 GNSS receiver. For instance, when using a splitter to distribute the antenna signal to several GNSS receivers, make sure that no more than one output of the splitter passes DC. Use [DC-blocks](https://en.wikipedia.org/wiki/DC_block) otherwise.

### Supported Frequency Bands
For the best performance, we recommend users choose a compatible L1/L2/L5/L6 GNSS antenna and utilize a low-loss cable. Utilizing an antenna that doesn't match all the supported frequency bands of the mosaic-G5 P3, will result in reduced performance and capabilities.

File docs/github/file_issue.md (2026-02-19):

## Need Assistance?

<!-- Technical Assistance Box -->
!!! warning "Need Help?"
	If you need technical assistance or more information on a product that is not working as you expected, we recommend heading on over to the [SparkFun Forums](https://community.sparkfun.com). The **Issues** page of the GitHub repository is not where users should seek assistance.

	!!! info "Account Registration Required"
		For your first visit to our forum, you'll need to create a [Forum Account](https://community.sparkfun.com/signup) to post questions.

## Did we make a mistake?
Spot something wrong? Please let us know. 

### Discrepancies in the Documentation
All of our documentation can be modified by you! Please help us make it better.

- The documentation files for these pages are contained in the [`docs` folder](https://github.com/sparkfun/SparkFun_GNSS_mosaic-G5_P3/tree/main/docs) of the [SparkFun GNSS mosaic-G5 P3 repository](https://github.com/sparkfun/SparkFun_GNSS_mosaic-G5_P3).

#### 🔍 Spot something wrong?
If a section of the documentation is incorrect, please [open an issue](https://github.com/sparkfun/SparkFun_GNSS_mosaic-G5_P3/issues) and let us know.

#### Do you have a suggested correction?
1. With a GitHub account, [fork this repository](https://github.com/sparkfun/SparkFun_GNSS_mosaic-G5_P3/fork).
2. Add your correction(s) or improvement(s) to the markdown file(s)
3. File a pull request with your changes, and enjoy making the ~~words~~ ~~worlds~~ world a better place.
	- Once received, the documentation specialist will automatically be notified.
	- We will review your suggested improvement(s) to make sure they are correct and fit within our documentation standards.

### Problems in the Hardware Design
All of our designs are open-source! Please help us make it better.

- Our board design files are contained in the `/Hardware` directories of the [SparkFun GNSS mosaic-G5 P3 repository](https://github.com/sparkfun/SparkFun_GNSS_mosaic-G5_P3).

#### Does something not make sense? 🤔
If part of the design is confusing, please [open an issue](https://github.com/sparkfun/SparkFun_GNSS_mosaic-G5_P3/issues) and let us know.

#### Did we forget to include an important function of the board? 🤦
If part of the board's functionality is missing, please [open an issue](https://github.com/sparkfun/SparkFun_GNSS_mosaic-G5_P3/issues) and file a feature request.

!!! tip "Design Considerations"
	Please keep in mind that we may intentionally exclude certain functions of the board to meet our product design requirements.

	- *For example, our Qwiic Micro boards are intended to fit on a small board layout and only use I^2^C communication; therefore, we may not have the SPI and interrupt pins available for users.*

#### Do you wish to contribute directly to improving the board design?

1. With a GitHub account, [fork this repository](https://github.com/sparkfun/SparkFun_GNSS_mosaic-G5_P3/fork).
2. Add your design augmentation(s)
3. File a pull request with your changes, and enjoy making the ~~words~~ ~~worlds~~ world a better place.
	1. Once received, the engineer in charge of the original design will automatically be notified.
	2. We will review your suggested improvement(s) to verify that they are within our board design standards and meet our product design requirements.
	3. If approved, we will flag these changes for our next board revision. Congrats! 🍻

		!!! info
			Even if your suggestion is accepted, these changes may not be immediately available for purchase. We may have to cycle through our current product inventory first.

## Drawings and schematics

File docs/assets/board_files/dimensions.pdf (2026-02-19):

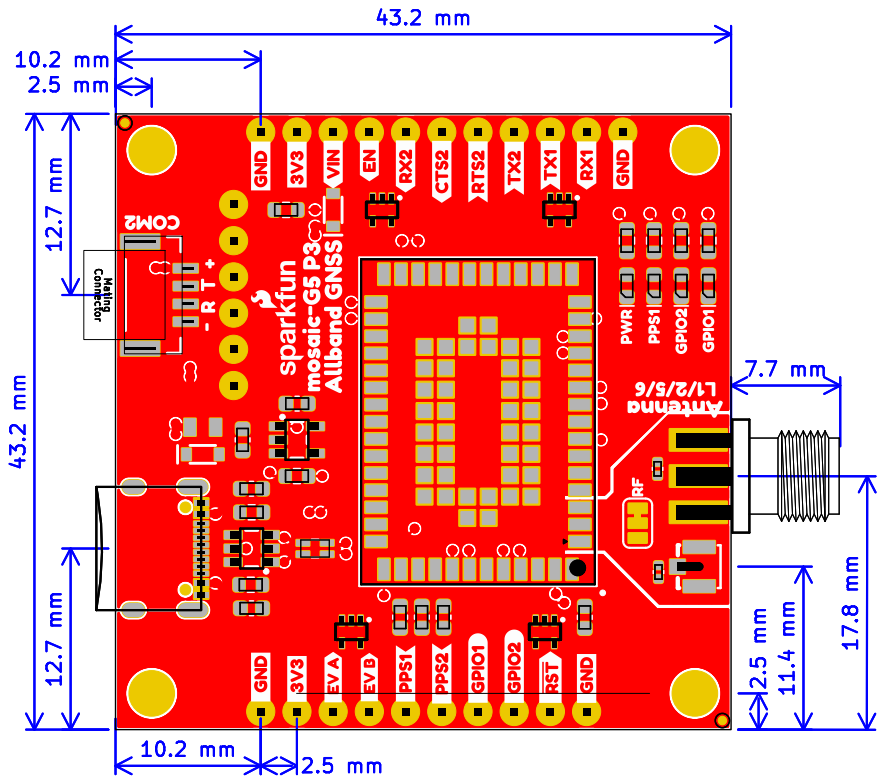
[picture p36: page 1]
17.8 mm 11.4 mm Mating Connector Mating Connector

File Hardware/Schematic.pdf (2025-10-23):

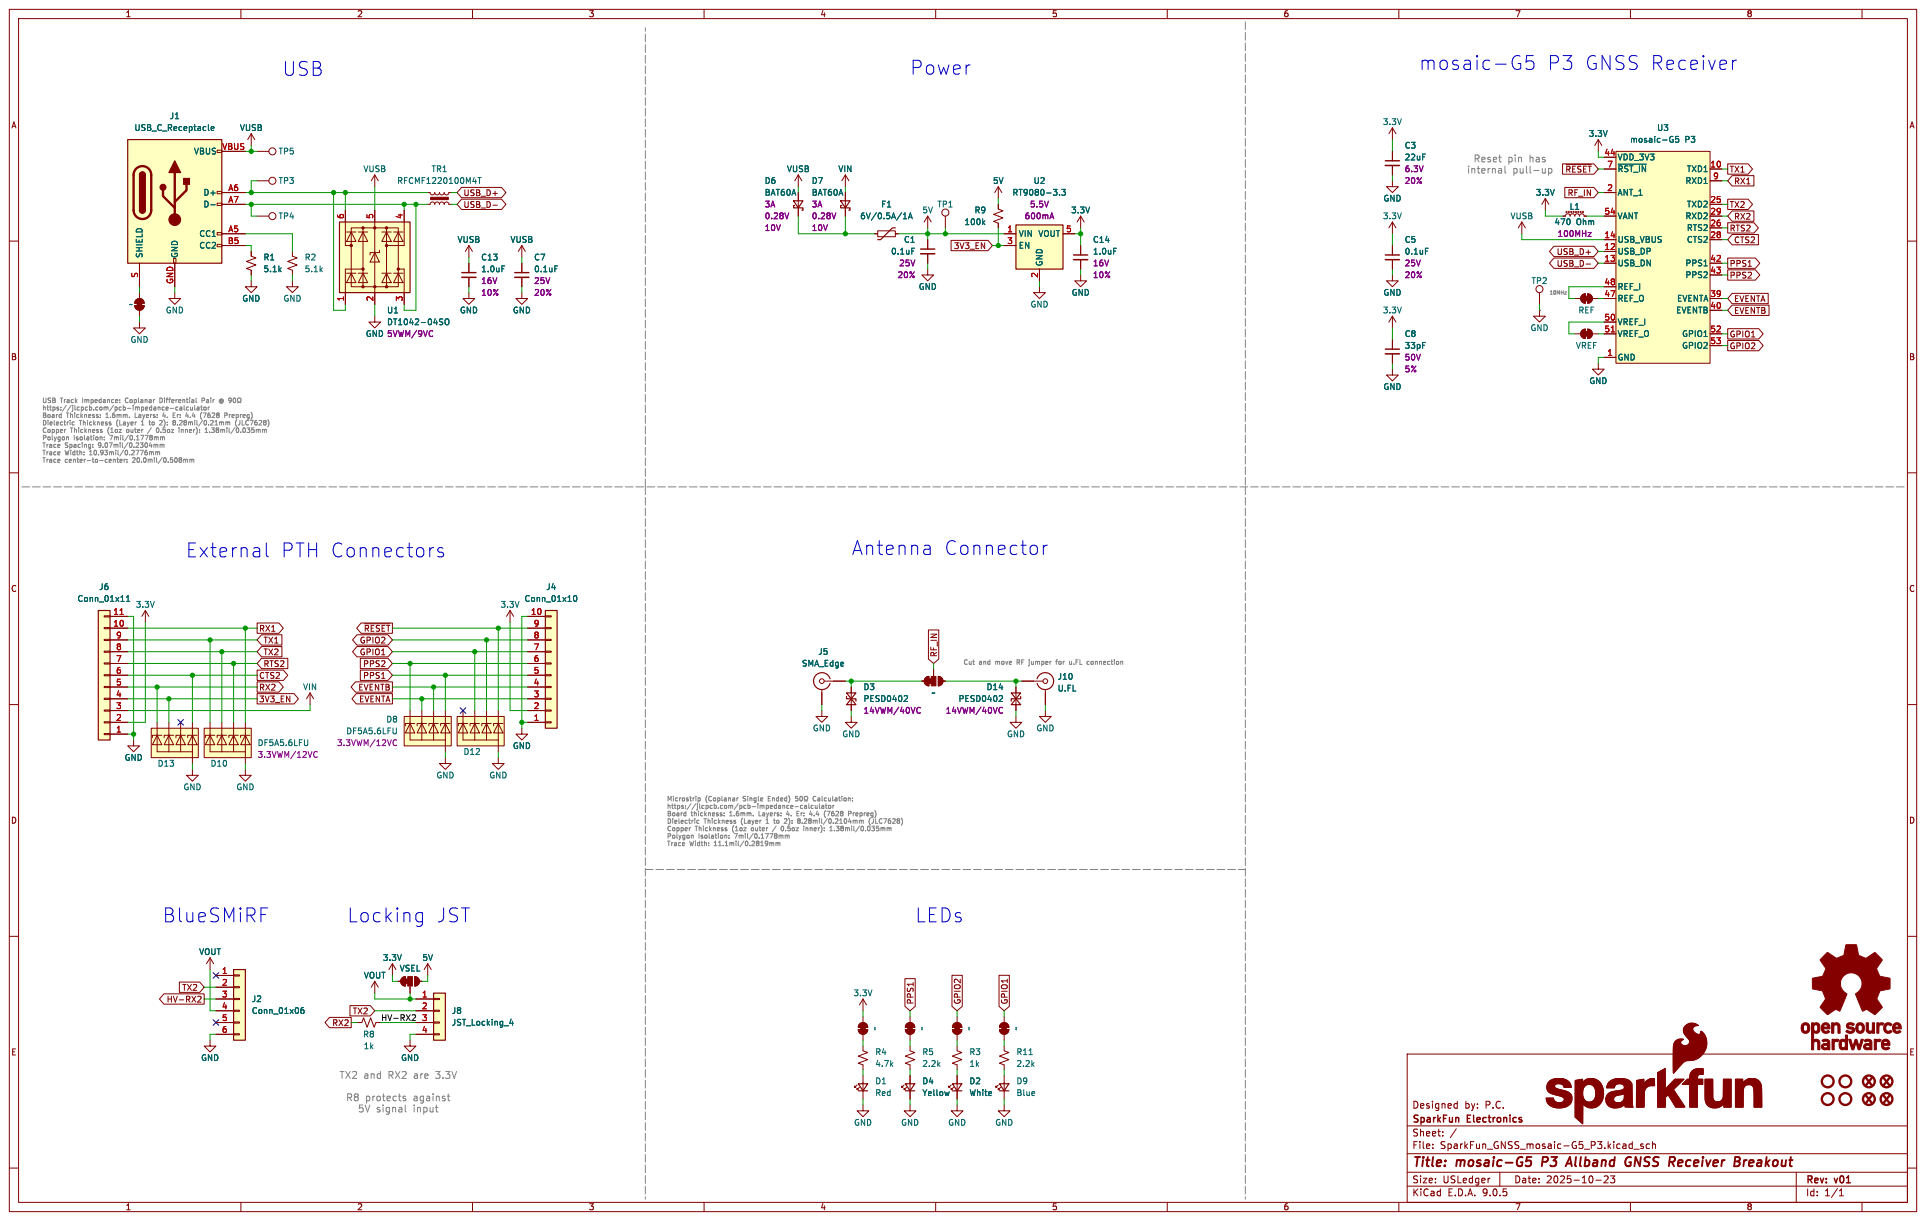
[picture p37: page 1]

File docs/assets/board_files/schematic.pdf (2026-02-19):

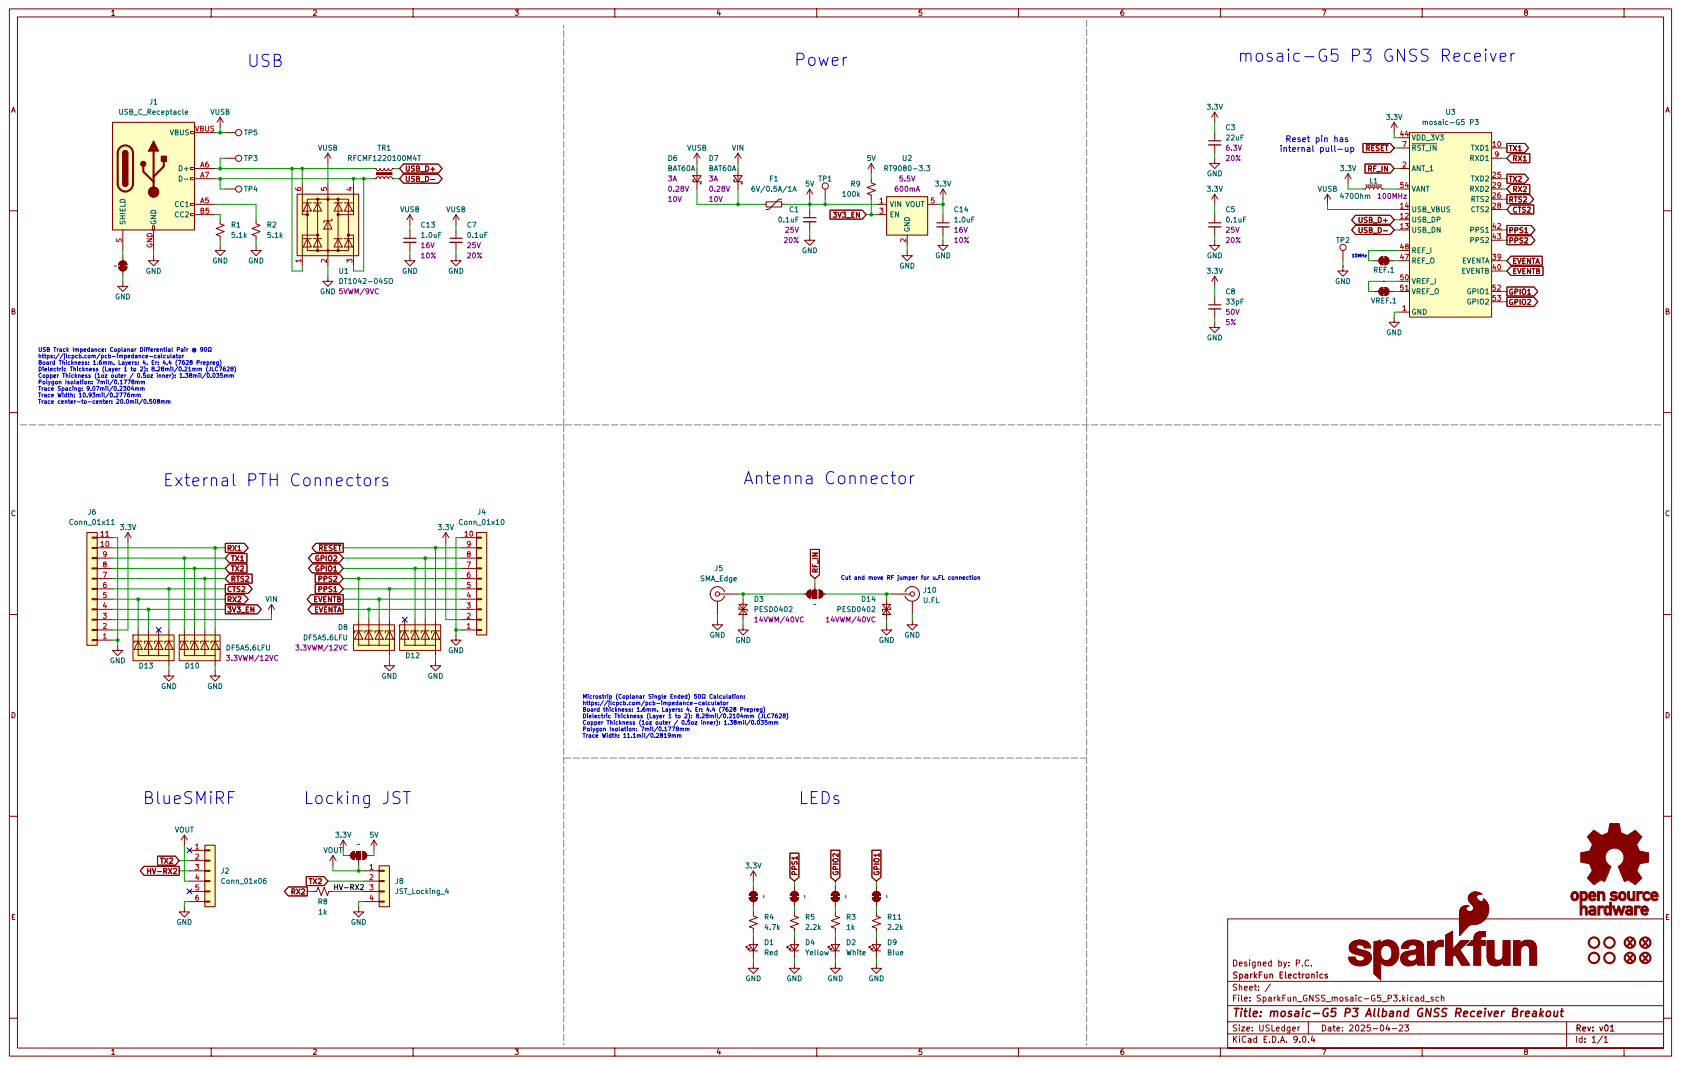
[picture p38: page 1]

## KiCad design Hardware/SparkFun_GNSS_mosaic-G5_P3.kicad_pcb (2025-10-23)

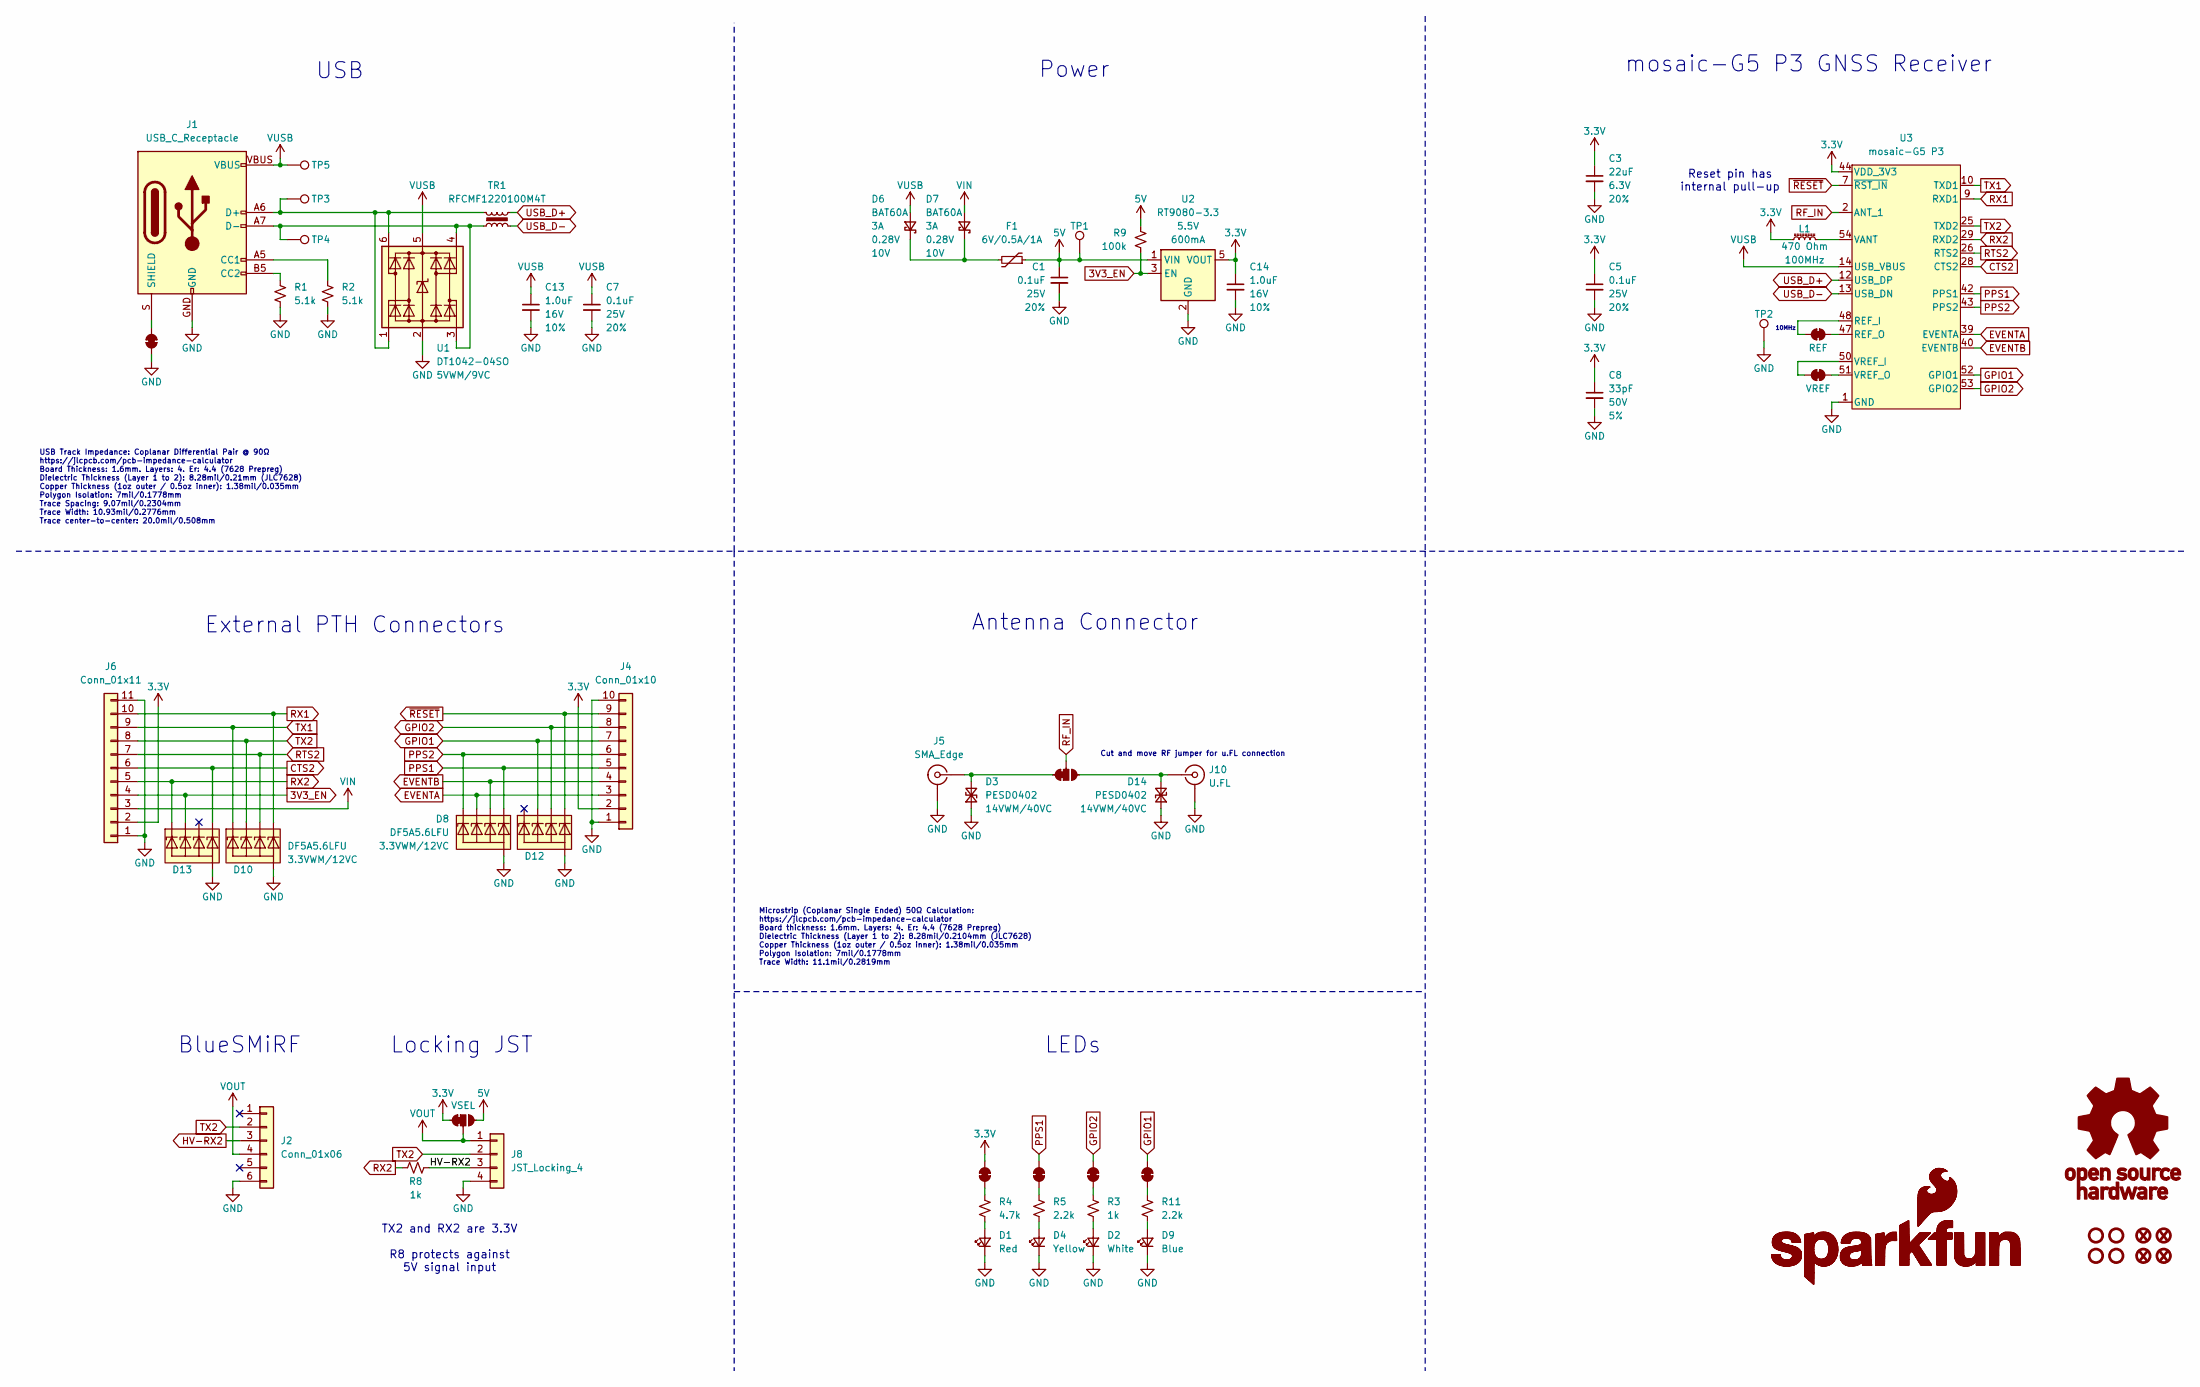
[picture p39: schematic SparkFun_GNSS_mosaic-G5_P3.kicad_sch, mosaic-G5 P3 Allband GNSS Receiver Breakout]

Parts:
C1, C5, C7: 0.1uF; C_0603_1608Metric; Voltage 25V; Tolerance 20%
C3: 22uF; C_0603_1608Metric; Voltage 6.3V; Tolerance 20%
C8: 33pF; C_0603_1608Metric; Voltage 50V; Tolerance 5%
C13, C14: 1.0uF; C_0603_1608Metric; Voltage 16V; Tolerance 10%
D1: Red; LED_0603_1608Metric_Red
D2: White; LED_0603_1608Metric_White
D3, D14: PESD0402; C_0402_1005Metric; Rating 14VWM/40VC
D4: Yellow; LED_0603_1608Metric_Yellow
D6, D7: BAT60A; SOD-323
D8, D10, D12, D13: DF5A5.6LFU; SOT-353; Rating 3.3VWM/12VC
D9: Blue; LED_0603_1608Metric_Blue
F1: 6V/0.5A/1A; 0805
FID3, FID4, FID5, FID6: Fiducial_0.5mm; Fiducial_0.5mm_Mask1mm
G1: OSHW_Logo; Creative_Commons_License
G3, G5: SparkFun_Logo
J1: USB_C_Receptacle; USB-C_16
J2: Conn_01x06; 1x06_P2.54mm
J4: Conn_01x10; 1x10_P2.54mm
J5: SMA_Edge; SMA_Edge_6.3mm
J6: Conn_01x11; 1x11_P2.54mm
J8: JST_Locking_4; JST_1x04_P1.25mm_Locking_Horizontal_SMD
J10: U.FL
JP1: Jumper_3_NC-1_Trace
JP2, JP3, JP5, JP7, JP8: Jumper_2_NC_Trace
JP4: VSEL; Jumper_3_NC-1_Trace
L1: 470 Ohm; C_0603_1608Metric
R1, R2: 5.1k; R_0603_1608Metric
R3, R8: 1k; R_0603_1608Metric
R4: 4.7k; R_0603_1608Metric
R5, R11: 2.2k; R_0603_1608Metric
R9: 100k; R_0603_1608Metric
REF.1: REF; Jumper_2_NC_Trace
ST1, ST2, ST3, ST4: Standoff
TP1, TP3, TP4, TP5: 1.0mm; TestPoint-1.0mm
TP2: 1.25mm; TestPoint-1.25mm
TR1: RFCMF1220100M4T; Choke_100MHz_USB
U1: DT1042-04SO; SOT23-6; Rating 5VWM/9VC
U2: RT9080-3.3; SOT23-5
U3: mosaic-G5 P3; Septentrio_mosaic-G5_LGA54
VREF.1: VREF; Jumper_2_NC_Trace

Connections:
3.3V: C3.1, C5.1, C8.1, C14.1, J4.2, J6.2, JP2.2 (B), JP4.1 (A), L1.1, U2.5 (VOUT), U3.44 (VDD_3V3), U3.45 (VDD_3V3)
3V3_EN: D13.3 (K2), J6.4, R9.1, U2.3 (EN)
5V: C1.1, F1.1, JP4.3 (C), R9.2, TP1.1, U2.1 (VIN)
CTS2: D13.5 (K4), J6.6, U3.28 (CTS2)
EVENTA: D8.3 (K2), J4.3, U3.39 (EVENTA)
EVENTB: D8.4 (K3), J4.4, U3.40 (EVENTB)
GND: C1.2, C3.2, C5.2, C7.2, C8.2, C13.2, C14.2, D1.1 (K), D2.1 (K), D3.1 (A1), D4.1 (K), D8.2 (A), D9.1 (K), D10.2 (A), D12.2 (A), D13.2 (A), D14.1 (A1), J1.GND, J2.6, J4.1, J4.10, J5.2 (Ext), J6.1, J6.11, J8.4, J10.2 (Ext), JP7.1 (A), R1.1, R2.1, TP2.1, U1.2 (GND), U2.2 (GND), U3.1 (GND), U3.3 (GND), U3.4 (GND), U3.6 (GND), U3.11 (GND), U3.17 (GND), U3.21 (GND), U3.27 (GND), U3.34 (GND), U3.41 (GND), U3.46 (GND), U3.49 (GND), U3.55 (GND), U3.56 (GND), U3.57 (GND), U3.58 (GND), U3.59 (GND), U3.60 (GND), U3.61 (GND), U3.62 (GND), U3.63 (GND), U3.64 (GND), U3.65 (GND), U3.66 (GND), U3.67 (GND), U3.68 (GND), U3.69 (GND), U3.70 (GND), U3.71 (GND), U3.72 (GND), U3.73 (GND), U3.74 (GND), U3.75 (GND), U3.76 (GND), U3.77 (GND), U3.78 (GND), U3.79 (GND), U3.80 (GND), U3.81 (GND), U3.82 (GND), U3.83 (GND), U3.84 (GND), U3.85 (GND), U3.86 (GND), U3.87 (GND), U3.88 (GND), U3.89 (GND), U3.90 (GND), U3.91 (GND), U3.92 (GND), U3.93 (GND), U3.94 (GND)
GPIO1: D12.3 (K2), J4.7, JP8.2 (B), U3.52 (GPIO1)
GPIO2: D12.4 (K3), J4.8, JP5.2 (B), U3.53 (GPIO2)
HV-RX2: J2.3, J8.3, R8.1
unnamed: D1.2 (A), R4.1
unnamed: D2.2 (A), R3.1
unnamed: D3.2 (A2), J5.1 (In), JP1.1 (A)
unnamed: D4.2 (A), R5.1
unnamed: D6.1 (K), D7.1 (K), F1.2
unnamed: D9.2 (A), R11.1
unnamed: D14.2 (A2), J10.1 (In), JP1.3 (C)
unnamed: J1.A5 (CC1), R2.2
unnamed: J1.B5 (CC2), R1.2
unnamed: J1.S (SHIELD), JP7.2 (B)
unnamed: JP2.1 (A), R4.2
unnamed: JP3.1 (A), R5.2
unnamed: JP5.1 (A), R3.2
unnamed: JP8.1 (A), R11.2
unnamed: REF.1.1 (A), U3.47 (REF_O)
unnamed: REF.1.2 (B), U3.48 (REF_I)
unnamed: J1.A6 (D+), J1.B6 (D+), TP3.1, TR1.3, U1.1 (I/O1), U1.6 (I/O4)
unnamed: J1.A7 (D-), J1.B7 (D-), TP4.1, TR1.1, U1.3 (I/O2), U1.4 (I/O3)
unnamed: L1.2, U3.54 (VANT)
unnamed: U3.50 (VREF_I), VREF.1.2 (B)
unnamed: U3.51 (VREF_O), VREF.1.1 (A)
PPS1: D8.5 (K4), J4.5, JP3.2 (B), U3.42 (PPS1)
PPS2: D8.1 (K1), J4.6, U3.43 (PPS2)
RF_IN: JP1.2 (B), U3.2 (ANT_1)
RTS2: D10.4 (K3), J6.7, U3.26 (RTS2)
RX1: D10.5 (K4), J6.10, U3.9 (RXD1)
RX2: D13.1 (K1), J6.5, R8.2, U3.29 (RXD2)
TX1: D10.1 (K1), J6.9, U3.10 (TXD1)
TX2: D10.3 (K2), J2.2, J6.8, J8.2, U3.25 (TXD2)
USB_D+: TR1.4, U3.12 (USB_DP)
USB_D-: TR1.2, U3.13 (USB_DN)
VIN: D7.2 (A), J6.3
VOUT: J2.4, J8.1, JP4.2 (B)
VUSB: C7.1, C13.1, D6.2 (A), J1.VBUS, TP5.1, U1.5 (VCC), U3.14 (USB_VBUS)
~RESET: D12.5 (K4), J4.9, U3.7 (~RST_IN)

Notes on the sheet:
TX2 and RX2 are 3.3V R8 protects against 5V signal input
Microstrip (Coplanar Single Ended) 50Ω Calculation: https://jlcpcb.com/pcb-impedance-calculator Board thickness: 1.6mm. Layers: 4. Er: 4.4 (7628 Prepreg) Dielectric Thickness (Layer 1 to 2): 8.28mil/0.2104mm (JLC7628) Copper Thickness (1oz outer / 0.5oz inner): 1.38mil/0.035mm Polygon Isolation: 7m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
USB Track Impedance: Coplanar Differential Pair @ 90Ω https://jlcpcb.com/pcb-impedance-calculator Board Thickness: 1.6mm. Layers: 4. Er: 4.4 (7628 Prepreg) Dielectric Thickness (Layer 1 to 2): 8.28mil/0.21mm (JLC7628) Copper Thickness (1oz outer / 0.5oz inner): 1.38mil/0.035mm Polygon Isolation: 7m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
Cut and move RF jumper for u.FL connection
BlueSMiRF
Reset pin has internal pull-up
Locking JST
10MHz
Power
Antenna Connector
LEDs
mosaic-G5 P3 GNSS Receiver
USB
External PTH Connectors

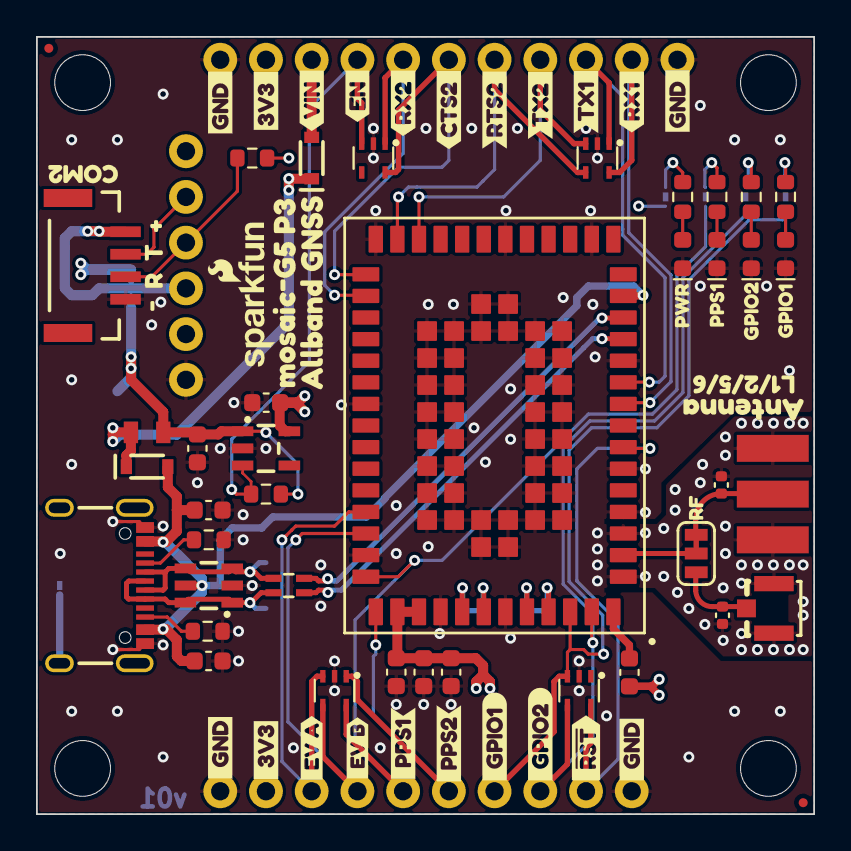
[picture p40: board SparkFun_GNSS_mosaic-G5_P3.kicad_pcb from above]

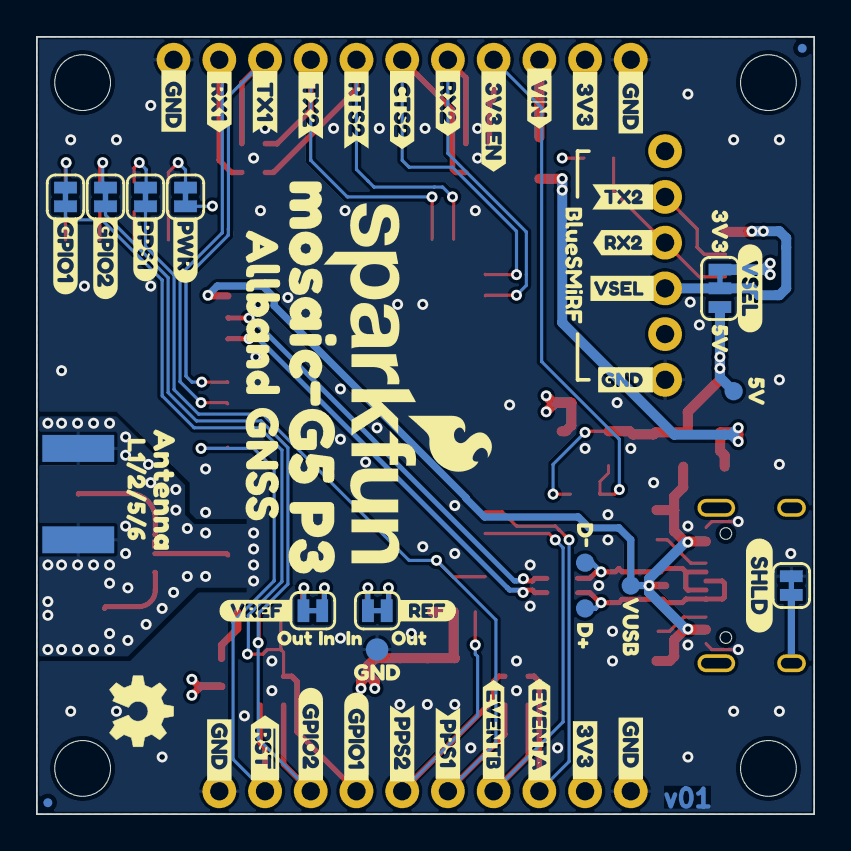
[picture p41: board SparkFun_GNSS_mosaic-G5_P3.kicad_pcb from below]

Board: 4 copper layers, 43.2 x 43.2 mm, 145 parts (65 on the bottom side), 45 nets.

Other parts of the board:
Ref**: Val**; OSHW_Logo_4mm
kibuzzard-64C3DF93: G***; kibuzzard-64C3DF93
kibuzzard-66CB82FB: G***; kibuzzard-66CB82FB
kibuzzard-66CB829C: G***; kibuzzard-66CB829C
kibuzzard-66CB830B, kibuzzard-66CB830B#2: G***; kibuzzard-66CB830B
kibuzzard-67EC56CE, kibuzzard-67EC56CE#2: G***; kibuzzard-67EC56CE
kibuzzard-67EC56E0, kibuzzard-67EC56E0#2: G***; kibuzzard-67EC56E0
kibuzzard-67EC5586: G***; kibuzzard-67EC5586
kibuzzard-67EC5701: G***; kibuzzard-67EC5701
kibuzzard-67ED9C3D: G***; kibuzzard-67ED9C3D
kibuzzard-67ED9D32: G***; kibuzzard-67ED9D32
kibuzzard-67ED93D1: G***; kibuzzard-67ED93D1
kibuzzard-680A6E0E: G***; kibuzzard-680A6E0E
kibuzzard-680A6E23: G***; kibuzzard-680A6E23
kibuzzard-680A70A3: G***; kibuzzard-680A70A3
kibuzzard-680A70AF: G***; kibuzzard-680A70AF
kibuzzard-680A70C6: G***; kibuzzard-680A70C6
kibuzzard-680A7093: G***; kibuzzard-680A7093
kibuzzard-6501FDDA: G***; kibuzzard-6501FDDA
kibuzzard-6797D0AD, kibuzzard-6797D0AD#2: G***; kibuzzard-6797D0AD
kibuzzard-6797D04A: G***; kibuzzard-6797D04A
kibuzzard-6797D04F: G***; kibuzzard-6797D04F
kibuzzard-6797D058: G***; kibuzzard-6797D058
kibuzzard-6797D071: G***; kibuzzard-6797D071
kibuzzard-68093EBD: G***; kibuzzard-68093EBD
kibuzzard-68093ED7: G***; kibuzzard-68093ED7
kibuzzard-68093EFA: G***; kibuzzard-68093EFA
kibuzzard-68093F05: G***; kibuzzard-68093F05
kibuzzard-68093F52: G***; kibuzzard-68093F52
kibuzzard-68093F83: G***; kibuzzard-68093F83
kibuzzard-68094D97: G***; kibuzzard-68094D97
kibuzzard-68094DBD: G***; kibuzzard-68094DBD
kibuzzard-68094F29: G***; kibuzzard-68094F29
kibuzzard-68094F93: G***; kibuzzard-68094F93
kibuzzard-68094FA9: G***; kibuzzard-68094FA9
kibuzzard-680915DD: G***; kibuzzard-680915DD
kibuzzard-680918A4: G***; kibuzzard-680918A4
kibuzzard-680918BB: G***; kibuzzard-680918BB
kibuzzard-680918D3: G***; kibuzzard-680918D3
kibuzzard-680918E6: G***; kibuzzard-680918E6
kibuzzard-680918FA: G***; kibuzzard-680918FA
kibuzzard-680933A4: G***; kibuzzard-680933A4
kibuzzard-680933E9: G***; kibuzzard-680933E9
kibuzzard-680934E6: G***; kibuzzard-680934E6
kibuzzard-680942C8: G***; kibuzzard-680942C8
kibuzzard-680942CE: G***; kibuzzard-680942CE
kibuzzard-680943A7: G***; kibuzzard-680943A7
kibuzzard-680943B2: G***; kibuzzard-680943B2
kibuzzard-680943F0: G***; kibuzzard-680943F0
kibuzzard-680943F9: G***; kibuzzard-680943F9
kibuzzard-680973E5: G***; kibuzzard-680973E5
kibuzzard-680973FC: G***; kibuzzard-680973FC
kibuzzard-680974A3: G***; kibuzzard-680974A3
kibuzzard-6809340B: G***; kibuzzard-6809340B
kibuzzard-6809427A, kibuzzard-6809427A#2: G***; kibuzzard-6809427A
kibuzzard-6809432A: G***; kibuzzard-6809432A
kibuzzard-6809434D: G***; kibuzzard-6809434D
kibuzzard-6809441F: G***; kibuzzard-6809441F
kibuzzard-6809448B: G***; kibuzzard-6809448B
kibuzzard-68092547: G***; kibuzzard-68092547
kibuzzard-68093375, kibuzzard-68093375#2: G***; kibuzzard-68093375
kibuzzard-68093382, kibuzzard-68093382#2: G***; kibuzzard-68093382
kibuzzard-68093452: G***; kibuzzard-68093452
kibuzzard-68093461: G***; kibuzzard-68093461
kibuzzard-68093499: G***; kibuzzard-68093499
kibuzzard-68093505: G***; kibuzzard-68093505
kibuzzard-68093510: G***; kibuzzard-68093510
kibuzzard-68094376: G***; kibuzzard-68094376
kibuzzard-68094382: G***; kibuzzard-68094382
kibuzzard-68094414: G***; kibuzzard-68094414
kibuzzard-68094456: G***; kibuzzard-68094456
kibuzzard-68094468: G***; kibuzzard-68094468
kibuzzard-68094496: G***; kibuzzard-68094496
kibuzzard-68095184: G***; kibuzzard-68095184
kibuzzard-68097087: G***; kibuzzard-68097087

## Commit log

2025-04-24 Ready for protos
    [SparkFun_GNSS_mosaic-G5_P3.kicad_pcb, SparkFun_GNSS_mosaic-G5_P3.kicad_sch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]
2025-04-24 Re-panelized with paste reduction
    [SparkFun_GNSS_mosaic-G5_P3.kicad_pcb, SparkFun_GNSS_mosaic-G5_P3.kicad_sch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]
2025-09-10 Update symbols and 3D models
    [SparkFun_GNSS_mosaic-G5_P3.kicad_pcb, SparkFun_GNSS_mosaic-G5_P3.kicad_sch]
2025-09-10 Fix RFCMF1220100M4T pin numbering
    [SparkFun_GNSS_mosaic-G5_P3.kicad_pcb, SparkFun_GNSS_mosaic-G5_P3.kicad_sch]
2025-09-10 Use updated (plotted) schematic
2025-10-23 Update to latest SparkFun KiCad Libraries
    [SparkFun_GNSS_mosaic-G5_P3.kicad_pcb, SparkFun_GNSS_mosaic-G5_P3.kicad_sch]
2026-02-19 Docs - Initial Commit
    Initial commit of the files to generate the hookup guide
    [cad_model.step]

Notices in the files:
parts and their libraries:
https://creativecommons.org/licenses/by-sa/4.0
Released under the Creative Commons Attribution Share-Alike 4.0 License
